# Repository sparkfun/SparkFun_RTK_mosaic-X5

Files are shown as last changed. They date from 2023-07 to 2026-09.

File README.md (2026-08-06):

SparkFun RTK mosaic-X5
========================================

SparkFun RTK mosaic-X5 (https://www.sparkpnt.com/products/sparkpnt-sxm-e-cors)

[*SparkFun RTK mosaic-X5 (SXM-E)*](https://www.sparkpnt.com/products/sparkpnt-sxm-e-cors)

Designed and manufactured in Boulder, Colorado, USA, the SparkFun RTK mosaic-X5 is the perfect solution for your high-precision positioning and navigation needs. Based around the multi-constellation, multi-frequency, L5-ready mosaic-X5 from Septentrio, this is our most advanced RTK product to date. It supports GNSS signals from GPS (USA), GLONASS (Russia), Beidou (China), Galileo (Europe), Navic (India) plus special additional satellites (e.g. SBAS and QZSS). The mosaic-X5 also has built-in on-module support for other L-band correction services.

The RTK mosaic-X5 can be configured as a Real Time Kinematic (RTK) Base, where it feeds corrections to other RTK Rovers, or as an RTK Rover where it can use corrections to achieve a horizontal positioning accuracy of 6 millimeters (0.6cm) (plus 0.5 PPM). For applications like robotics and autonomous systems, the mosaic-X5 can deliver position updates at 100Hz (100 times per second). The mosaic-X5 is a _very_ sophisticated chip running a full internal web page server; the position can be monitored and the module fully configured through that web page using a standard browser.

Under the hood, the RTK mosaic-X5 is based on the mosaic-X5 GNSS module from Septentrio, plus the Espressif ESP32-WROVER processor (16MB flash, 8MB PSRAM). The mosaic-X5 has USB-C connectivity (with Ethernet-over-USB), multiple UARTs and supports full Ethernet connectivity. The only interface it doesn't offer is WiFi and that's why we've included the ESP32 with its own Ethernet connection. You can connect the mosaic-X5 directly to your Ethernet network - our product supports Power-over-Ethernet too. Or you can link the mosaic-X5 Ethernet port to the ESP32 Ethernet port and have the ESP32 provide WiFi connectivity. In that mode, the ESP32 becomes an Ethernet to WiFi Bridge, seamlessly passing WiFi traffic to and from the mosaic-X5 via Ethernet.

Documentation
--------------

* **[Product Manual](http://docs.sparkfun.com/SparkFun_RTK_mosaic-X5/)** - Product manual for the RTK mosaic-X5 hosted by GitHub pages.<br>
   

*Need to download or print our hookup guide?*

* [Print *(Print to PDF)* from Single-Page View](http://docs.sparkfun.com/SparkFun_RTK_mosaic-X5/print_view)

Repository Contents
-------------------

* **[/docs](/docs/)** - Online documentation files
    * [assets](/docs/assets/) - Assets files
        * [board_files](/docs/assets/board_files/) - Files for the product design
            * [Schematic](/docs/assets/board_files/schematic.pdf) (.pdf)
            * [Dimensions](/docs/assets/board_files/dimensions.png) (.png)
            * [Eagle files](/docs/assets/board_files/eagle_files.zip) (.zip)
        * [img/hookup_guide/](/docs/assets/img/hookup_guide/) - Images for hookup guide documentation
* **[/Hardware](/Hardware/)** - Eagle design files (.brd, .sch)
* **[/Production](/Production/)** - PCB panel production files
* **[/Extruded_Case](/Extruded_Case/)** - Drawings and STEP file for the extruded case
* **[/Front_Panel](/Front_Panel/)** - Drawings and STEP file. Eagle design files (.brd, .sch) for the prototype (PCB) enclosure panel used to validate the dimensions
* **[/Rear_Panel](/Rear_Panel/)** - Drawings and STEP file. Eagle design files (.brd, .sch) for the prototype (PCB) enclosure panel used to validate the dimensions
* **[/Front_Sticker](/Front_Sticker/)** - DXF and PDF files for the front sticker
* **[/Rear_Sticker](/Rear_Sticker/)** - DXF and PDF files for the rear sticker
* **[/Firmware](/Firmware/)** - ESP IDF source code and binaries for the firmware which runs on the ESP32-WROVER
* **[/Test_Sketches](/Test_Sketches/)** - Additional code used to validate and test the RTK mosaic-X5
* **[/Documents](/Documents/)** - Component datasheets etc.

Product Variants
----------------

* [SXM-E](https://www.sparkpnt.com/products/sparkpnt-sxm-e-cors)- v1.0, Initial Release

Version History
---------------

* [v10](https://github.com/sparkfun/SparkFun_RTK_mosaic-X5/releases/tag/v10) - Initial Release

License Information
-------------------

This product is ***open source***!

Please review the [LICENSE.md](./LICENSE.md) file for license information.

If you have any questions or concerns about licensing, please contact technical support on our [SparkFun forums](https://community.sparkfun.com/).

Distributed as-is; no warranty is given.

- Your friends at SparkFun.

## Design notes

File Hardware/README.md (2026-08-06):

SparkFun RTK mosaic-X5 Design Files
=====================================

The .sch and .brd files here are Eagle CAD schematic and PCB design files from SparkFun Electronics.
A freeware version of Autodesk Eagle can be found [here](https://www.autodesk.com/products/eagle/free-download).

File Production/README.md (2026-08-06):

SparkFun RTK mosaic-X5 Production Files
=========================================

These are the production files SparkFun uses for printing PCBs.

License Information
-------------------
This product is open source!

The hardware is released under [Creative Commons ShareAlike 4.0 International](https://creativecommons.org/licenses/by-sa/4.0/).

Please use, reuse, and modify these files as you see fit. Please maintain attribution to SparkFun Electronics and release anything derivative under the same license.

Distributed as-is; no warranty is given.

- Your friends at SparkFun.

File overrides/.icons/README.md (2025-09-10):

.icons directory
====================
This folder should contain branding logos for the product documentation

## General Images
- `sfe.svg` - SparkFun flame logo
- `kicad-primary.svg` - Full KiCad logo

## Directory
- `logo` - Other available logos

## SVG Optimizer
- [Remove meta data from svg](https://jakearchibald.github.io/svgomg/)

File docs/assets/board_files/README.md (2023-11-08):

board_files directory
====================

1. A `dimensions.png` file containing the board's measurements.
2. A `schematic.pdf` file containing the board's schematics.

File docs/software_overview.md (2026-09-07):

---
icon: fontawesome/solid/computer
---

!!! code "ESP32 Firmware"
	We have intentionally kept the ESP32 firmware as simple as possible - supporting only two modes: Ethernet (mode **1**) and WiFi (mode **2**). The intention is that you can easily develop your own firmware for the RTK mosaic-X5 using the Espressif ESP IDF if the SparkFun firmware does not meet your needs.

	You can of course modify the hardware too, should you want to. The design is completely open-source.

	!!! warning "Limitations"
		The ESP32 firmware we provide is only compatible with basic `SSID` and `Password` WiFi authentication. The firmware is not compatible with networks that implement other provisioning methods such as a QR code or a [captive portal](https://en.wikipedia.org/wiki/Captive_portal).

!!! note
	The mosaic-X5 module has numerous capabilities and a multitude of ways to configure and interface with them. Without regurgitating all the information that is documented in Septentrio's user manuals and videos, we have tried to highlight a good majority of the module's aspects.

	With that said, please feel free to [file an issue](../github/file_issue/#discrepancies-in-the-documentation) if you feel we have missed something that may benefit other users. *(Don't forget to provide us with a link to the documentation and what section the information is located.)*

## :septentrio-logo:&nbsp;mosaic-X5

### RxTools Software Suite

!!! tip
	Even if you aren't necessarily interested in it, we highly recommend that users install the [RXTools software suite](https://www.septentrio.com/en/products/gps-gnss-receiver-software/rxtools) before plugging in their board. For Windows PCs, it also includes the USB driver for the module that enables the Ethernet-over-USB support and virtual `COM` ports.

Users should install the [RXTools software suite](https://www.septentrio.com/en/products/gps-gnss-receiver-software/rxtools) on their computer to interact with the mosaic-X5 module through the USB interface. The software package includes the USB-IP driver[^1] necessary to recognize the board as an ethernet device on Windows PCs (1).
{ .annotate }

1. On Linux, the standard Linux CDC-ACM driver is suitable.

[^1]: On Linux, the standard Linux CDC-ACM driver is suitable.

<article style="text-align: center;" markdown>
[:octicons-download-16:{ .heart } Download the RxTools Software from Septentrio](https://www.septentrio.com/en/products/gps-gnss-receiver-software/rxtools){ .md-button .md-button--primary target="blank" }
</article>

??? info "System Requirements[^2]"

	=== "Operating Systems"

		* Windows 7
		* Windows 8
		* Windows 10
		* Fedora 23 *(or later)* using Qt technology.
			* The standalone tools (except `bin2asc`) will run on older distributions.

	=== "Hardware Requirements"
		The minimal hardware requirements *(1Hz update[^3])*:

		* CPU: 1 GHz processor
		* RAM: 1 GB RAM
		* Screen Resolution: 1024×768 or higher resolution

	[^2]: The system requirements and installation instructions are from the RxTools *v22.1.0* user manual. This information may change in later iterations of the software suite. Please refer to the user manual *(of the version you are utilizing)* for the most accurate information.
	[^3]: Higher data rates will require higher CPU speed and more memory capacity.

??? info "Installation Instructions[^2]"

	=== "Windows"
		Users can install RxTools software suite by running the installation executable[^4](1), located in the `RxTools\windows` directory of the downloaded `*.zip` file[^5]. During the installation process, users will be notified if a previous version of RxTools is already installed then the previous version will be uninstalled. Next, users will need to provide an installation directory for the RxTools software suite. Users will then select which of the following applications[^6] are installed:
		{ .annotate }

		1. For RxTools v22.1.0, the installation filename is `RxTools_22_1_0_Installer.exe` for Windows PCs.

		<!-- Create Break from Annotation (list won't render without comment)-->

		<div class="grid" markdown>

		<div markdown>

		* RxControl
		* SBF Converter
		* SBF Analyzer
		* RxLogger

		</div>

		<div markdown>

		* RxUpgrade
		* RxDownload
		* RxPlanner

		</div>

		<div markdown>

		* Data Link
		* RxAssistant
		* RxLauncher

		</div>

		</div>

	=== "Linux[^1]"
		!!! warning
			It is recommended that users **<span style="color:red">NOT</span>** install RxControl as `root`, for security reasons and to avoid installation overwrites of other system settings. To make RxTools available to more than one user, provide a shared installation directory.

		Users can install RxTools software suite by running the installation binary[^4](1), located in the `RxTools/linux-i386/` directory of the downloaded `*.zip` file[^5]. During the installation, users will be prompted for an installation directory. If there are any previous installations of RxControl, please use a different directory to avoid conflicts.
		{ .annotate }

		1. For RxTools v22.1.0, the installation filename is `RxTools_22_1_0_Installer.bin` for Linux.

		??? info "Permission Settings"
			Once installed, users may need to reconfigure their permission settings:

			<div class="annotate" markdown>

			* RxTools will need rights to access the `/dev/ttyS*` serial ports.

				* To access the serial ports, users must be part of the `uucp` and `lock` groups (1). This can be configured by editing the `/etc/group`[^7] file and adding the username to the lines defining the `uucp` group and the `lock` group.

					For example, when adding the user `jsmith` to the `uucp` group, users would modify the `/etc/group` file as shown below:

					```bash
					{--uucp:x:14:uucp--} # (2)!
					{++uucp:x:14:uucp,jsmith++} # (3)!
					```

				* On Linux machine administered centrally on a local network, ask your system administrator to be included in the `uucp` and `lock` groups.
			* RxTools also needs read/write (`rw`) access(4) to the `/dev/ttyS*` serial ports.

				* Users can change the permissions with the `chmod`[^8] command:

					```bash
					chmod 660 /dev/ttyS<add port> # (5)!>
					```

			</div>

			1. On most Linux operating systems, the `/dev/ttyS*` devices are owned by `root` and belong to the `uucp` group with read/write (`rw`) access. Additionally, the devices are normally locked by writing a file in the `/var/lock/` directory, with the same permissions.
			2. Remove
			3. Replace with this line
			4. By default, users will normally have read/write (`rw`) access to the `/dev/ttyS*` serial ports.
			5. where users must specify the port number<br>*e.g. `/dev/ttyS0` might be port `COM1`*

			!!! note
				In order for these changes to take effect, users must update their environment by logging out and back in.

				Be aware that the X-session has to be restarted as well. On most systems, this can be done by pressing the key combination ++ctrl++ + ++alt++ + ++backspace++

		??? info "64-bit OS"
			In order to run the RxTools on a 64-bit Linux operating system, users might have to install the 32-bit version of the `C` standard library.

			* For Fedora installations, this is the `glibc.i686` package.
			* The equivalent for Debian(/Ubuntu) installations is the `ia32-libs` package.

	[^4]: Users will need administrative privileges to install the RxTools software.
	[^5]: Users may need to extract the RxTools installation files from the downloaded, compressed file.
	[^6]: Please see the release notes for the issues and limitations of the RxTools applications.
	[^7]: Requires c privileges.
	[^8]: Changing these permissions also requires `root` privileges.

### USB Driver
=== "Windows"
	If users haven't already installed the [RxTools software suite](https://www.septentrio.com/en/products/gps-gnss-receiver-software/rxtools) on their Windows PC, they will need to install the USB driver[^1] necessary to recognize and interact with the mosaic-X5 module through the USB interface.

	A Windows USB driver for the mosaic-X5 can be installed through two methods:

	<div class="annotate" markdown>

	* RxTools Software Suite (1)
	* mosaic-X5 GNSS Receiver Module (2)

	</div>

	1. The driver is installed during the installation process.
	2. The installation file for the Windows USB driver will be available from the mass-storage device when the board is initially connected to the computer.

	Once installed, the driver emulates two virtual serial ports, which can be accessed as standard `COM` ports to the receiver.

	??? tip "Terminal Emulators"
		Most [terminal emulation programs](https://learn.sparkfun.com/tutorials/112) will not make a distinction between virtual or native COM ports. However, for virtual serial ports, the port settings *(i.e. baud rate, etc.)* are not relevant and the default configuration is used in the terminal emulation program. However, the physical/native `COM` ports will have the following default setting:

		* Baudrate: 115200bps
		* Data Bits: 8
		* Parity: No
		* Stop Bits: 1
		* Flow Control: None

	??? tip "Having Trouble?"
		For users who are having trouble installing the USB driver, we have an archived version *(v3.0.2[^9])* of the installation file. Users can download [**version 3.0.2**](https://docs.sparkfun.com/SparkFun_GNSS_mosaic-X5/assets/component_documentation/driver/USB_driver_3_0_2_Installer.exe) of the driver, by clicking on the button below.

		[^9]:
			For the latest USB driver from Septentrio, please install their driver through the [RxTools software suite](../rxtools).<br>
			*This driver version was archived at the time that the [mosaic-X5 hookup guide](https://docs.sparkfun.com/SparkFun_GNSS_mosaic-X5/) was written. Please do not request for the file to be updated.*

		<article style="text-align: center;" markdown>
		[:octicons-download-16:{ .heart } Download USB Driver *(v3.0.2)*](https://docs.sparkfun.com/SparkFun_GNSS_mosaic-X5/assets/component_documentation/driver/USB_driver_3_0_2_Installer.exe){ .md-button .md-button--primary target="blank" }
		</article>

=== "Linux"
	On Linux, the standard Linux CDC-ACM driver is suitable for the mosaic-X5 module.

### Web Interface
With the USB driver installed, the mosaic-X5 module supports Ethernet-over-USB. The default IP address allocated for the Ethernet-over-USB interface is `192.168.3.1`. This IP can be entered in any browser to open a connection to the receiver's Web Interface as shown below.

<div class="grid" markdown>

<div markdown>

<figure markdown>
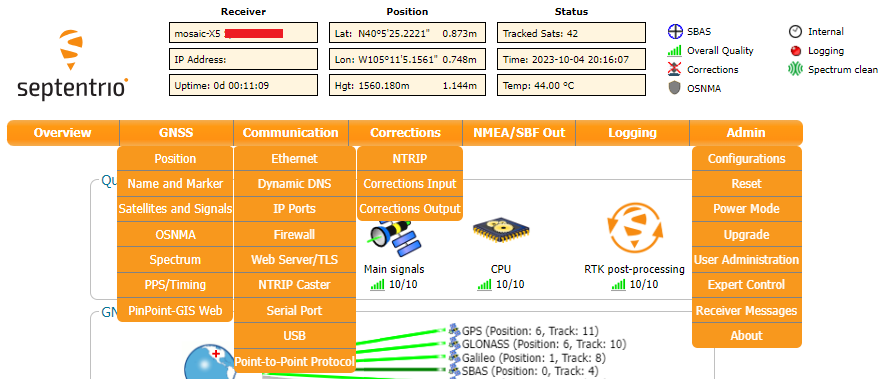
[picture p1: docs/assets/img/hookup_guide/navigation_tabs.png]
navigation tabs in the web interface

<figcaption markdown>All the drop-down navigation tabs in the web interface.</figcaption>
</figure>

</div>

<div markdown>

<article style="text-align: center;" markdown>
<article class="video-500px">
<iframe src="https://www.youtube.com/embed/hrL5J6Q5gX8" title="Septentrio: Getting started with the Septentrio mosaic receiver module" frameborder="0" allow="accelerometer; autoplay; clipboard-write; encrypted-media; gyroscope; picture-in-picture" allowfullscreen></iframe>
</article>
</article>

</div>

</div>

!!! info
	The default IP address cannot be changed; this feature is only to be used when a single receiver is connected to your computer.

??? failure "Invalid IP Address *(WiFi Only)*"
	[One of the documentation pages on Septentrio's website](https://customersupport.septentrio.com/s/article/What-is-the-default-IP-address-to-connect-via-WiFi), specifies a default IP address of `192.168.20.1` for the web interface. However, that address is for a WiFi enabled product and cannot be used with this product.

## :espressif-logo:&nbsp;ESP32

### USB Driver
Users will need to install a USB driver for the CH340 serial-to-USB chip, in order to communicate with the ESP32 module.	The latest USB drivers for the CH340 are available from the manufacturer, on the [WCH website](https://www.wch-ic.com/products/CH340.html?):

<article style="text-align: center;" markdown>
[:octicons-download-16:{ .heart } Download the latest CH340 USB driver from WCH](https://www.wch-ic.com/products/CH340.html?){ .md-button .md-button--primary target="blank" }
</article>

??? abstract "Need Directions?"
	For users having trouble installing the CH340 USB driver, check out our video and hookup guide:

	<div class="grid" markdown align="center">

	<div markdown>

	<div class="video-500px">
	<iframe src="https://www.youtube.com/embed/MM9Fj6bwHLk" title="Tutorial: Installing CH340 Drivers" frameborder="0" allow="accelerometer; autoplay; clipboard-write; encrypted-media; gyroscope; picture-in-picture" allowfullscreen></iframe>
	</div>

	</div>

	<div class="grid cards" markdown>

	-   <a href="https://learn.sparkfun.com/tutorials/908">
		<figure markdown>
		Tutorial Thumbnail
		</figure>

		---

		**How to Install CH340 Drivers**</a>

	</div>

	</div>

### Terminal Emulator
In order to configure the WiFi settings on the ESP32, users will need to install a [serial terminal emulator](https://learn.sparkfun.com/tutorials/terminal-basics) on their computer.

=== "Windows"
	For Windows computers, we highly recommend [TeraTerm](https://teratermproject.github.io/index-en.html).

=== "Linux"
	Some Linux operating systems will already have the `screen` terminal emulator preinstalled.

!!! abstract "Need Directions?"
	Check out our hookup guide to install your favorite terminal emulator:

	<div class="grid cards" markdown align="center">

	-   <a href="https://learn.sparkfun.com/tutorials/112">
		<figure markdown>
		Tutorial Thumbnail
		</figure>

		---

		**Serial Terminal Basics**</a>

	</div>

### WiFi Credentials for the Network Bridge
With the CH340 USB driver and a terminal emulator installed, users will now be able to configure the WiFi credentials on the ESP32. In order for the firmware to operate properly, users should have their RTK mosaic-X5 assembled with the network bridge in *WiFi Mode*.

--8<-- "./docs/quick_start.md:135:138"

`1` - **Open a Serial Terminal**
: Open the connection to the CH340 using a baud rate of **115200bps**

`2` - **Put the ESP32 firmware into WiFi mode**
--8<-- "./docs/quick_start.md:181:252"

Once the mosaic-X5 has acquired a satellite signal and is connected to the WiFi network, the OLED will display the antenna's position as Latitude (Lat), Longitude (Long) and Altitude (Alt); the WiFi IP (Internet Protocol) network address. The firmware mode, SSID and password are stored in flash (non-volatile) memory. After changing them, you can disconnect the computer and power the RTK mosaic-X5 using the supplied wall adapter.

--8<-- "./docs/quick_start.md:263:266"

!!! info
	When powering the RTK mosaic-X5 on for the first time, you may see the firmware restart (reboot) several times while it waits for the mosaic-X5 to initialize. This is not an error or anything to be concerned about.

With the RTK mosaic-X5 operating with the configured WiFi network bridge, users should be able to open a web browser on any connected device and navigate to the IP address shown on the OLED display. The browser should be able to access the mosaic-X5's internal web page, where users can configure the mosaic-X5.

### ESP32 Firmware - Update

The firmware running on the ESP32 is based heavily on the firmware for the [Septentrio mowi](https://github.com/septentrio-gnss/mowi). SparkFun added some bells and whistles, primarily to support the OLED display. The full firmware source code is available in the [GitHub repo](https://github.com/sparkfun/SparkFun_RTK_mosaic-X5/tree/main/Firmware/RTK_mosaic-X5_Firmware). It was developed and compiled with the Espressif ESP-IDF version 5.1.7.

The most recent version of the firmware is v1.0.6, released on September 7th 2026. If you purchased your RTK mosaic-X5 before this date, you may enjoy the improvements in v1.0.6. Please see the [change_log](./change_log.md) or [releases](https://github.com/sparkfun/SparkFun_RTK_mosaic-X5/releases) for more details.

To upgrade the ESP32 firmware, using a Windows PC:

* Download the complete RTK mosaic-X5 repo as a Zip file:
    * [https://github.com/sparkfun/SparkFun_RTK_mosaic-X5/archive/refs/heads/main.zip](https://github.com/sparkfun/SparkFun_RTK_mosaic-X5/archive/refs/heads/main.zip)
* Alternatively, download the latest or a previous release (*Source code zip*) from the [repo releases page](https://github.com/sparkfun/SparkFun_RTK_mosaic-X5/releases)
* Unzip the Zip file (Extract All)
* Open a *Command Prompt* and navigate into the *Firmware* sub-folder
* Connect the RTK mosaic-X5 “CONFIG ESP32” port to your PC using a USB-C cable
    * It should appear in Device Manager as a CH340 COM port
* Run *ESP32_FLASH_ERASE.bat* to completely clear the ESP32 memory
    * The .bat file should find the COM port number for you
	* If you see the error ```'wmic' is not recognized as an internal or external command, operable program or batch file```, you will need to [install WMIC](https://techcommunity.microsoft.com/blog/windows-itpro-blog/how-to-install-wmic-feature-on-demand-on-windows-11/4189530) or provide the COM port manually:

```
ESP32_FLASH_ERASE.bat COM1
```

* If you need to run `esptool` manually, use the following replacing COM1 with your COM port:

```
esptool.exe --chip esp32 -p COM1 -b 460800 erase_flash
```

* Then run *ESP32_FLASHER.bat* to upload the firmware
	* The .bat file should find the COM port number for you
	* If you see the error ```'wmic' is not recognized as an internal or external command, operable program or batch file```, you will need to [install WMIC](https://techcommunity.microsoft.com/blog/windows-itpro-blog/how-to-install-wmic-feature-on-demand-on-windows-11/4189530) or provide the COM port manually:

```
ESP32_FLASHER.bat COM1
```

* If you need to run `esptool` manually, use:

```
esptool.exe --chip esp32 -p COM1 -b 460800 --before=default_reset --after=hard_reset write_flash --flash_mode dio --flash_freq 40m --flash_size 4MB 0x1000 RTK_mosaic-X5_Firmware\build\bootloader\bootloader.bin 0x10000 RTK_mosaic-X5_Firmware\build\RTK_mosaic-X5_Firmware.bin 0x8000 RTK_mosaic-X5_Firmware\build\partition_table\partition-table.bin
```

On Linux / MacOS, you can `pip install esptool` and then run the above commnds, replacing `esptool.exe` with `esptool`

### ESP32 Firmware - Compiling from source

This is information about how to compile the RTK mosaic-X5 firmware from source. This is for advanced users who would like to modify the functionality of this RTK product.

* [How SparkFun does it](#how-sparkfun-does-it)
* [Using Docker](#using-docker)

### How SparkFun does it

At SparkFun, we use GitHub Actions and a Workflow to compile each release of the RTK mosaic-X5 firmware. We run the [build-for-release workflow](https://github.com/sparkfun/SparkFun_RTK_mosaic-X5/blob/main/.github/workflows/build-for-release.yml) directly on GitHub. A virtual ubuntu machine installs the Espressif IDF and generates the firmware binary for the ESP32. The updated firmware, bootloader and partition-table .bin files are pushed to the repo. We then create the new release manually.

You are welcome to clone or fork this repo and do the exact same thing yourself. But you may need a paid GitHub Pro account to run the GitHub Actions, especially if you keep your clone / fork private.

The [non-release-build workflow](https://github.com/sparkfun/SparkFun_RTK_mosaic-X5/blob/main/.github/workflows/non-release-build.yml) builds the firmware binaries and attaches them as an Artifact to the workflow run. Navigate to Actions \ Non-Release Build, select the latest run of Non-Release Build, the binary files are in the Artifact. This may be useful if you want to build the firmware on GitHub but don't want the changes pushed to your repo.

You can then use (e.g.) [ESP32_FLASHER.bat](https://github.com/sparkfun/SparkFun_RTK_mosaic-X5/blob/main/Firmware/ESP32_FLASHER.bat) to upload the binary onto the ESP32.

### Using Docker

Here is a step-by-step guide for how to install Docker and compile the firmware locally from scratch:

#### Clone, fork or download the RTK mosaic-X5 repo

To build the RTK mosaic-X5 firmware, you obviously need a copy of the source code.

If you are familiar with Git and GitHub Desktop, you can clone the RTK mosaic-X5 repo directly into GitHub Desktop:

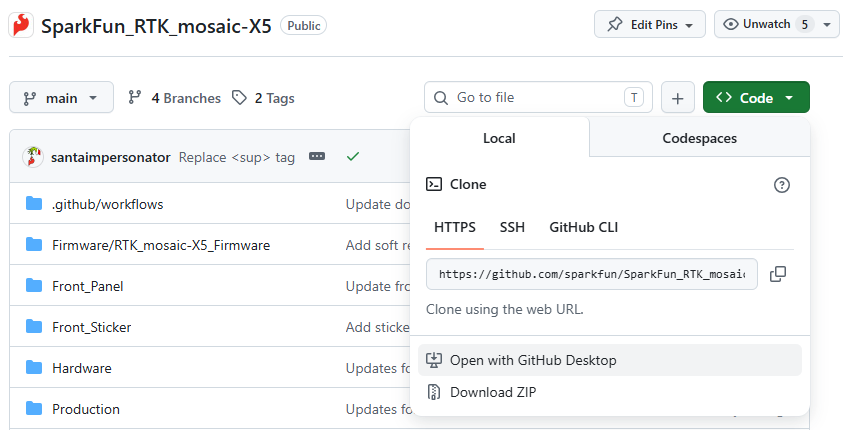
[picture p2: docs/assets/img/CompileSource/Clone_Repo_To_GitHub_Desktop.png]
Clone RTK mosaic-X5 with GitHub Desktop


If you want to _contribute_ to RTK Everywhere, and already have a GitHub account, you can Fork the repo:

Fork RTK Everywhere

Clone your fork to your local machine, make changes, and send us a Pull Request. This is exactly what the SparkFun Team do when developing the code. Please use the `release_candidate` branch for any such changes. We are very unlikely to merge anything directly into `main`, unless it is (e.g.) docs corrections or improvements.

If you don't want to do either of those, you can simply Download a Zip copy of the repo instead. You will receive a complete copy as a Zip file. You can do this from the green **Code** button, or click on the icon below to download a copy of the main (released) branch:

Download ZIP (https://github.com/sparkfun/SparkFun_RTK_mosaic-X5/archive/refs/heads/main.zip "Download ZIP (main branch)")

For the real Wild West experience, you can also download a copy of the `release_candidate` code branch. This is where the team is actively changing and testing the code, before it becomes a full release. The code there will _usually_ compile and will _usually_ work, but we don't guarantee it! We may be part way through implementing some breaking changes at the time of your download...

Download ZIP - release candidate (https://github.com/sparkfun/SparkFun_RTK_mosaic-X5/archive/refs/heads/release_candidate.zip "Download ZIP (release_candidate branch)")

#### Install Docker Desktop

* **(Optional)** Head to [Docker](https://www.docker.com/) and create an account. A free "Personal" account will cover occasional compilations of the firmware
* Download and install [Docker Desktop](https://docs.docker.com/get-started/get-docker/) - there are versions for Mac, Windows and Linux. You may need to restart to complete the installation.
* Run the Desktop
    * You don't _need_ to have an account and you don't _need_ to be signed in
    * You only need to be signed in if you want to store or share your Container on Docker Hub
    * If you don't sign in, Docker Desktop will run in Personal mode - which will cover local compilations of the firmware
* On Windows, you may see an error saying "**WSL needs updating** Your version of Windows Subsystem for Linux (WSL) is too old". If you do:
    * Open a command prompt
	* Type `wsl --update` to update WSL. At the time of writing, this installs Windows Subsystem for Linux 2.6.1
	* Restart the Docker Desktop
* If you are using Docker for the first time, the "What is a container?" and "How do I run a container?" demos are useful - _but not essential_
    * On Windows, you may want to give Docker Desktop permission to access to your Network, so it can access (e.g.) HTML ports
	* You can Stop the container and Delete it when you are done
* You may want to prevent Docker from running when your machine starts up
    * Uncheck "Start Docker Desktop when you sign in to your computer" in the Desktop settings

#### Using Docker to create the firmware binary

* **Make sure you have Docker Desktop running.** You don't need to be signed in, but it needs to be running.
* Open a Command Prompt and `cd` into the SparkFun_RTK_mosaic-X5 folder
* Check you are in the right place. Type `dir` and hit enter. You should see the following files and folders:

```
    .gitattributes
    .gitignore
    CONTRIBUTING.md
    ISSUE_TEMPLATE.md
    LICENSE.md
	mkdocs.yml
    README.md
```

* `cd Firmware` and then `dir` again. You should see:

```
    RTK_mosaic-X5_Firmware
	compile_run_terminal.bat
	compile_with_docker.bat
    Dockerfile
    ESP32_FLASH_ERASE.bat
    ESP32_FLASHER.bat
    esptool.exe
```

* The file that does most of the work is the `Dockerfile`

* Run `compile_with_docker.bat`. It does everything for you:

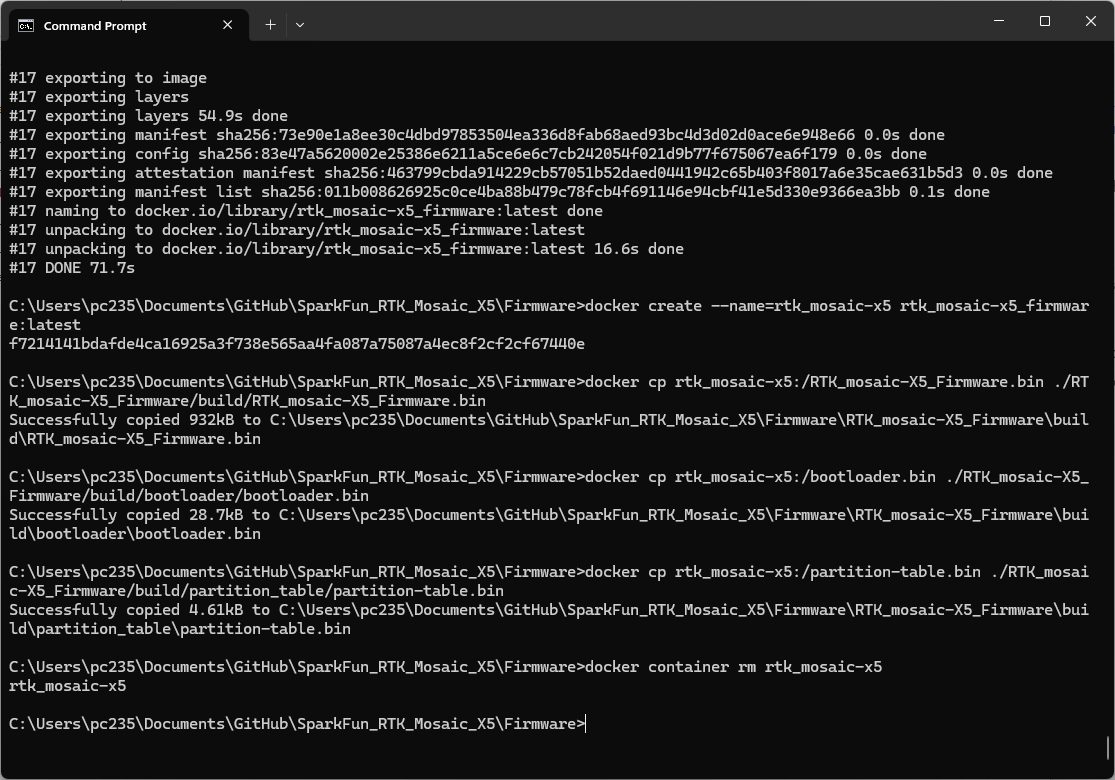
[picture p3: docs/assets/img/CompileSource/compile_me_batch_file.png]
Output of the compile batch file


* Hey presto! You have your newly compiled firmware binary!
* The three new files are:
	* **RTK_mosaic-X5_Firmware\build\RTK_mosaic-X5_Firmware.bin**
	* **RTK_mosaic-X5_Firmware\build\bootloader\bootloader.bin**
	* **RTK_mosaic-X5_Firmware\build\partition_table\partition-table.bin**

You can then use (e.g.) [ESP32_FLASHER.bat](https://github.com/sparkfun/SparkFun_RTK_mosaic-X5/blob/main/Firmware/ESP32_FLASHER.bat) to upload the binary onto the ESP32.

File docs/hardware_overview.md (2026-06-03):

---
icon: material/cog
---

!!! warning "Read Before Handling PCB!"
	!!! danger "ESD Sensitivity"
		The mosaic-X5 module is sensitive to [ESD](https://en.wikipedia.org/wiki/Electrostatic_discharge "Electrostatic Discharge"). Use a proper grounding system to make sure that the working surface and the components are at the same electric potential.

	??? info "ESD Precaution"
		As recommended by the manufacturer, we highly encourage users to take the necessary precautions to avoid damaging their module.

		- The RTK mosaic-X5 features ESD protection on the USB-C connectors and ethernet jacks.
		- The mosaic-X5 module features internal ESD protection to the `ANT_1` antenna input.

		<div class="grid cards" markdown>

		<div markdown>

		<article style="text-align: center;" markdown>
		<article class="video-500px">
		<iframe src="https://www.youtube.com/embed/hrL5J6Q5gX8?si=jOPBat8rzMnL7Uz4&amp;start=26;&amp;end=35;" title="Septentrio: Getting Started Video (playback starts at ESD warning)" frameborder="0" allow="accelerometer; autoplay; clipboard-write; encrypted-media; gyroscope; picture-in-picture" allowfullscreen></iframe>
		</article>
		</article>

		</div>

		-   <a href="https://www.sparkfun.com/ifixit-anti-static-wrist-strap.html">
			<figure markdown>
			Product Thumbnail
			</figure>		

			---

			**iFixit Anti-Static Wrist Strap**<br>
			TOL-25572</a>

		</div>

!!! code "ESP32 Firmware"
	We have intentionally kept the ESP32 firmware as simple as possible - supporting only two modes: Ethernet *(**Mode: `1`**)* and WiFi *(**Mode: `2`**)*. The intention is that you can easily develop your own firmware for the RTK mosaic-X5 using the Espressif ESP IDF if the SparkFun firmware does not meet your needs.

	You can of course modify the hardware too, should you want to. The design is completely open-source.

	!!! warning "Limitations"
		The ESP32 firmware we provide is only compatible with basic `SSID` and `Password` WiFi authentication. The firmware is not compatible with networks that implement other provisioning methods such as a [captive portal](https://en.wikipedia.org/wiki/Captive_portal), a QR code, or [Wi-Fi protected setup](https://en.wikipedia.org/wiki/Wi-Fi_Protected_Setup "WPS").

# Hardware Overview

In this section, we walk you through the hardware design, interfaces, I/O connections, power options and more.

!!! info
	The RTK mosaic-X5 is inspired by the [Septentrio mowi (mosaic wireless) open-source design](https://github.com/septentrio-gnss/mowi). The SparkFun design builds upon [mowi](https://github.com/septentrio-gnss/mowi "mosaic wireless"), adding: separate Ethernet ports with mag jacks and Power-over-Ethernet; robust I/O headers with screw cage connections and configurable I/O voltage (3.3V or 5V); &micro;SD data storage; and an OLED display.

## Schematic
Users can download the [full schematic for the RTK mosaic-X5](./assets/board_files/schematic.pdf) in `*.pdf` format.

## Dimensions

=== ":material-package-variant-closed: Metal Enclosure"
	Details about the aluminum enclosure can be found on the [Metal Enclosure - Custom Aluminum Extrusion (6in. x 4in. PCB)](https://www.sparkfun.com/metal-enclosure-custom-aluminum-extrusion-6in-x-4in-pcb.html) product page.

	<figure markdown>
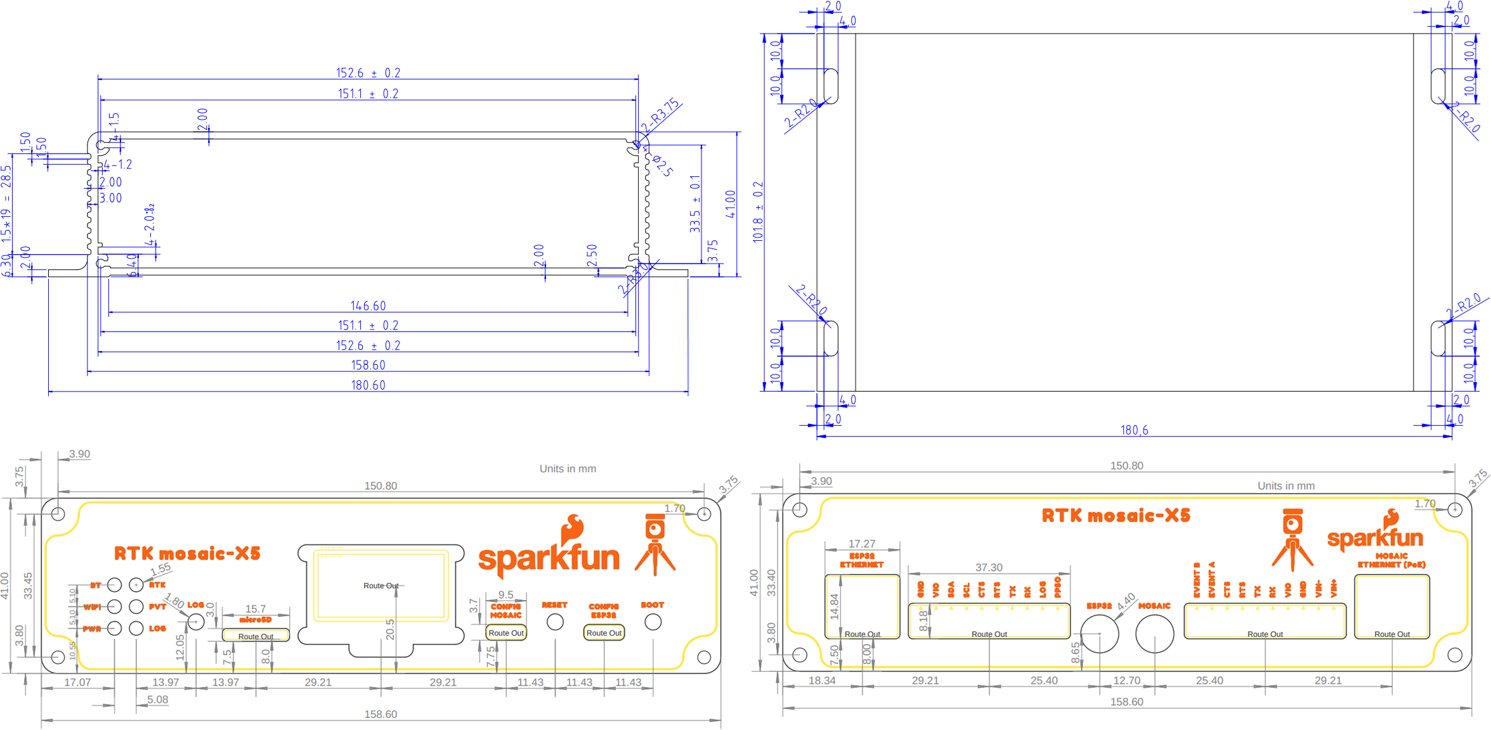
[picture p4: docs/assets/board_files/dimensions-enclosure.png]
Enclosure Dimensions
	
	<figcaption markdown>[Dimensions (PDF)](./assets/board_files/dimensions-enclosure.pdf) of the RTK mosaic-X5 aluminum enclosure and the front/rear panels, in millimeters.</figcaption>
	</figure>

=== ":fontawesome-solid-microchip: Printed Circuit Board"
	The circuit board dimensions are illustrated in the drawing below; the listed measurements are in inches.

	<figure markdown>
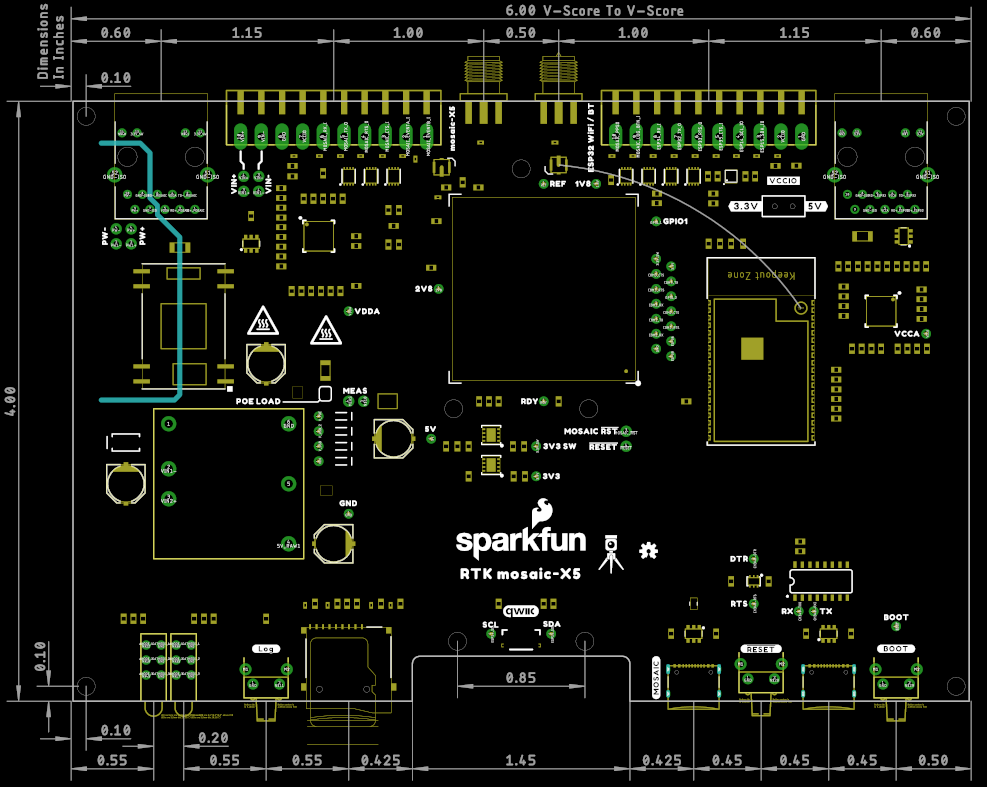
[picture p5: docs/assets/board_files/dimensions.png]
Board Dimensions
	
	<figcaption markdown>[Dimensions (PDF)](./assets/board_files/dimensions.pdf) of the RTK mosaic-X5 PCB, in inches.</figcaption>
	</figure>

	??? tip "Need more measurements?"
		For more information about the board's dimensions, users can download the [**Eagle files**](./assets/board_files/eagle_files.zip) for the board. These files can be opened in Eagle and additional measurements can be made with the dimensions tool.

		??? info ":octicons-download-16:{ .heart } Eagle - Free Download!"
			Eagle is a [CAD]("computer-aided design") program for electronics that is free to use for hobbyists and students. However, it does require an account registration to utilize the software.

			<article style="text-align: center;" markdown>
			[Download from<br>:autodesk-primary:{ .autodesk }](https://www.autodesk.com/products/eagle/free-download "Go to downloads page"){ .md-button .md-button--primary width="250px" }
			</article>

		??? info ":straight_ruler: Dimensions Tool"
			This video from Autodesk demonstrates how to utilize the dimensions tool in Eagle, to include additional measurements:

			<article style="text-align: center;" markdown>
			<div class="video-500px">
			<iframe src="https://www.youtube.com/embed/dZLNd1FtNB8" title="EAGLE Dimension Tool" frameborder="0" allow="accelerometer; autoplay; clipboard-write; encrypted-media; gyroscope; picture-in-picture" allowfullscreen></iframe>
			</article>

=== ":material-video-input-antenna: Antenna"
	The dimensions and technical specifications of the GNSS antenna can be found on the [GNSS Multi-Band L1/L2/L5 Surveying Antenna - TNC (SPK6618H)](https://www.sparkfun.com/gnss-multi-band-l1-l2-l5-surveying-antenna-tnc-spk6618h.html) product page.

	<figure markdown>
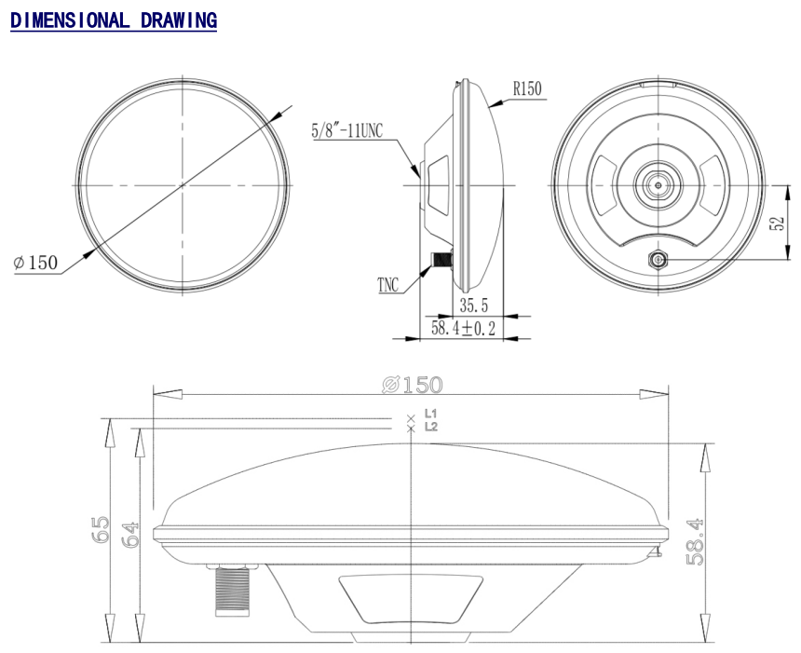
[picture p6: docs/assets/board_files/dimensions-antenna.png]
Antenna Dimensions
	
	<figcaption markdown>Dimensions of the included GNSS antenna, in mm.<br>
	Source: [SPK6618H Datasheet (PDF)](https://cdn.sparkfun.com/assets/f/f/5/1/7/SparkFun_SPK6618H_Datasheet.pdf)</figcaption>
	</figure>

## Power Options
The mosaic-X5 and the ESP32 both required 3.3V power. To simplify the power circuitry, the four power sources are combined into a common 5V rail which then feeds individual 3.3V 1A regulators for the mosaic-X5 and the ESP32.

<figure markdown>
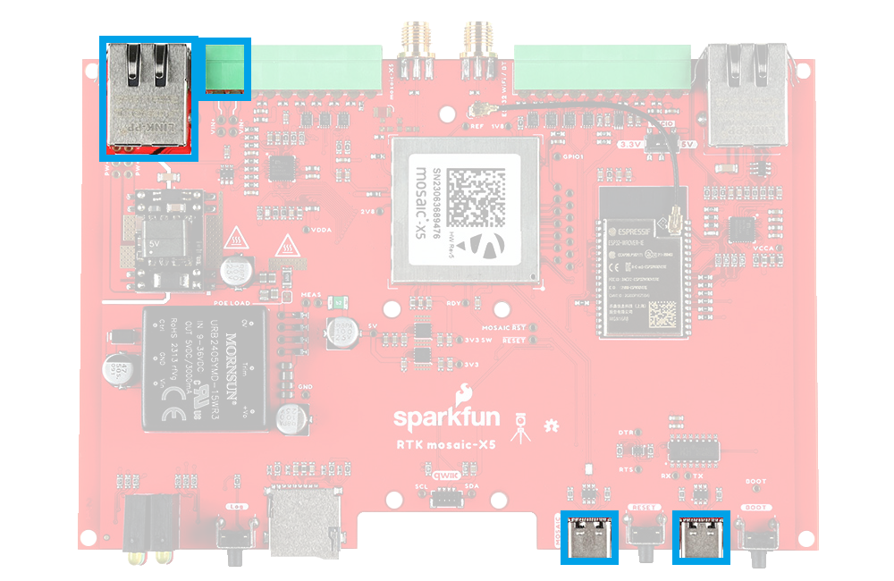
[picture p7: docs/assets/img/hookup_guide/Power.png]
Power connections

<figcaption markdown>Power connections on the RTK mosaic-X5 PCB.</figcaption>
</figure>

The RTK mosaic-X5 can be powered individually or in combination, with any of the following:

* **`USB Ports`** - **5V**; delivered via the `MOSAIC CONFIG` and/or `ESP32 CONFIG` USB-C connectors.
* **`Power-over-Ethernet`** - **Range: 36 to 57V**; delivered via the `MOSAIC ETHERNET` RJ45 MagJack connector.
* **`External DC Power`** - **Range: 9 to 36V**; delivered via the `VIN+` and `VIN-` screw cage terminals.

??? tip "Measure Current Draw"
	If you want to measure the board's current draw, you can open the `MEAS` jumper and measure the current via a pair of breakout pads *(see the **[Jumpers](#jumpers)** section)*.

??? info "Protection Components"
	Diodes are used to combine and protect the power sources from each other. Also, a 2A resettable fuse (green) provides additional protection.

!!! info
	For more details, users can reference the [schematic](./assets/board_files/schematic.pdf) and the datasheets of the individual components on the board.

=== ":material-usb-port: USB-C Connectors"
	The mosaic-X5 and ESP32 both have USB-C connections. These USB ports can be used to power the RTK mosaic-X5 during the initial configuration when the mosaic-X5 or ESP32 are connected to a computer.

	<div class="grid" markdown>

	<div markdown>

	<figure markdown>
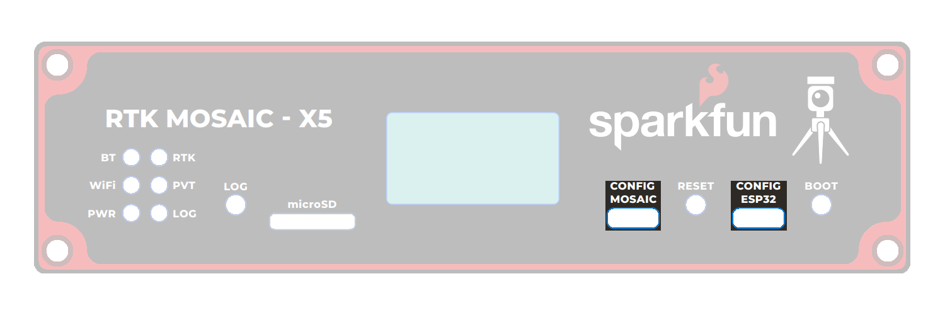
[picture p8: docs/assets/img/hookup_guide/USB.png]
USB-C Connectors
	
	<figcaption markdown>USB-C connectors on the RTK mosaic-X5.</figcaption>
	</figure>

	</div>

	<div markdown>

	<figure markdown>
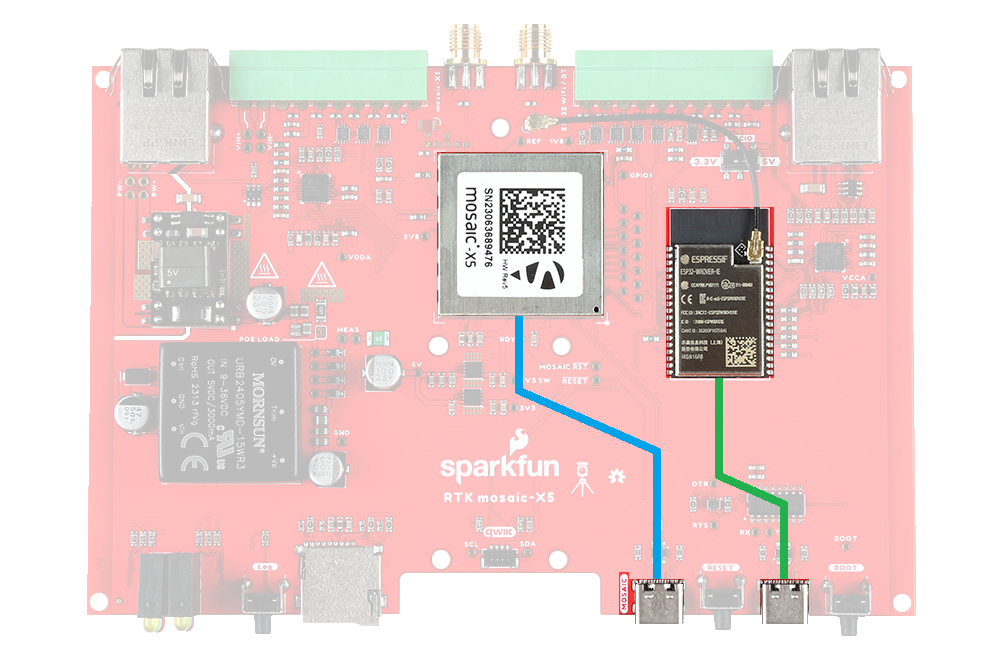
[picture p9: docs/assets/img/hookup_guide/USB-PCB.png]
USB-C Power Connections
	
	<figcaption markdown>The USB-C device connections on the RTK mosaic-X5 PCB.</figcaption>
	</figure>

	</div>

	</div>

	!!! info "CH340 Driver"
		The CH340 allows the ESP32-WROVER to communicate with a computer/host device through the USB-C connection. This allows the ESP32 to show up as a device on the serial (or COM) port of the computer. Users will need to install the latest drivers for the computer to recognize the CH340 *(see **[USB Driver](../software_overview/#espressif-logoesp32)** section)*.

=== ":material-ethernet: Power-over-Ethernet (PoE)"
	The mosaic-X5 Ethernet port supports Power-over-Ethernet ([PoE](https://en.wikipedia.org/wiki/Power_over_Ethernet "Power Over Ethernet")), allowing the RTK mosaic-X5 to be powered by the network. This is very useful when the RTK mosaic-X5 is mounted remotely - perhaps in a weatherproof box up on the roof. Data and power can be delivered through a single cable, avoiding the need for a separate power connection.

	<div class="grid" markdown>

	<div markdown>

	<figure markdown>
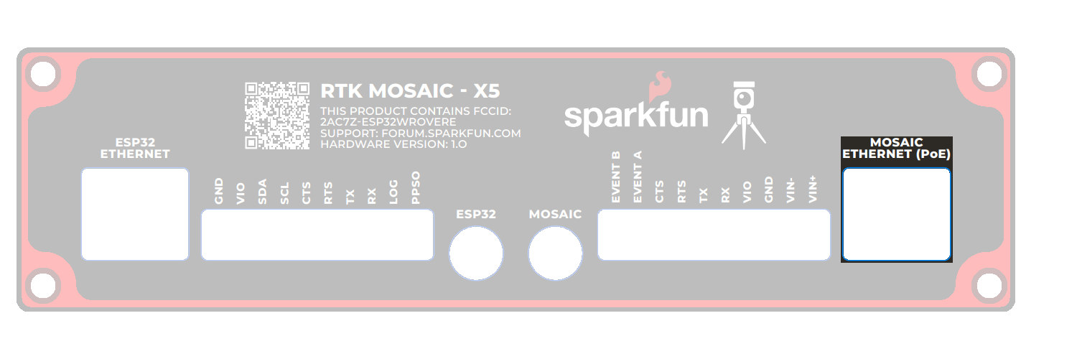
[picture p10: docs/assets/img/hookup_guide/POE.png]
Power over Ethernet Jack
	
	<figcaption markdown>The Power-over-Ethernet (PoE) jack on the RTK mosaic-X5.</figcaption>
	</figure>

	</div>

	<div markdown>

	<figure markdown>
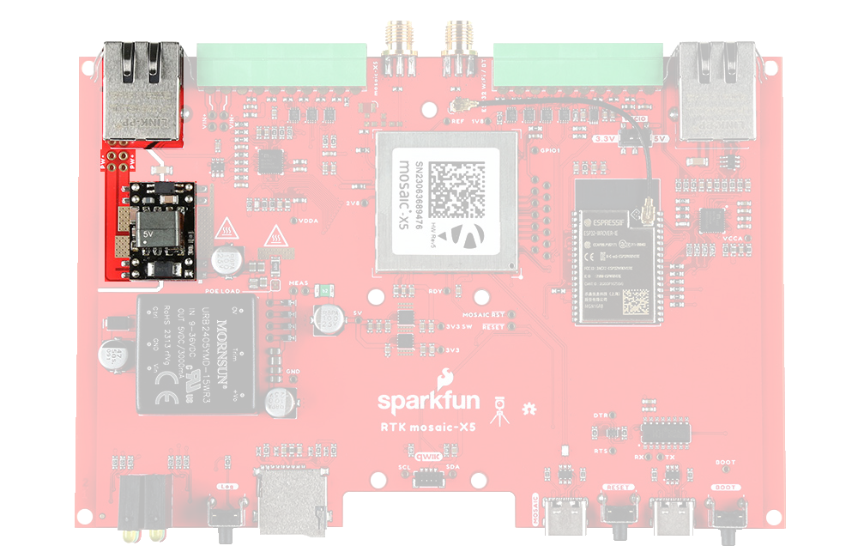
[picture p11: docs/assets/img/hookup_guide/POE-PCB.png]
Power over Ethernet Circuit
	
	<figcaption markdown>The PoE power input circuit on the RTK mosaic-X5 PCB.</figcaption>
	</figure>

	</div>

	</div>

=== ":material-car-battery: External DC Power (VIN)"
	The RTK mosaic-X5 includes a fully-isolated DC-DC converter, for applications where you may want to power the unit from a vehicle. The DC-DC converter accepts DC voltages between **9V and 36V**, regulating this down to 5V. The converter is fully isolated to 1.5kV and operates with ~90% efficiency.

	<div class="grid" markdown>

	<div markdown>

	<figure markdown>
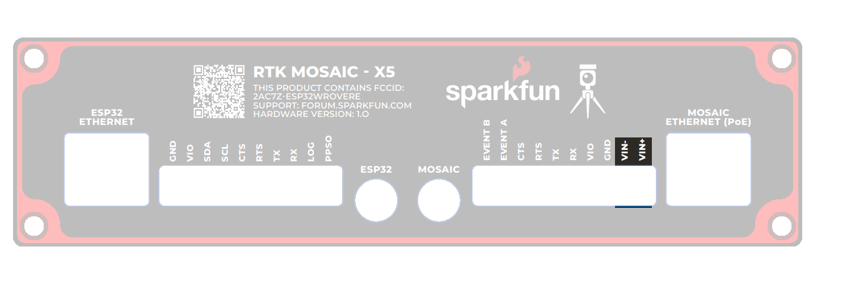
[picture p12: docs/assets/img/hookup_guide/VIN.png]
External Power Screw Terminal
	
	<figcaption markdown>The `VIN+` and `VIN-` screw terminal pins for the external DC power input.</figcaption>
	</figure>

	</div>

	<div markdown>

	<figure markdown>
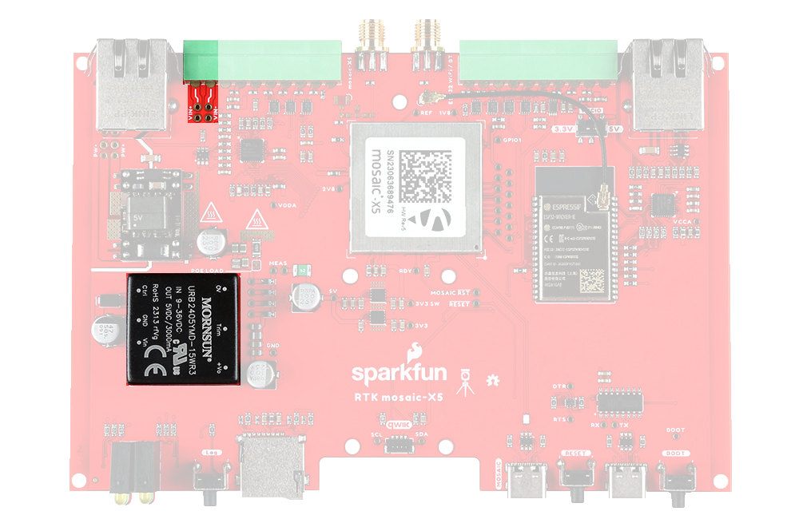
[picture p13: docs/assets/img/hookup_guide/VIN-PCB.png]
External DC Power Input
	
	<figcaption markdown>The DC-DC power converter and external power inputs on the RTK mosaic-X5 PCB.</figcaption>
	</figure>

	</div>

	</div>

	??? tip "Vehicle Power"
		For **12V** or **24V** vehicle power:

		* Connect 12V or 24V to the `VIN+` screw cage terminal
		* Connect 0V (chassis) to the `VIN-` screw cage terminal

		!!! warning "Power Source"
			Additionally, make sure that the power source from the vehicle is not directly tied to the vehicle's battery, `Always On`, or accessory circuits. Otherwise, users will risk killing the battery while the engine is off.

			We recommend locating the *ignition on* or *switched power* circuit, which is only powered when the key is in the `On` position *and the engine is running*.

			!!! note
				The `On` position, is where a key normally rests after the engine is started. However, users can still move the key from the `Off` position and into the `On` position without starting the engine. In this case, the alternator is not running and keeping the battery charged.

				Modern *eco-efficient* vehicles may automatically shut down the engine if the vehicle is idling too long. Therefore, cutting off the vehicle's alternator that keeps the battery charged. Luckily, most vehicles with this *automatic start/stop* technology will monitor the battery's voltage and restart the engine when required. With this in mind, users may want to initially monitor their battery voltage, in case their vehicle isn't *"so smart"* :sweat_smile:.

	??? warning "Ground Loop"
		If desired, users can link `VIN-` to the adjacent `GND` screw cage terminal. However, this will bypass the voltage isolation and could introduce an unwanted ground loop, particularly if the GNSS antenna ground (shield, 0V) is also connected to the chassis.

## :septentrio-logo:&nbsp;mosaic-X5
The heart of our product is of course the mosaic-X5 GNSS module from Septentrio. It is a _very_ sophisticated chip with multiple interfaces: UARTS, USB and Ethernet. The `COM2` and `COM3` UART pins, plus `GPIO1` and `GPIO2`, are available as 0.1" test points should you need access to them.

<figure markdown>
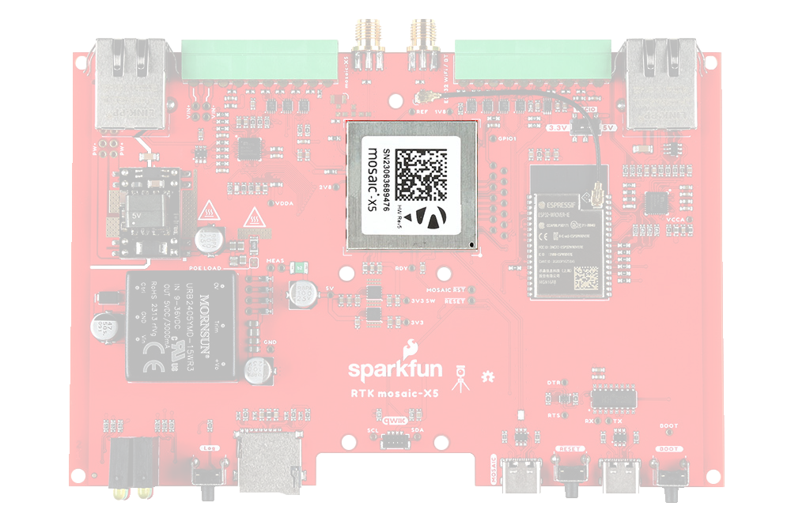
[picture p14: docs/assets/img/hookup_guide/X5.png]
mosaic X5

<figcaption markdown>The Septentrio mosaic-X5 GNSS module.</figcaption>
</figure>

## :espressif-logo:&nbsp;ESP32-WROVER
The only interface the mosaic-X5 doesn't offer is WiFi and that's why we've included an Espressif ESP32-WROVER processor (16MB flash, 8MB PSRAM) with its own Ethernet connection. You can connect the mosaic-X5 directly to your Ethernet network - our product supports Power-over-Ethernet too. Or you can link the mosaic-X5 Ethernet port to the ESP32 Ethernet port and have the ESP32 provide WiFi connectivity. In that mode, the ESP32 becomes an Ethernet to WiFi Bridge, seamlessly passing WiFi traffic to and from the mosaic-X5 via Ethernet.

<figure markdown>
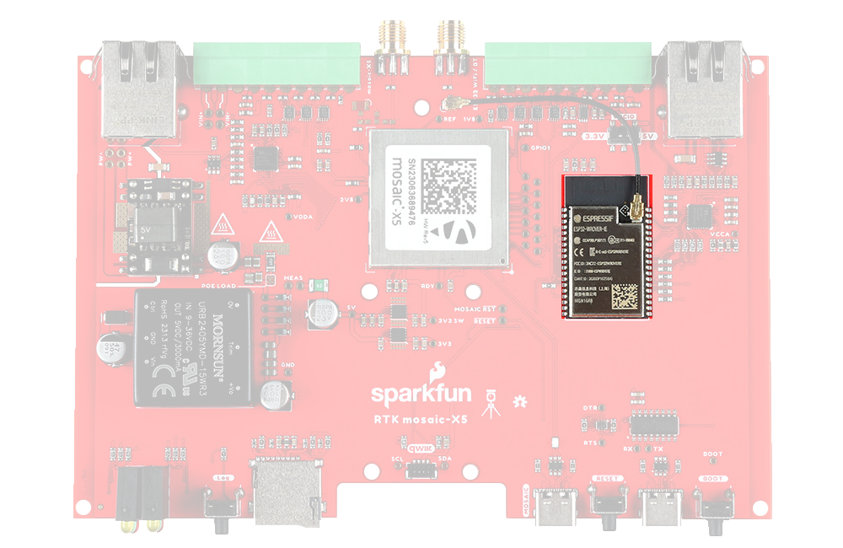
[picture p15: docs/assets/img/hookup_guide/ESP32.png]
Espressif ESP32

<figcaption markdown>The Espressif ESP32-WROVER processor.</figcaption>
</figure>

Think of the ESP32 as a co-processor, or riding shotgun... The mosaic-X5 `COM4` UART is linked to the ESP32, allowing the two to communicate directly without needing the Ethernet link. In our firmware, the ESP32 requests NMEA GGA data over this link and then displays it on the I^2^C OLED display.

!!! warning "WiFi Network Compatibility"
	The ESP32 is only compatible with 2.4GHz bands and cannot access the 5GHz band.

??? code "ESP32 Firmware"
	We have intentionally kept the ESP32 firmware as simple as possible - supporting only two modes: Ethernet *(**Mode: `1`**)* and WiFi *(**Mode: `2`**)*. The intention is that users can easily develop their, own firmware for the RTK mosaic-X5 using the Espressif ESP IDF if the SparkFun firmware does not meet their needs.

	!!! info "Provisioning Limitations"
		* The ESP32 firmware we provide is only compatible with basic `SSID` and `Password` WiFi authentication.
		* The firmware is not compatible with networks that implement other provisioning methods such as a [captive portal](https://en.wikipedia.org/wiki/Captive_portal), a QR code, or [Wi-Fi protected setup](https://en.wikipedia.org/wiki/Wi-Fi_Protected_Setup "WPS").

## Ethernet PHY Interfaces
The mosaic-X5 and ESP32 have identical KSZ8041NLI Ethernet PHY interfaces, both connected using Reduced Media-Independent Interfaces (RMII). These allow the mosaic-X5 and ESP32 to be linked directly to your Ethernet network or router, or to each other when the ESP32 is acting as an Ethernet-to-WiFi Bridge.

<div class="grid" markdown>

<div markdown>

<figure markdown>
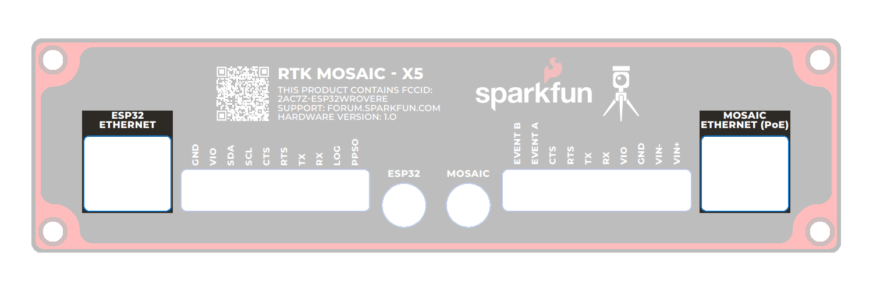
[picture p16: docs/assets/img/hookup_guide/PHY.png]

<figcaption markdown>Ethernet connections: ESP32 (left) and mosaic-X5 (right).</figcaption>
</figure>

</div>

<div markdown>

<figure markdown>
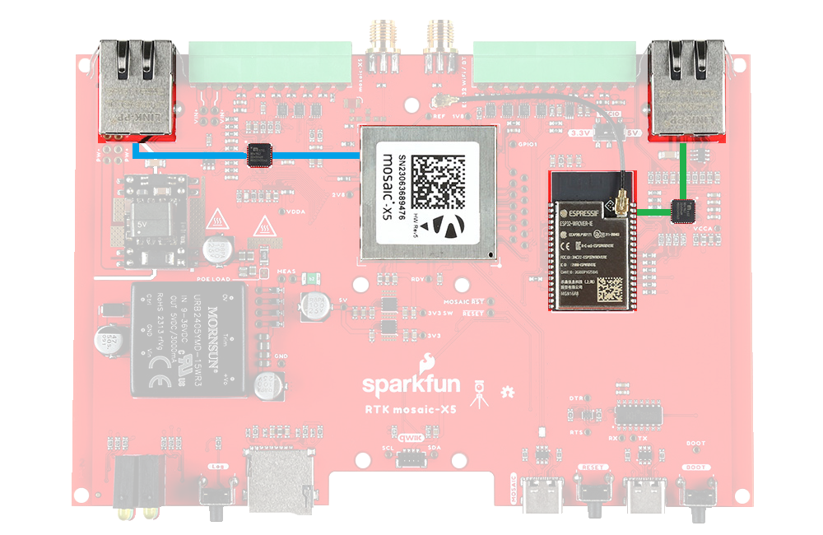
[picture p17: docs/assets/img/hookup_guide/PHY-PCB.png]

<figcaption markdown>The two Ethernet physical layer interfaces and connections.</figcaption>
</figure>

</div>

</div>

## USB-C Connectors
The mosaic-X5 and ESP32 both have USB-C connections. The MOSAIC USB port is high-speed and connected to the X5 through a balancing transformer. The ESP32 USB port is connected through a CH340 USB-UART IC.

<div class="grid" markdown>

<div markdown>

<figure markdown>
USB-C Connectors
<figcaption markdown>USB-C connections: mosaic-X5 (left) and ESP32 (right).</figcaption>
</figure>

</div>

<div markdown>

<figure markdown>
USB-C Power Connections
<figcaption markdown>The USB-C data connections on the RTK mosaic-X5 PCB.</figcaption>
</figure>

</div>

</div>

!!! info
	The RTK mosaic-X5 can draw power from either or both USB ports, in addition to Power-over-Ethernet and the DC-DC external input described above.

!!! info "CH340 Driver"
	The CH340 allows the ESP32-WROVER to communicate with a computer/host device through the USB-C connection. This allows the ESP32 to show up as a device on the serial (or COM) port of the computer. Users will need to install the latest drivers for the computer to recognize the CH340 *(see **[USB Driver](../software_overview/#espressif-logoesp32)** section)*.

## &micro;SD Socket
The &micro;SD socket is connected directly to the mosaic-X5 via a one-bit SDIO interface for fast data logging. The mosaic-X5 supports &micro;SD cards with a **FAT32** file system *(i.e. only cards **up to 32GB** in size)*.

<div class="grid" markdown>

<div markdown>
<figure markdown>
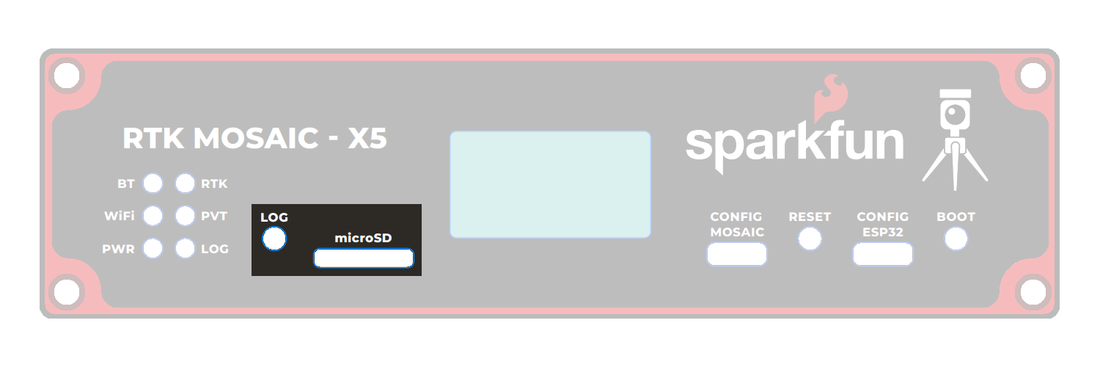
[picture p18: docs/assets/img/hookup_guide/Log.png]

<figcaption markdown>&micro;SD slot and ++"LOG"++ button.</figcaption>
</figure>
</div>

<div markdown>
<figure markdown>
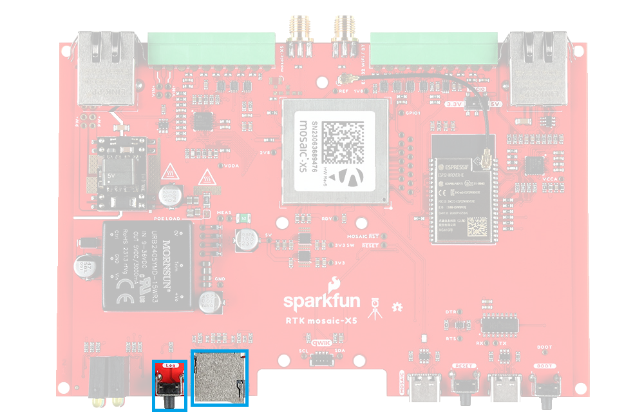
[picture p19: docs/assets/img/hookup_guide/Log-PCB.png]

<figcaption markdown>&micro;SD socket and ++"Log"++ button on the RTK mosaic-X5 PCB.</figcaption>
</figure>
</div>

</div>

??? info "Operation Instructions"

	!!! success "Initial Configuration"
		Before logging can take place, it is necessary to define a "logging stream" using the **Logging** page or **RxTools**. Streams can contain NMEA or SBF (Septentrio Binary Format) data; SBF can contain RTCM and/or RINEX.

		<figure markdown>
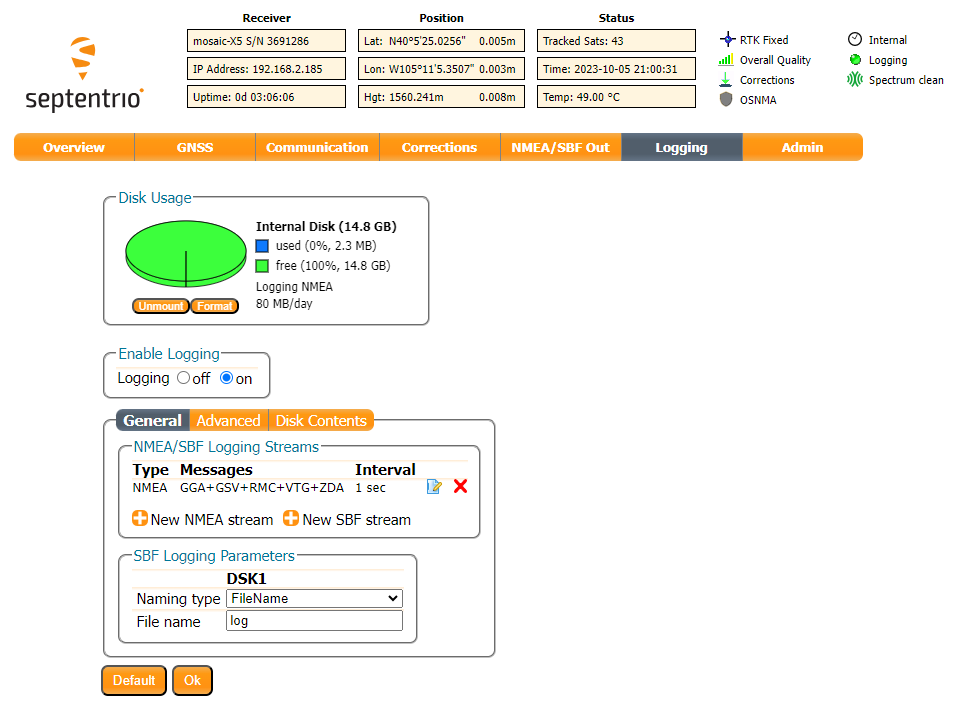
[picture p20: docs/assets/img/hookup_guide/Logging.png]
Logging stream configuration
		
		<figcaption markdown>&micro;SD logging stream configuration.</figcaption>
		</figure>
		
		!!! tip "Instructional Video"
			:material-youtube: [How to log data to the SD card of the Septentrio mosaic receiver module](https://youtu.be/Y9tvOebnoxk)

	Once the stream is defined, users can control the data logging operation through the ++"LOG"++ button.

	* A short press of the ++"LOG"++ button *(< 5s)* toggles data logging to the SD card on and off.
		* The red `LOG` LED will flash while logging is taking place.
	* A long press, holding the ++"LOG"++ button for more than 5 seconds *(> 5s)* and then releasing it, will force the board to:
		* Unmount the SD card if it was mounted
		* Mount the SD card if it was unmounted

## SMA Connectors
The RTK mosaic-X5 has robust SMA connectors for the mosaic-X5 GNSS antenna and the ESP32 WiFi / BT antenna.

<div class="grid" markdown>

<div markdown>
<figure markdown>
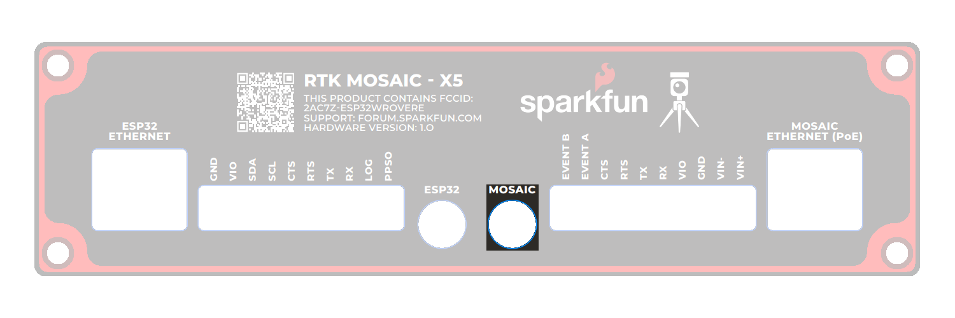
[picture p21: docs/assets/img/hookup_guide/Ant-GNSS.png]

<figcaption markdown>The SMA connector for the GNSS antenna.</figcaption>
</figure>

<figure markdown>
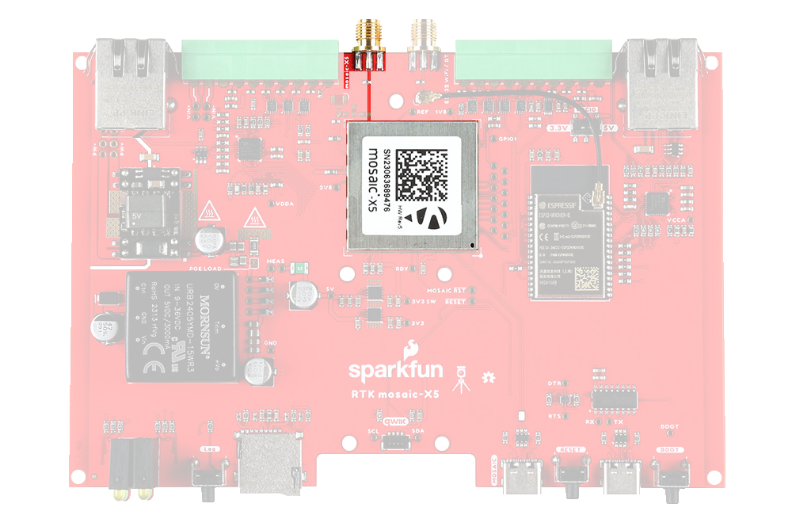
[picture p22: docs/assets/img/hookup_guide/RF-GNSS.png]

<figcaption markdown>The connection for the GNSS antenna to the mosaic-X5.</figcaption>
</figure>

The mosaic-X5 SMA connector is standard polarity and provides 5V power for an active antenna.
</div>

<div markdown>
<figure markdown>
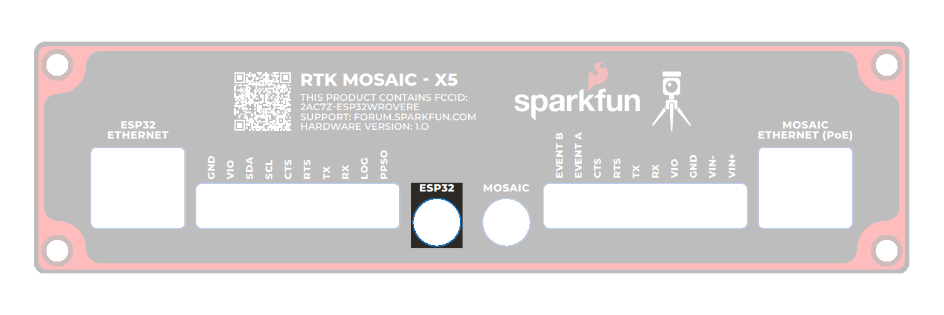
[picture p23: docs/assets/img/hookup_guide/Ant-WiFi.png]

<figcaption markdown>The RP-SMA connector for the WiFi/BLE antenna.</figcaption>
</figure>

<figure markdown>
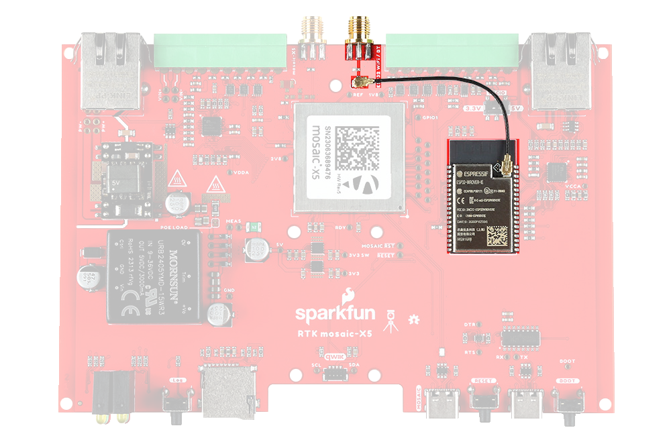
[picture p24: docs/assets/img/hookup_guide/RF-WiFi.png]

<figcaption markdown>The connection for the WiFi / BLE antenna to the ESP32.</figcaption>
</figure>

The ESP32 WiFi / BT SMA connector is reverse-polarity (RP). A short u.FL cable connects the SMA connector to the ESP32-WROVER itself.
</div>

</div>

!!! tip "Connector Polarity"
	When selecting antennas and/or cables for the RTK mosaic-X5, double-check the polarity for the connections.

## I/O Terminals
The RTK moasic-X5 is equipped with two [10-way 3.5mm screw cage terminal connectors](https://www.sparkfun.com/10-way-terminal-socket.html).

<div class="grid" markdown>

<div markdown>

<figure markdown>
IO Connections
<figcaption markdown>I/O Screw Terminal Connections.</figcaption>
</figure>

</div>

<div markdown>

<figure markdown>
IO Connections
<figcaption markdown>I/O Screw Terminal Connections on the RTK mosaic-X5 PCB.</figcaption>
</figure>

</div>

</div>

These terminals are described in the tabs below. For more information on the I/O terminals, you can refer to the [schematic](./assets/board_files/schematic.pdf).

=== "External Power"

	The `VIN+` and `VIN-` terminals allow the RTK mosaic-X5 to be powered by an external DC power source - typically a 12V / 24V vehicle battery.

	<article style="text-align: center;" markdown>

	| **Terminal** | **Function**                                |
	| :----------: | :------------------------------------------ |
	| **VIN+**     | External voltage: **Min: 9V**; **Max: 36V** |
	| **VIN-**     | Ground / Chassis / 0V                       |

	</article>

	!!! info
		The DC-DC converter in the RTK mosaic-X5 provides 1.5kV isolation between `VIN+`/`VIN-` and **5V**/**GND**. There is no direct electrical connection between `VIN-` and `GND`.

	!!! warning "Ground Loop"
		If desired, users can link `VIN-` to the adjacent `GND` screw cage terminal. However, this will bypass the voltage isolation and could introduce an unwanted ground loop, particularly if the GNSS antenna ground (shield, 0V) is also connected to the chassis.

=== "VIO & GND"
	The I/O terminal voltage can be set to 3.3V or 5V via the small internal slide switch highlighted below:

	<figure markdown>
	VIO selection switch
	<figcaption markdown>I/O voltage selection switch.</figcaption>
	</figure>

	The `VIO` terminals can be used as power outputs or logic-high references. Likewise, the `GND` terminals can be used for power return or as logic-low references.

	<article style="text-align: center;" markdown>

	| **Terminal** | **Function**                                    |
	| :----------: | :---------------------------------------------- |
	| **VIO**      | 3.3V or 5V power output or logic-high reference |
	| **GND**      | Ground / 0V or logic-low reference              |

	</article>

	!!! info
		The default position of the `VIO` switch is **3.3V**.

	!!! tip
		The `VIO` and `GND` pins could be used to power (e.g.) a LoRa module. We recommend limiting the current draw from `VIO` to **200mA** and never drawing more than 500mA peak. The upstream 3.3V regulator is rated at 1A but it also provides power for the ESP32 processor.

=== "mosaic-X5 `COM1`"
	The mosaic-X5 UART COM1 connections are adjacent to the **EVENTA** and **EVENTB** terminals and are connected as follows:

	<article style="text-align: center;" markdown>

	| **Terminal** | **Function**                           | **Notes**                                                     |
	| :----------: | :------------------------------------- | :------------------------------------------------------------ |
	| **RX**       | COM1 UART Receive - **Input**          |                                                               |
	| **TX**       | COM1 UART Transmit - **Output**        |                                                               |
	| **RTS**      | COM1 UART Request To Send - **Output** | The module drives this pin low when ready to receive data     |
	| **CTS**      | COM1 UART Clear To Send - **Input**    | Must be driven low when ready to receive data from the module |

	</article>

	!!! tip
		The COM1 I/O voltage is set by the I/O voltage selection switch.

	!!! tip
		The **CTS** input floats low. Pull CTS up to VIO to disable UART Transmit.

=== "EVENT A & B"
	The mosaic-X5 **EVENTA** and **EVENTB** inputs can be used to mark or timestamp external events:

	<article style="text-align: center;" markdown>

	| **Terminal** | **Function**    |
	| :----------: | :-------------: |
	| **EVENTA**   | Event A : Input |
	| **EVENTB**   | Event B : Input |

	</article>

	!!! tip
		The EVENT voltage level is set by the I/O voltage selection switch.

	!!! tip
		The EVENT inputs are pulled low internally. Pull up to VIO to trigger an event.

	!!! tip
		An easy way to observe the events is with **RxTools** \ **RxControl** \ **Expert Console** (under **Tools**) \ **ExEvent** tab:

		<figure markdown>
		External Events
		<figcaption markdown>Capturing external events from EVENTA and EVENTB.</figcaption>
		</figure>

=== "PPSO"
	The mosaic-X5 **PPSO** is a configurable Pulse-Per-Second output. By default, PPSO is high for 5ms at 1Hz. The polarity, frequency and pulse width can be adjusted with the **`setPPSParameters`** command.

	<article style="text-align: center;" markdown>

	| **Terminal** | **Function**              |
	| :----------: | :-----------------------: |
	| **PPSO**     | Pulse-Per-Second : Output |

	</article>

	!!! tip
		The PPSO voltage is set by the I/O voltage selection switch.

=== "LOG"
	The mosaic-X5 **LOG** input starts and stops &micro;SD logging. It is also used to mount and dismount the &micro;SD card.

	<article style="text-align: center;" markdown>

	| **Terminal** | **Function** |
	| :----------: | :----------: |
	| **LOG**      | Log : Input  |

	</article>

	!!! tip
		The LOG voltage level is set by the I/O voltage selection switch.

	!!! tip
		The LOG input is pulled up to VIO internally. Pull low to GND to start or stop logging.

	!!! tip
		Internal resistors allow the `LOG` I/O terminal and ++"Log"++ button to be used simultaneously. It is OK to press the ++"Log"++ button while the `LOG` terminal is being driven high (VIO).

=== "ESP32 `UART`"
	Four ESP32 GPIO pins are connected to I/O screw terminals as follows. These pins are not used by version 1.0.0 of the RTK mosaic-X5 ESP32 firmware. They are available for you to use if you are developing your own firmware.

	<article style="text-align: center;" markdown>

	| **Terminal** | **Suggested Function**                  | **Notes**                                                     |
	| :----------: | :-------------------------------------- | :------------------------------------------------------------ |
	| **RX**       | UART Receive                            | **Input** - connected to GPIO pin 34 through a level-shifter  |
	| **TX**       | UART Transmit                           | **Output** - connected to GPIO pin 32 through a level-shifter |
	| **RTS**      | UART Request To Send                    | **Output** - connected to GPIO pin 33 through a level-shifter |
	| **CTS**      | UART Clear To Send                      | **Input** - connected to GPIO pin 35 through a level-shifter  |

	</article>

	!!! tip
		The I/O voltage is set by the I/O voltage selection switch.

	!!! info
		These pins are not used by version 1.0.0 of the ESP32 firmware.

=== "SDA & SCL"
	The ESP32 I^2^C (`Wire`) bus **SDA** and **SCL** signals are available via the I/O terminals. Internally, the I^2^C bus is used to configure the Qwiic OLED display. If you connect a logic analyzer to the SDA and SCL I/O terminals, you will be able to see the OLED traffic (address 0x3D). We made the SDA and SCL signals accessible in case you are developing your own firmware for the RTK mosaic-X5. The I/O terminals are fully level-shifted. It is OK to have a 5V I^2^C peripheral connected while also using the internal 3.3V Qwiic bus for the OLED.

	<article style="text-align: center;" markdown>

	| **Terminal** | **Function**         |
	| :----------: | :------------------: |
	| **SDA**      | I^2^C Data  |
	| **SCL**      | I^2^C Clock |

	</article>

	!!! tip
		The I/O voltage is set by the I/O voltage selection switch.

	??? tip "What is Qwiic?"

		<!-- Qwiic Banner -->
		<article style="text-align: center;" markdown>
		Qwiic Logo - light theme (https://www.sparkfun.com/qwiic)
		Qwiic Logo - dark theme (https://www.sparkfun.com/qwiic)
		</article>

		---

		The [Qwiic connect system](https://www.sparkfun.com/qwiic) is a solderless, polarized connection system that allows users to seamlessly daisy chain I^2^C boards together. Play the video below to learn more about the Qwiic connect system or click on the banner above to learn more about [Qwiic products](https://www.sparkfun.com/qwiic).

		<article style="text-align: center;" markdown>
		<div class="video-500px">
		<iframe src="https://www.youtube.com/embed/x0RDEHqFIF8" title="SparkFun's Qwiic Connect System" frameborder="0" allow="accelerometer; encrypted-media; gyroscope; picture-in-picture" allowfullscreen></iframe>
		</div>
		</article>

		!!! info "Features of the Qwiic System"

			=== "No Soldering"

				no soldering - light theme
				no soldering - dark theme

				Qwiic cables (4-pin JST) plug easily from development boards to sensors, shields, accessory boards and more, making easy work of setting up a new prototype.

			=== "Polarized Connector"

				polarized connector - light theme
				polarized connector - dark theme

				There's no need to worry about accidentally swapping the SDA and SCL wires on your breadboard. The Qwiic connector is polarized so you know you’ll have it wired correctly every time, right from the start.

				The PCB connector is part number SM04B-SRSS ([Datasheet](https://cdn.sparkfun.com/assets/parts/1/2/2/8/9/Qwiic_Connector_Datasheet.pdf)) or equivalent. The mating connector used on cables is part number SHR04V-S-B or an equivalent *(1mm pitch, 4-pin JST connector)*.

			=== "Daisy Chain-able"

				daisy chainable - light theme
				daisy chainable - dark theme

				It’s time to leverage the power of the I^2^C bus! Most Qwiic boards will have two or more connectors on them, allowing multiple devices to be connected.

## Status LEDs
There are six status LEDs on the RTK mosaic-X5:

<div class="grid" markdown>

<div markdown>

* `PWR` - Power *(Red)*
	* Illuminates when power is applied
* `LOG` - &micro;SD Logging *(Red)*
	* Solid Red - &micro;SD card is mounted
	* Blinking Red - Data is being logged
	* Off - &micro;SD is dismounted or not present
* `WiFi` - WiFi *(Green)*
	* The ESP32 firmware is using WiFi
	* Connected to ESP32 GPIO pin 12
* `PVT` - Position Velocity Time *(Green)*
	* Solid Green - The mosaic-X5 has valid Position, Velocity and Time
	* Off - Satellite signal not present or acquired
* `BT` - Bluetooth *(Yellow)*
	* The ESP32 firmware is using BT
	* Connected to ESP32 GPIO pin 13
	* *Not used by firmware v1.0.0*
* `RTK` - Real-Time Kinematic *(Yellow)*
	* Solid Yellow - The mosaic-X5 has an RTK Fixed solution
	* Blinking Yellow - The mosaic-X5 has an RTK Float solution
	* Off - No RTK solution

</div>

<div markdown>

<figure markdown>
LEDs
<figcaption markdown>The status indicator LEDs on the RTK mosaic-X5.</figcaption>
</figure>

<figure markdown>
LEDs
<figcaption markdown>The status indicator LEDs on the RTK mosaic-X5 PCB.</figcaption>
</figure>

</div>

</div>

## OLED Display
The RTK mosaic-X5 has a 128x64 pixel OLED display, controlled by the ESP32 via I^2^C. After some initial diagnostic messages, the display will show position, time and other data from the mosaic-X5 NMEA **GGA** message, plus the Ethernet / WiFi IP address.

<figure markdown>
LEDs
<figcaption markdown>The OLED display on the RTK mosaic-X5.</figcaption>
</figure>

* **Time:** - Universal Time Coordinate (UTC) in `HHMMSS.SS` format
	* Note: the display is updated approximately every 2 seconds. The time shown may not be precise.
* **Lat:** - Latitude in `DDMM.MMMMMMM` `N`/`S` format (this is the format used by the GGA message)
* **Long:** - Longitude in `DDDMM.MMMMMMM` `E`/`W` format (this is the format used by the GGA message)
* **Fix:** - the GNSS fix type
* **Sat:** - the number of satellites used in the navigation solution
	* Note: this is not the same as "Satellites In View"
* **HDOP:** - Horizontal Dilution Of Precision
	* Note: this is a dimensionless number indicating the horizontal position accuracy
* **Alt:** - the Altitude in meters
	* Note: this is the altitude above Mean Sea Level, not Geoid
* **IP:** - the mosaic-X5 IP address, obtained via Ethernet or WiFi
	* The X5's internal configuration page can be viewed at this address

??? example "Example Data"
	Below, is an example data set recorded on the RTK mosaic-X5 at SparkFun HQ; where the antenna was located on the roof of the building. The antenna was above the loading dock, just about where it is displayed on the map. The table, below, is an example of how to convert the information on the display into the time and coordinate values.

	<div class="grid">

	<div markdown>

	<figure markdown>
	LEDs
	<figcaption markdown>Example information on the OLED display of the RTK mosaic-X5.</figcaption>
	</figure>

	</div>

	<div markdown>

	<article style="text-align: center;" markdown>

	|    | Data | Format | Value |
	| :- | :--- | :----- | :---- |
	| Time | `191525.90` | `HHMMSS.SS` | 7:15:25.90 PM (UTC)<br>12:15:25.90 PM (MST) |
	| Latitude | `4005.4192485 N` | `DDMM.MMMMMMM` `N`/`S` | 40&deg; 5.4162485' N<br>40&deg; 5' 24.97491" N<br>40.090270808&deg; N |
	| Longitude | `10511.0873663 W` | `DDDMM.MMMMMMM` `E`/`W` | 105&deg; 11.0873663' W<br>105&deg; 11' 5.241978" W<br>105.184789438&deg; W |

	</article>

	</div>

	</div>

	<figure markdown>
	<iframe src="https://www.google.com/maps/embed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" width="800" height="400" style="border:0;" allowfullscreen="" loading="lazy" referrerpolicy="no-referrer-when-downgrade"></iframe>
	<figcaption markdown>The location of the antenna on Google Maps, as determined from the coordinates on the OLED display. Source: [Google Maps](https://www.google.com/maps/@40.0838666,-105.18528,15z?entry=ttu)</figcaption>
	</figure>

## Buttons
There are three buttons on the RTK mosaic-X5: ++"RESET"++, ++"BOOT"++, and ++"LOG"++.

<div class="grid" markdown>

<div markdown>

<figure markdown>
Buttons
<figcaption markdown>Buttons on the RTK mosaic-X5.</figcaption>
</figure>

</div>

<div markdown>

<figure markdown>
Buttons
<figcaption markdown>Buttons on the RTK mosaic-X5 PCB.</figcaption>
</figure>

</div>

</div>

=== ":septentrio-logo:&nbsp;mosaic-X5: Data Logging"
	Once a [logging stream](#sd-socket) is defined, users can control the data logging operation through the ++"LOG"++ button.

	* A short press of the ++"LOG"++ button *(< 5s)* toggles data logging to the SD card on and off.
		* The red `LOG` LED will flash while logging is taking place.
	* Holding the ++"LOG"++ button for more than 5 seconds *(> 5s)* and then releasing it, will force the board to:
		* Unmount the SD card if it was mounted
		* Mount the SD card if it was unmounted

	!!! tip "Instructional Video"
		:material-youtube: [How to log data to the SD card of the Septentrio mosaic receiver module](https://youtu.be/Y9tvOebnoxk)

=== ":espressif-logo:&nbsp;ESP32: Reset"
	The ++"RESET"++ button allows users to reset the firmware running on the ESP32-WROVER module without disconnecting the power.

=== ":espressif-logo:&nbsp;ESP32: Boot Control"
	The ++"BOOT"++ button can be used to force the ESP32 into the serial bootloader. Holding down the ++"BOOT"++ button, while connecting the RTK mosaic-X5 to a computer through its USB-C connector or resetting the board will cause it to enter the <a href="https://docs.espressif.com/projects/esptool/en/latest/esp32/advanced-topics/boot-mode-selection.html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">Firmware Download mode</a>. The ESP32 will remain in this mode until it power cycles (happens automatically after uploading new firmware) or the ++"RESET"++ button is pressed.

	1. Hold the ++"BOOT"++ button down.
	2. Reset the MCU.
		* While unpowered, connect the board to a computer through the USB-C connection.
		* While powered, press the ++"RESET"++ button.
	3. Release the ++"BOOT"++ button.
	4. After programming is completed, reboot the MCU.
		* Press the ++"RESET"++ button.
		* Power cycle the board.

	!!! info "BOOT and GPIO0"
		The ESP32 GPIO pin 0 is connected to the BOOT button. But is also used by the firmware to generate the 50MHz clock for the RMII Ethernet PHY interface.

		Pressing the BOOT button while the firmware is running in mode 2 (WiFi) will interrupt the clock and cause Ethernet communication with the mosaic-X5 to fail.

## Jumpers

??? note "Never modified a jumper before?"
	Check out our <a href="https://learn.sparkfun.com/tutorials/664">Jumper Pads and PCB Traces tutorial</a> for a quick introduction!

	<div class="grid cards col-4" markdown align="center">

	-   <a href="https://learn.sparkfun.com/tutorials/664">
		<figure markdown>
		Tutorial thumbnail
		</figure>

		---

		**How to Work with Jumper Pads and PCB Traces**</a>

	</div>

There are several jumpers on the RTK moasic-X5 PCB which can be used to (e.g.) disable the LEDs or allow measurement of the board's current draw.

<div class="grid" markdown>

<div markdown>

<figure markdown>
Jumpers
<figcaption markdown>The jumpers on the top of the RTK mosaic-X5 PCB.</figcaption>
</figure>

</div>

<div markdown>

<figure markdown>
Jumpers
<figcaption markdown>The jumpers on the bottom of the RTK mosaic-X5 PCB.</figcaption>
</figure>

</div>

</div>

=== "Top"
	* **POE LOAD** - This jumper can be used to disconnect the Power-over-Ethernet (PoE) module 50&ohm; load.
		* The PoE module has a minimum load of 100mA. We included the 50&ohm; load to ensure this is met. If you can ensure this by other means, open this jumper to disconnect the load.

=== "Bottom"
	* LED Jumpers
		* **LINK** (x2) - open these jumpers to disable the Ethernet Link LEDs.
		* **SPEED** (x2) - open these jumpers to disable the Ethernet Speed LEDs.
		* **RTK** - open this jumper to disable the mosaic-X5 Real-Time Kinetic LED.
		* **PVT** - open this jumper to disable the mosaic-X5 Position Velocity Time LED.
		* **LOG** - open this jumper to disable the mosaic-X5 Log LED.
		* **BT** - open this jumper to disable the ESP32 BT LED.
		* **WiFi** - open this jumper to disable the ESP32 WiFi LED.
		* **PWR** - open this jumper to disable the Power LED.
	* Button Jumpers
		* **BOOT** - open this jumper to disconnect the ESP32 BOOT pushbutton.
		* **RESET** - open this jumper to disconnect the ESP32 RESET pushbutton.
	* **SHLD** (x2) - open these jumpers to isolate the USB-C connector shield from GND.
	* **I^2^C** - open this dual jumper to disconnect the pull-ups for the SDA and SCL I/O terminals.
		* Note: the internal 3.3V Qwiic bus has its own pull-ups which are disconnected by default. These can be enabled by closing the dual jumper under the OLED Qwiic connector. We suggest you only do this if you are disconnecting the OLED.
	* **VIN+** and **VIN-**
		* Open these jumpers if you wish to isolate (disconnect) the external DC power terminals. The breakout pads can then be used to feed in power from an alternate source.
	* **PW+** and **PW-**
		* Open these jumpers if you wish to isolate (disconnect) the Power-over-Ethernet pins on the MOSAIC Ethernet magjack. The breakout pads can then be used to feed in power from an alternate source.
	* **MEAS**
		* Open the **MEAS** jumper if you wish to measure the total current drawn by the RTK mosaic-X5, or (e.g.) wish to add an ON/OFF switch. The breakout pads can then be used to attach a multimeter or a mechanical power switch.
		* **MEAS** is _upstream_ of the two 3.3V regulators and _downstream_ of the four power source combination and protection diodes.

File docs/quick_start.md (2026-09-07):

---
icon: material/run-fast
hide: toc
---

!!! failure "Deprecated Documentation"
	As of Sept 1, 2026 this guide has been retired. Users can find our latest documentation at: [https://docs.sparkpnt.com/SXM-E](https://docs.sparkpnt.com/SXM-E)

!!! abstract "Directions"

	This *quick start* guide is intended to help users get started with their RTK mosaic-X5, without having to review the technical details of the product. It includes the minimum instructions to initially set up the RTK mosaic-X5, depending on the primary interface that users would like to utilize:

	<div class="grid" markdown>

	<div markdown>

	**Ethernet**

	: Instructions to connect the RTK mosaic-X5 to a network with an ethernet cable. This will provide the mosaic-X5 with network connectivity for its web server. Users can then pull up the configuration web page from any computer connected to that network.

	**WiFi**

	: Instructions for remote/exterior installations, where a WiFi connection is preferred. This will provide WiFi connectivity to mosaic-X5's web server; where users can then access the configuration web page from any device on the WiFi network.

	**USB-C**

	: For users that just want to interface and set up the RTK mosaic-X5, directly through their computer.

	</div>

	<div markdown>

	<figure markdown>
	Clicking on tabs Gif
	<figcaption markdown>Click on the tab of your preferred interface (below), to get started with the RTK mosaic-X5.</figcaption>
	</figure>

	</div>

	</div>

	??? info ":material-printer: Quick Start Pamphlet"
		For users who have lost the pamphlet in their kit, please check out the links below to download the `*.pdf` file:

		<figure markdown>
		Scan QR Code to Download PDF File
		<figcaption markdown>[:octicons-download-16:{ .heart } Download the Quick Start Guide :fontawesome-solid-file-pdf:](./assets/quick_start_guide-v10.pdf "Click to Download"){ .md-button .md-button--primary }</figcaption>
		</figure>
		<article style="text-align: center;" markdown>
		*Click on the button (above) or scan the QR code with a mobile device, to download the `*.pdf` file of the quick start pamphlet.*
		</article>

=== "<H2>:material-ethernet:&nbsp;Ethernet</H2>"

	The simplest way to get your RTK mosaic-X5 up and running is to connect it to your Ethernet network or an Ethernet port on your broadband router:

	<figure markdown>
	Ethernet Connections
	<figcaption markdown>[Ethernet Connections (PNG)](./assets/img/hookup_guide/Ethernet_Connections.png) for the RTK mosaic-X5.</figcaption>
	</figure>

	**`1`** - **Connect the GNSS antenna**
	: * Inside your RTK mosaic-X5 kit, you will find the L1/L2/L5 GNSS "UFO" antenna. It has a TNC connection. Use the supplied TNC-SMA cable to connect the antenna to the mosaic-X5 **MOSAIC** SMA connection.
		* The antenna needs a clear view of the sky. If you are working indoors, put the antenna outside and pass the cable through a window. (Insulating double-glazed windows have a coating which can block the GNSS signal. For best results, put the antenna outside.)
		* If you are going to use your RTK mosaic-X5 as an RTK Base, the antenna needs to be securely mounted to a structure so that it cannot be moved and has a clear view of the sky. Any movement in the antenna will cause inaccurate readings by RTK rovers. Please see the [Required Materials](./introduction.md#required-materials) for links to our [GNSS Antenna Mounting Hardware Kit](https://www.sparkfun.com/gnss-antenna-mounting-hardware-kit.html) and [GNSS Magnetic Antenna Mount - 5/8" 11-TPI](https://www.sparkfun.com/gnss-magnetic-antenna-mount-5-8-11-tpi.html)
	**`2`** - **Connect the RTK mosaic-X5 to your Ethernet network or router**
	: * Use the supplied CAT-6 Ethernet cable to connect the **MOSAIC ETHERNET (PoE)** port to your network or an Ethernet port on your router.
		* If your router provides Power-over-Ethernet (PoE), you're all set! You should see the red power (PWR) LED light up and text start to scroll up the OLED display.
		* If your router does not provide PoE, move on to step 3.
	**`3`** - **Provide power**
	: * You can power the RTK mosaic-X5 using the supplied USB power supply (5V 1A wall adapter).
		* Plug the power supply into the wall.
		* Use the supplied USB-C cable to connect the power supply to either the **CONFIG MOSAIC** or the **CONFIG ESP32** USB-C port. It does not matter which.
		* You should see the red power (PWR) LED light up and text start to scroll up the OLED display.

	Once the mosaic-X5 has acquired a satellite signal and is connected to the Ethernet network, the OLED will display: the antenna's position as Latitude (Lat), Longitude (Long) and Altitude (Alt); the Ethernet IP (Internet Protocol) network address.

	Connect your computer, tablet or phone to the same network, open a web browser and navigate to the IP address shown on the OLED display. You should see the mosaic-X5's internal web page. The web page displays a lot of helpful information and can also be used to fully configure the mosaic-X5.

	<figure markdown>
	mosaic X5 web page
	<figcaption markdown>[mosaic X5 web page (GIF)](./assets/img/hookup_guide/x5_web_page.gif) for the RTK mosaic-X5.</figcaption>
	</figure>

	!!! tip "Not working?"
		The following sections will help if your RTK mosaic-X5 is not working as expected:

		??? info "Using mosaic-X5 firmware >= 4.15.0?"
			With mosaic-X5 firmware 4.15.0, a user-defined username and password are mandatory on all IP interfaces. These must be entered as described in the [Log-in procedure](https://customersupport.septentrio.com/s/article/Cybersecurity-guidelines-Log-in-procedure) on all IP interfaces individually and separately. The ESP32 is connected via COM. It does not need to know the username and password unless you also change default access level for the COM ports. If you do, you need to ensure the RTK mosaic-X5 ESP32 firmware has been [upgraded to version >= 1.0.5](./software_overview.md#esp32-firmware-update) and that the username and password have been set using *set -u* and *set -x*

		??? info "No power?"
			The red power (PWR) LED will light up when the RTK mosaic-X5 has power. If the PWR LED is off, make sure the wall adapter has power and the USB cable is connected.

			If you use your own Ethernet cable for Power-over-Ethernet, check it has all eight pins connected. Some cables only have four pins connected and do not support Power-over-Ethernet.

		??? info "No position information?"
			The OLED display will only show position information (Lat, Long, Alt etc.) once a satellite signal has been acquired. If you see only the IP address on the display, check the SMA to TNC cable is connected correctly and that the antenna is outside with a clear view of the sky. Use a [male-female SMA extension cable](https://www.sparkfun.com/interface-cable-sma-female-to-sma-male-10m-rg58.html) if needed to increase the cable length.

		??? info "No IP address?"
			By default, the mosaic-X5 Ethernet port is configured for Dynamic Host Configuration Protocol (DHCP). It expects the router / Ethernet switch to provide it with an IP address. If the IP address is all zeros (0.0.0.0), check that your router has DHCP enabled. Most do.

			If you need a static IP address, you can configure this through the mosaic-X5's **Communication \ Ethernet** sub-page.

			Subnet 3 is reserved for the mosaic-X5's USB-C connection (Ethernet-over-USB). If your router / switch is allocating addresses using subnet 3 (192.168.3.***), please change its settings so it uses a different subnet.

		??? info "No web page?"
			If you can not see the mosaic-X5's internal web page, please check that your computer / tablet / phone is connected to the same network. Most broadband routers support both Ethernet and WiFi simultaneously using the same subnet. If you are using a phone, check it is connected to the router WiFi - and not using its mobile data connection.

			Subnet 3 is reserved for the mosaic-X5's USB-C connection (Ethernet-over-USB). If your router / switch is allocating addresses using subnet 3 (192.168.3.***), please change its settings so it uses a different subnet. If it is using subnet 3, both the mosaic-X5 and your device will appear to have valid IP addresses but will not be able to communicate.

		??? info "Wrong mode?"
			If you still can not see the mosaic-X5's internal web page, please check that the ESP32 firmware is in the correct mode. Press the **RESET** button to restart the ESP32 and watch the text, which scrolls up the OLED display. You should see **Mode 1: Ethernet** displayed briefly. If you see **Mode 2: WiFi**, the firmware is in the wrong mode. Follow the instructions in the next section to change the mode back to **1** (Ethernet).

=== "<H2>:material-wifi:&nbsp;WiFi</H2>"

	The mosaic-X5 GNSS module supports multiple communication interfaces: multiple UARTs; Ethernet; and USB-C (with Ethernet-over-USB). But it does not support WiFi directly. The RTK mosaic-X5 contains an ESP32-WROVER processor which can act as an Ethernet to WiFi bridge. By linking the **MOSAIC ETHERNET (PoE)** port to the **ESP32 ETHERNET** port and putting the ESP32 firmware into WiFi mode, the mosaic-X5 can join your WiFi network.

	To connect your RTK mosaic-X5 to WiFi, you need to do a little more work including changing the mode of the firmware running on the ESP32 processor.

	`1` - **Connect the GNSS antenna**
	:	* Inside your RTK mosaic-X5 kit, you will find the L1/L2/L5 GNSS "UFO" antenna. It has a TNC connection. Use the supplied TNC-SMA cable to connect the antenna to the mosaic-X5 **MOSAIC** SMA connection.
		* The antenna needs a clear view of the sky. If you are working indoors, put the antenna outside and pass the cable through a window. (Insulating double-glazed windows have a coating, which can block the GNSS signal. For best results, put the antenna outside.)
		* If you are going to use your RTK mosaic-X5 as an RTK Base, the antenna needs to be securely mounted to a structure so that it cannot be moved and has a clear view of the sky. Any movement in the antenna will cause inaccurate readings by RTK rovers. Please see the [Required Materials](./introduction.md#required-materials) for links to our [GNSS Antenna Mounting Hardware Kit](https://www.sparkfun.com/gnss-antenna-mounting-hardware-kit.html) and [GNSS Magnetic Antenna Mount - 5/8" 11-TPI](https://www.sparkfun.com/gnss-magnetic-antenna-mount-5-8-11-tpi.html)
	`2` - **Attach the WiFi antenna**
	: * Screw the supplied WiFi/BT antenna onto the **ESP32** SMA connection.
		* To minimize wear of the SMA connector, we recommend: holding the antenna body with one hand - to prevent it from rotating - while screwing the SMA connector into place with your other hand.
		* Fold the antenna up if needed, so the antenna body is vertical.
	`3` - **Link the Ethernet ports**
	: * Link the **MOSAIC ETHERNET (PoE)** and **ESP32 ETHERNET** ports using the supplied cable.
		* The Ethernet ports support Auto-MDIX. You can use a standard Ethernet patch cable to link the ports. You do not need a crossover cable.
	`4` - **Connect to the CONFIG ESP32 USB port**
	: * To change the ESP32 firmware mode, you need to connect a computer to the **CONFIG ESP32** USB-C port and use a Serial Terminal to change the mode.
		* You may need to install a driver, first, so that the CH340 serial interface chip is recognized. Please click the bar below for more details.

		<figure markdown>
		WiFi Mode
		<figcaption markdown>[WiFi Mode (PNG)](./assets/img/hookup_guide/WiFi_Mode.png) for the RTK mosaic-X5.</figcaption>
		</figure>

		??? tip "Install CH340 Driver"
			Users may need to install the appropriate USB driver for their computer to recognize the serial-to-UART chip on their board/adapter. Most of the latest operating systems will recognize the CH340C chip on the board and automatically install the required driver. *To manually install the CH340 driver on their computer, users can download it from the [WCH website](http://www.wch-ic.com/products/CH340.html?).*

			<article style="text-align: center;" markdown>
			[:octicons-download-16:{ .heart } Download the latest CH340 USB driver from WCH](https://www.wch-ic.com/downloads/CH341SER_ZIP.html){ .md-button .md-button--primary target="blank" }
			</article>

			??? abstract "Need Directions?"
				For more information, check out our video and hookup guide:

				<div class="grid" markdown align="center">

				<div markdown>

				<div class="video-500px">
				<iframe src="https://www.youtube.com/embed/MM9Fj6bwHLk" title="Tutorial: Installing CH340 Drivers" frameborder="0" allow="accelerometer; autoplay; clipboard-write; encrypted-media; gyroscope; picture-in-picture" allowfullscreen></iframe>
				</div>

				</div>

				<div class="grid cards" markdown>

				-   <a href="https://learn.sparkfun.com/tutorials/908">
					<figure markdown>
					Tutorial Thumbnail
					</figure>

					---

					**How to Install CH340 Drivers**</a>

				</div>

				</div>

	`5` - **Open a Serial Terminal**
	: * If you are using Windows, we still recommend the [Tera Term](https://learn.sparkfun.com/tutorials/terminal-basics/tera-term-windows) serial terminal but there are plenty of alternatives. Please see our [Serial Terminal Basics tutorial](https://learn.sparkfun.com/tutorials/terminal-basics) for more details.
		* Open the connection to the CH340 using **115200 baud**
	`6` - **Put the ESP32 firmware into WiFi mode**
	: * When you have the Serial Terminal open, you should see the **`RTK_X5>`** console prompt. If you do not, hit Enter on your keyboard. If needed, click the ++"RESET"++ button on the front of the RTK mosaic-X5 to restart the ESP32 firmware.

		<figure markdown>
		Console Prompt
		<figcaption markdown>[Console Prompt (PNG)](./assets/img/hookup_guide/Console_Prompt.png) for changing the RTK mosaic-X5 firmware mode.</figcaption>
		</figure>

		* Type **`help`** and hit enter to see the help.

			<figure markdown>
			Console Help
			<figcaption markdown>[Console Help (PNG)](./assets/img/hookup_guide/Console_Help.png) for changing the RTK mosaic-X5 firmware mode.</figcaption>
			</figure>

		* Type **`show`** to see the current configuration.

			<figure markdown>
			Console Show
			<figcaption markdown>[Console Show (PNG)](./assets/img/hookup_guide/Console_Show.png) for changing the RTK mosaic-X5 firmware mode.</figcaption>
			</figure>

		* By default the firmware will be in **Mode: `1`** (Ethernet). To change the mode to **Mode: `2`** (WiFi), we type:

			!!! terminal
				``` bash
				set -m 2
				```

				!!! tip "Long Arguments"
					The console supports both short and long args, so we could type:

					``` bash
					set --mode=2
					```

		* To set the WiFi SSID, type one of:

			!!! terminal
				``` bash
				set -s YOUR_SSID
				set --ssid=YOUR_SSID
				```

			* Likewise, to set the WiFi password, type one of:

				!!! terminal
					``` bash
					set -p YOUR_PASSWORD
					set --password=YOUR_PASSWORD
					```

			* To save time, you can set all three together with one of:

				!!! terminal
					``` bash
					set -m 2 -s YOUR_SSID -p YOUR_PASSWORD
					set --mode=2 --ssid=YOUR_SSID --password=YOUR_PASSWORD
					```

		* Finally, type **`restart`** to restart the firmware with the new settings:

			!!! terminal
				``` bash
				restart
				```

			??? tip "NULL (empty) password"
				To clear the password - making it NULL / empty - type one of:

				!!! terminal
					``` bash
					set -p %00
					set --password=%00
					```

	Once the mosaic-X5 has acquired a satellite signal and is connected to the WiFi network, the OLED will display: the antenna's position as Latitude (Lat), Longitude (Long) and Altitude (Alt); the WiFi IP (Internet Protocol) network address.

	When powering the RTK mosaic-X5 on for the first time, you may see the firmware restart (reboot) several times while it waits for the mosaic-X5 to initialize. This is not an error or anything to be concerned about.

	Connect your computer, tablet or phone to the same network, open a web browser and navigate to the IP address shown on the OLED display. You should see the mosaic-X5's internal web page. The web page displays a lot of helpful information and can also be used to fully configure the mosaic-X5.

	The firmware mode, SSID and password are stored in flash (non-volatile) memory. After changing them, you can disconnect the computer and power the RTK mosaic-X5 using the supplied wall adapter.

	<figure markdown>
	WiFi Connections
	<figcaption markdown>[WiFi Connections (PNG)](./assets/img/hookup_guide/WiFi_Connections.png) for the RTK mosaic-X5.</figcaption>
	</figure>

	!!! tip "Not working?"
		The following sections will help if your RTK mosaic-X5 is not working as expected:

		??? info "Using mosaic-X5 firmware >= 4.15.0?"
			With mosaic-X5 firmware 4.15.0, a user-defined username and password are mandatory on all IP interfaces. These must be entered as described in the [Log-in procedure](https://customersupport.septentrio.com/s/article/Cybersecurity-guidelines-Log-in-procedure) on all IP interfaces individually and separately. The ESP32 is connected via COM. It does not need to know the username and password unless you also change default access level for the COM ports. If you do, you need to ensure the RTK mosaic-X5 ESP32 firmware has been [upgraded to version >= 1.0.5](./software_overview.md#esp32-firmware-update) and that the username and password have been set using *set -u* and *set -x*

		??? info "No power?"
			The red power (PWR) LED will light up when the RTK mosaic-X5 has power. If the PWR LED is off, make sure the wall adapter has power and the USB cable is connected.

		??? info "No position information?"
			The OLED display will only show position information (Lat, Long, Alt etc.) once a satellite signal has been acquired. If you see only the IP address on the display, check the SMA to TNC cable is connected correctly and that the antenna is outside with a clear view of the sky. Use a [male-female SMA extension cable](https://www.sparkfun.com/interface-cable-sma-female-to-sma-male-10m-rg58.html) if needed to increase the cable length.

		??? info "No IP address?"
			The mosaic-X5 Ethernet port is configured for Dynamic Host Configuration Protocol (DHCP). It expects the WiFi network to provide it with an IP address. If the IP address is all zeros (0.0.0.0), check that your router has DHCP enabled. Most do.

			Subnet 3 is reserved for the mosaic-X5's USB-C connection (Ethernet-over-USB). If your router / switch is allocating addresses using subnet 3 (192.168.3.***), please change its settings so it uses a different subnet.

		??? info "No web page?"
			If you can not see the mosaic-X5's internal web page, please check that your computer / tablet / phone is connected to the same network. If you are using a phone, check it is connected to the router WiFi - and not using its mobile data connection.

			Subnet 3 is reserved for the mosaic-X5's USB-C connection (Ethernet-over-USB). If your router / switch is allocating addresses using subnet 3 (192.168.3.***), please change its settings so it uses a different subnet. If it is using subnet 3, both the mosaic-X5 and your device will appear to have valid IP addresses but will not be able to communicate.

		??? info "Wrong mode?"
			If you still can not see the mosaic-X5's internal web page, please check that the ESP32 firmware is in the correct mode. Press the **RESET** button to restart the ESP32 and watch the text, which scrolls up the OLED display. You should see **Mode 2: WiFi** displayed briefly. If you see **Mode 1: Ethernet**, the firmware is in the wrong mode. Follow the instructions above to change the mode to **2** (WiFi).

=== "<H2>:material-usb-port:&nbsp;USB-C</H2>"

	The mosaic-X5 has a built-in high-speed USB port which supports Ethernet-over-USB. To take advantage of this interface, you first need to install the Septentrio drivers.

	<figure markdown>
	USB Connections
	<figcaption markdown>[USB Connections (PNG)](./assets/img/hookup_guide/USB_Connections.png) for the RTK mosaic-X5.</figcaption>
	</figure>

	`1` - **Connect the GNSS antenna**
	: * Inside your RTK mosaic-X5 kit, you will find the L1/L2/L5 GNSS "UFO" antenna. It has a TNC connection. Use the supplied TNC-SMA cable to connect the antenna to the mosaic-X5 **MOSAIC** SMA connection.
		* The antenna needs a clear view of the sky. If you are working indoors, put the antenna outside and pass the cable through a window. (Insulating double-glazed windows have a coating which can block the GNSS signal. For best results, put the antenna outside.)
		* If you are going to use your RTK mosaic-X5 as an RTK Base, the antenna needs to be securely mounted to a structure so that it cannot be moved and has a clear view of the sky. Any movement in the antenna will cause inaccurate readings by RTK rovers. Please see the [Required Materials](./introduction.md#required-materials) for links to our [GNSS Antenna Mounting Hardware Kit](https://www.sparkfun.com/gnss-antenna-mounting-hardware-kit.html) and [GNSS Magnetic Antenna Mount - 5/8" 11-TPI](https://www.sparkfun.com/gnss-magnetic-antenna-mount-5-8-11-tpi.html)
	`2` - **Download and install Septentrio RxTools**
	: * The [Septentrio mosaic-X5 Resources page](https://www.septentrio.com/en/products/gps/gnss-receiver-modules/mosaic-x5#resources) has download links for the mosaic-X5 datasheet, firmware, firmware guide, hardware manual, how-to videos and the **RxTools** support tool suite.
		* **RxTools** includes the driver for the USB-C port plus several tools, which you can use to control and configure the mosaic-X5, forward data, log data, analyze the log files, convert the log files to other formats, and configure the module for use with other GIS software.
		* Download and install **RxTools**.
	`3` - **Connect the RTK mosaic-X5 to your computer**
	: * Use the supplied USB-C cable to connect the **CONFIG MOSAIC** port to your computer.

	<!-- Needed to break from list -->
	`4` - **Open the X5 web page**
	: * Open a web browser on your computer and navigate to **192.168.3.1** to view the mosaic-X5's internal web page.

	You can now use the RxTools suite to take full advantage of the sophisticated mosaic-X5.

	!!! tip "Not working?"
		The following sections will help if your RTK mosaic-X5 is not working as expected:

		??? info "Using mosaic-X5 firmware >= 4.15.0?"
			With mosaic-X5 firmware 4.15.0, a user-defined username and password are mandatory on all IP interfaces. These must be entered as described in the [Log-in procedure](https://customersupport.septentrio.com/s/article/Cybersecurity-guidelines-Log-in-procedure) on all IP interfaces individually and separately. The ESP32 is connected via COM. It does not need to know the username and password unless you also change default access level for the COM ports. If you do, you need to ensure the RTK mosaic-X5 ESP32 firmware has been [upgraded to version >= 1.0.5](./software_overview.md#esp32-firmware-update) and that the username and password have been set using *set -u* and *set -x*

		??? info "No power?"
			The red power (PWR) LED will light up when the RTK mosaic-X5 has power. If the PWR LED is off, make sure the USB cable is connected.

		??? info "No position information?"
			The OLED display will only show position information (Lat, Long, Alt etc.) once a satellite signal has been acquired. If you see only an IP address on the display, check the SMA to TNC cable is connected correctly and that the antenna is outside with a clear view of the sky. Use a [male-female SMA extension cable](https://www.sparkfun.com/interface-cable-sma-female-to-sma-male-10m-rg58.html) if needed to increase the cable length.

		??? info "No web page?"
			If you can not see the mosaic-X5's internal web page at **192.168.3.1**, please check that your computer / tablet / phone is connected correctly to the USB-C port.

			Subnet 3 is reserved for the mosaic-X5's USB-C connection (Ethernet-over-USB). If your computer is simultaneously connected to an Ethernet or WiFi network that also uses subnet 3 (192.168.3.***), please change the network settings so it uses a different subnet.

		??? info "Firmware mode"
			You can have the mosaic-X5 connected to your computer via USB-C, while it is also simultaneously connected via Ethernet (firmware mode **1**) or WiFi (firmware mode **2**). If you connect the mosaic-X5 Ethernet port directly to your network or router, ensure the firmware is in mode **1**. If you have the mosaic and ESP32 Ethernet ports linked for WiFi mode, ensure the firmware is in mode **2**.

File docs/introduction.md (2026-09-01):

---
icon: material/book-open-page-variant
---

!!! failure "Deprecated Documentation"
	As of Sept 1, 2026 this guide has been retired. Users can find our latest documentation at: [https://docs.sparkpnt.com/SXM-E](https://docs.sparkpnt.com/SXM-E)

# Introduction
<div class="grid cards desc" markdown>

-   <a href="https://www.sparkpnt.com/products/sparkpnt-sxm-e-cors">
	**RTK mosaic-X5**<br>
	**SKU:** SXM-E

	---

	<figure markdown>
	Product Thumbnail
	</figure></a>

	<article style="text-align: center;" markdown>
	<article class="video-500px">
	<iframe src="https://www.youtube.com/embed/HwKxq9ChazQ" title="Product Showcase Video" frameborder="0" allow="accelerometer; autoplay; clipboard-write; encrypted-media; gyroscope; picture-in-picture" allowfullscreen></iframe>
	</article>
	</article>

	<article style="text-align: center;" markdown>
	[&nbsp;QR code to product page&nbsp;&nbsp;Purchase from SparkPNT :fontawesome-solid-cart-plus:{ .heart }&nbsp;&nbsp;&nbsp;](https://www.sparkpnt.com/products/sparkpnt-sxm-e-cors){ .md-button .md-button--primary }
	</article>

-	Designed and manufactured in Boulder, Colorado, USA, the SparkFun RTK mosaic-X5 is the perfect solution for your high-precision positioning and navigation needs. Based around the multi-constellation, multi-frequency, L5-ready mosaic-X5 from Septentrio, this is our most advanced RTK product to date. It supports GNSS signals from GPS (USA), GLONASS (Russia), Beidou (China), Galileo (Europe), Navic (India) plus special additional satellites (e.g. SBAS and QZSS). The mosaic-X5 also has built-in on-module support for other L-band correction services.

	The RTK mosaic-X5 can be configured as a Real-Time Kinematic (RTK) Base, where it feeds corrections to other RTK Rovers, or as an RTK Rover where it can use corrections to achieve a horizontal positioning accuracy of 6 millimeters (0.6cm) (plus 0.5 PPM). For applications like robotics and autonomous systems, the mosaic-X5 can deliver position updates at 100Hz (100 times per second). The mosaic-X5 is a _very_ sophisticated chip running a full internal web page server; the position can be monitored and the module is fully configured through that web page using a standard browser.

	Under the hood, the RTK mosaic-X5 is powered by the mosaic-X5 GNSS module from Septentrio; and the Espressif ESP32-WROVER processor (16MB flash, 8MB PSRAM). The mosaic-X5 has USB-C connectivity (with Ethernet-over-USB), multiple UARTs and supports full Ethernet connectivity. The only interface it doesn't offer is WiFi and that's why we've included the ESP32 with its own Ethernet connection. You can connect the mosaic-X5 directly to your Ethernet network - our product supports Power-over-Ethernet too. Or you can link the mosaic-X5 Ethernet port to the ESP32 Ethernet port and have the ESP32 provide WiFi connectivity. In that mode, the ESP32 becomes an Ethernet to WiFi Bridge, seamlessly passing WiFi traffic to and from the mosaic-X5 via Ethernet.

</div>

??? question "Product Comparison"
	Below is a simple comparison table between our mosaic-X5 products and Septentrio's development and evaluation kits:

	<div class="annotate" markdown align="center">
	<table markdown>
	<tr markdown>
	<td></td>
	<th markdown style="text-align:center">
		mosaic-X5 Development Kit<br>
		<hr>
		<figure markdown>
		Product Thumbnail
		</figure>
	</th>
	<th markdown style="text-align:center">
		mosaic-go Evaluation Kit<br>
		<hr>
		<figure markdown>
		Product Thumbnail
		</figure>
	</th>
	<th markdown style="text-align:center">
		mosaic-X5 GNSS Breakout<br>
		<hr>
		<figure markdown>
		Product Thumbnail
		</figure>
	</th>
	<th markdown style="text-align:center">
		RTK mosaic-X5<br>
		<hr>
		<figure markdown>
		Product Thumbnail
		</figure>
	</th>
	<th markdown style="text-align:center">
		mosaic-X5 Flex Module<br>
		<hr>
		<figure markdown>
		Product Thumbnail
		</figure>
	</th>
	<th markdown style="text-align:center">
		SparkPNT RTK Facet mosaic<br>
		<hr>
		<figure markdown>
		Product Thumbnail
		</figure>
	</th>
	</tr>
	<tr>
		<td style="vertical-align:middle;">GNSS Antenna</td>
		<td style="text-align:center; vertical-align:middle;">Dual</td>
		<td style="text-align:center">
			Single (mosaic-X5)<br>
			Dual (mosaic-H)
		</td>
		<td style="text-align:center; vertical-align:middle;">Single</td>
		<td style="text-align:center; vertical-align:middle;">Single</td>
		<td style="text-align:center; vertical-align:middle;">Single</td>
		<td style="text-align:center; vertical-align:middle;">Integrated</td>
	</tr>
	<tr>
		<td>USB Connector</td>
		<td style="text-align:center">micro-B</td>
		<td style="text-align:center">micro-B</td>
		<td style="text-align:center">Type-C</td>
		<td style="text-align:center">Type-C</td>
		<td style="text-align:center">N/A*</td>
		<td style="text-align:center">Type-C</td>
	</tr>
	<tr>
		<td style="vertical-align:middle;">Ethernet</td>
		<td style="text-align:center; vertical-align:middle;">
			Yes<br>
			<i>10/100 Base-T</i>
		</td>
		<td style="text-align:center; vertical-align:middle;">No</td>
		<td style="text-align:center; vertical-align:middle;">No</td>
		<td style="text-align:center">
			Yes<br>
			<i>10/100 Base-T</i>
		</td>
		<td style="text-align:center; vertical-align:middle;">2x10 Header*</td>
		<td style="text-align:center; vertical-align:middle;">No</td>
	</tr>
	<tr>
		<td style="vertical-align:middle;">WiFi</td>
		<td style="text-align:center; vertical-align:middle;">No</td>
		<td style="text-align:center; vertical-align:middle;">No</td>
		<td style="text-align:center; vertical-align:middle;">No</td>
		<td style="text-align:center">
			Yes - Network Bridge<br>
			<i>10 Base-T</i>
		</td>
		<td style="text-align:center; vertical-align:middle;">No</td>
		<td style="text-align:center">
			Yes - Network Bridge<br>
			<i>10 Base-T</i>
		</td>
	</tr>
	<tr>
		<td style="vertical-align:middle;">COM Ports</td>
		<td style="text-align:center">4</td>
		<td style="text-align:center">2</td>
		<td style="text-align:center">4</td>
		<td style="text-align:center">
			1 - mosaic-X5<br>
			1 - ESP32
		</td>
		<td style="text-align:center">4</td>
		<td style="text-align:center">
			1 - mosaic-X5<br>
			1 - ESP32
		</td>
	</tr>
	<tr>
		<td>&micro;SD Card Slot</td>
		<td style="text-align:center">Yes</td>
		<td style="text-align:center">Yes</td>
		<td style="text-align:center">Yes</td>
		<td style="text-align:center">Yes</td>
		<td style="text-align:center">2x10 Header*</td>
		<td style="text-align:center">Yes</td>
	</tr>
	<tr>
		<td style="vertical-align:middle;">Reset/Log Buttons</td>
		<td style="text-align:center; vertical-align:middle;">Yes</td>
		<td style="text-align:center; vertical-align:middle;">No*</td>
		<td style="text-align:center; vertical-align:middle;">Yes</td>
		<td style="text-align:center; vertical-align:middle;">Yes</td>
		<td style="text-align:center; vertical-align:middle;">No</td>
		<td style="text-align:center; vertical-align:middle;">Yes</td>
	</tr>
	<tr>
		<td style="vertical-align:middle;">Logic-Level</td>
		<td style="text-align:center">
			1.8V<br>
			3.3V
		</td>
		<td style="text-align:center; vertical-align:middle;">3.3V</td>
		<td style="text-align:center; vertical-align:middle;">3.3V</td>
		<td style="text-align:center">
			3.3V<br>
			5V
		</td>
		<td style="text-align:center; vertical-align:middle;">3.3V</td>
		<td style="text-align:center; vertical-align:middle;">3.3V</td>
	</tr>
	<tr>
		<td>PPS Signal</td>
		<td style="text-align:center">Header Pin</td>
		<td style="text-align:center">6-Pin JST Connector</td>
		<td style="text-align:center">SMA Connector</td>
		<td style="text-align:center">Screw Terminal</td>
		<td style="text-align:center">2x10 Header*</td>
		<td style="text-align:center">No</td>
	</tr>
	<tr>
		<td>Enclosure Material</td>
		<td style="text-align:center; vertical-align:middle;">N/A</td>
		<td style="text-align:center; vertical-align:middle;">Metal</td>
		<td style="text-align:center; vertical-align:middle;">N/A</td>
		<td style="text-align:center; vertical-align:middle;">Aluminum</td>
		<td style="text-align:center; vertical-align:middle;">N/A</td>
		<td style="text-align:center; vertical-align:middle;">Plastic</td>
	</tr>
	<tr>
		<td style="vertical-align:middle;">Dimensions</td>
		<td style="text-align:center; vertical-align:middle;">N/A</td>
		<td style="text-align:center; vertical-align:middle;">71 x 59 x 12mm ± 1mm</td>
		<td style="text-align:center; vertical-align:middle;">70.9 x 50.8 x 8mm</td>
		<td style="text-align:center">
			180.6 x 101.8 x 41mm<br>
			<i>Enclosure Only</i>
		</td>
		<td style="text-align:center; vertical-align:middle;"></td>
		<td style="text-align:center; vertical-align:middle;"></td>
	</tr>
	<tr>
		<td style="vertical-align:middle;">Weight</td>
		<td style="text-align:center; vertical-align:middle;">N/A</td>
		<td style="text-align:center; vertical-align:middle;">58g  ± 1g</td>
		<td style="text-align:center; vertical-align:middle;">22.6g</td>
		<td style="text-align:center">
			415.15g<br>
			<i>Enclosure Only</i>
		</td>
		<td style="text-align:center; vertical-align:middle;"></td>
		<td style="text-align:center; vertical-align:middle;"></td>
	</tr>
	
	</table>
	
	</div>

	!!! note "mosaic-go Evaluation Kit"
		The reset pin is exposed on 4-pin JST connector and the log pin is connected to the latch pin of the SD card slot.

	!!! note "mosaic-5 Flex Module"
		SparkPNT GNSS Flex modules are modular, *plug-in* boards that utilize a *carrier* board to access the pins of the GNSS Flex headers.

## :fontawesome-solid-list-check:&nbsp;Required Materials
The RTK mosaic-X5 comes with everything you need to get up and running.

**Kit Contents**

---

<div class="grid" markdown>

<div markdown>

<figure markdown>

Kit contents (https://cdn.sparkfun.com/assets/parts/2/4/0/7/2/23748-RTK-Mosaic-X5-Kit-All.jpg "Click to enlarge")
<figcaption markdown>Everything that is included in the RTK mosaic-X5 kit.</figcaption>
</figure>

</div>

<div markdown>

<div class="annotate" markdown>

* [Quick Start Guide](./assets/quick_start_guide-v10.pdf)
* Cased GNSS Receiver
	* [Aluminum Enclosure](https://www.sparkfun.com/metal-enclosure-custom-aluminum-extrusion-6in-x-4in-pcb.html) (1)
	* [10-Way Terminal Blocks](https://www.sparkfun.com/10-way-terminal-socket.html)
	* [Qwiic 1.3" OLED Display](https://www.sparkfun.com/sparkfun-qwiic-oled-1-3in-128x64.html)
* [L1/L2/L5 GNSS Surveying Antenna](https://www.sparkfun.com/gnss-multi-band-l1-l2-l5-surveying-antenna-tnc-spk6618h.html)
* [Reinforced RG58 TNC-SMA Cable (10m)](https://www.sparkfun.com/reinforced-interface-cable-sma-male-to-tnc-male-10m.html)
* [SMA WiFi / Bluetooth Antenna](https://www.sparkfun.com/2-4ghz-duck-antenna-rp-sma.html)
* [32GB microSD Card (Class 10)](https://www.sparkfun.com/microsd-card-32gb-class-10.html)
* [USB-C Power Supply (5V 1A wall adapter)](https://www.sparkfun.com/usb-wall-charger-5v-1a-black.html)
* [USB-C Cable (A to C, 2m)](https://www.sparkfun.com/reversible-usb-a-to-c-cable-2m.html)
* [Ethernet Cable (CAT-6, 1m)](https://www.sparkfun.com/cat-6-cable-3ft.html)

</div>
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

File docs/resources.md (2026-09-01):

---
icon: material/book-open-page-variant
---

!!! failure "Deprecated Documentation"
	As of Sept 1, 2026 this guide has been retired. Users can find our latest documentation at: [https://docs.sparkpnt.com/SXM-E](https://docs.sparkpnt.com/SXM-E)

## Product Resources

* :sfe: [Product Page](https://www.sparkpnt.com/products/sparkpnt-sxm-e-cors)
* [Quick Start Guide](./assets/quick_start_guide-v10.pdf)
* :material-folder-cog: Design Files:
	* :fontawesome-solid-file-pdf: [Schematic](./assets/board_files/schematic.pdf)
	* :fontawesome-solid-file-pdf: [Board Dimensions](./assets/board_files/dimensions.pdf)
	* :fontawesome-solid-file-pdf: [Enclosure Dimensions](./assets/board_files/dimensions-enclosure.pdf)
	* :fontawesome-solid-file-code: [ESP32 Firmware](https://github.com/sparkfun/SparkFun_RTK_mosaic-X5/tree/main/Firmware/RTK_mosaic-X5_Firmware)
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

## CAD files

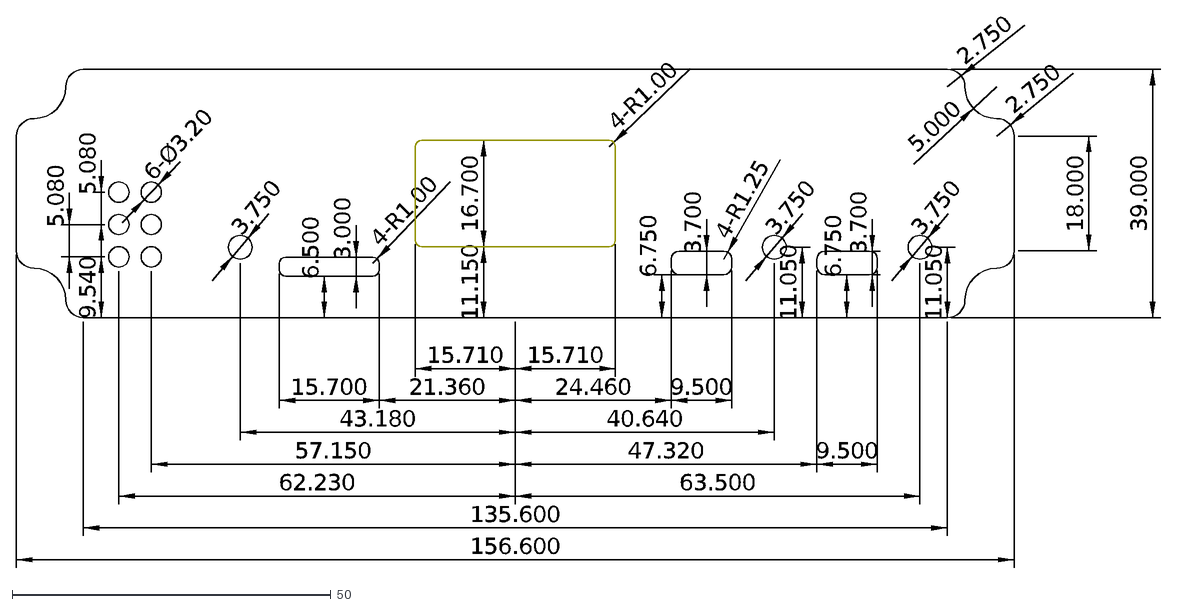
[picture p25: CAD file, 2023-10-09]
Front_Sticker/RTK_mosaic-X5_Front_Sticker.dxf
18.000
39.000
2.750
5.000
3.750
24.460
9.500
40.640
47.320
63.500
15.710
21.360
15.700
43.180
57.150
62.230
6-Ø3.20
135.600
156.600
11.150
16.700
4-R1.00
9.540
5.080
6.500
3.000
6.750
3.700
11.050
4-R1.25

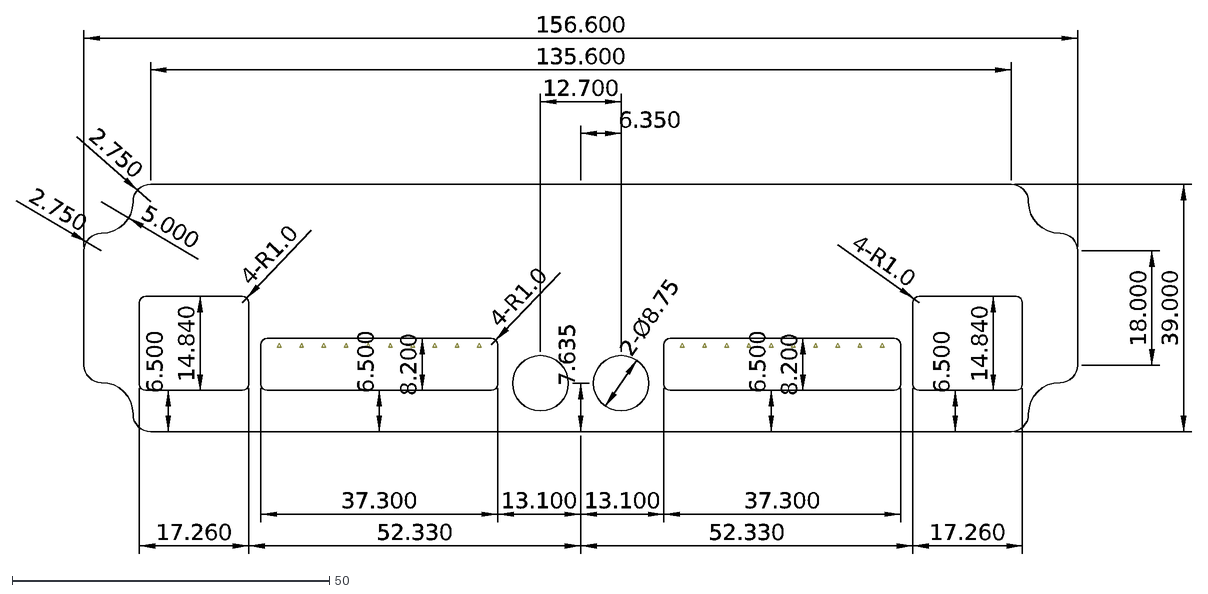
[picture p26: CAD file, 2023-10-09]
Rear_Sticker/RTK_mosaic-X5_Rear_Sticker.dxf
6.350
12.700
13.100
37.300
52.330
17.260
135.600
156.600
18.000
39.000
2.750
5.000
2-Ø8.75
4-R1.0
6.500
8.200
14.840
7.635

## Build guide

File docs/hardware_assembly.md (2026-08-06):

---
icon: material/tools
---

!!! warning
	When assembling the RTK mosaic-X5, users should attach any power connections last. While there shouldn't be any issues with hot-swapping peripherals, it is common practice to power electronics as the last step of the assembly process *(and the power should be disconnected before removing components)*.

??? info "What is in the Box?"
	The RTK mosaic-X5 comes packaged as a complete kit, with all the accessories you'd need to set up an RTK base station.

	<figure markdown>
	Kit contents (https://cdn.sparkfun.com/assets/parts/2/4/0/7/2/23748-RTK-Mosaic-X5-Kit-All.jpg "Click to enlarge")
	<figcaption markdown>Everything that is included in the RTK mosaic-X5 kit.</figcaption>
	</figure>

	Inside the box, users will find the [GNSS antenna](https://www.sparkfun.com/gnss-multi-band-l1-l2-l5-surveying-antenna-tnc-spk6618h.html), RTK mosaic-X5 in its aluminum enclosure, and another box containing additional accessories. Inside, the accessory box, users will find the [CAT-6 Ethernet cable](https://www.sparkfun.com/cat-6-cable-3ft.html), [USB cable](https://www.sparkfun.com/reversible-usb-a-to-c-cable-2m.html), [SMA to TNC cable](https://www.sparkfun.com/reinforced-interface-cable-sma-male-to-tnc-male-10m.html), [USB power supply](https://www.sparkfun.com/usb-wall-charger-5v-1a-black.html), [WiFi antenna](https://www.sparkfun.com/2-4ghz-duck-antenna-rp-sma.html), and [32GB SD card](https://www.sparkfun.com/microsd-card-32gb-class-10.html).

	<div class="grid" markdown>

	<div markdown>

	<figure markdown>
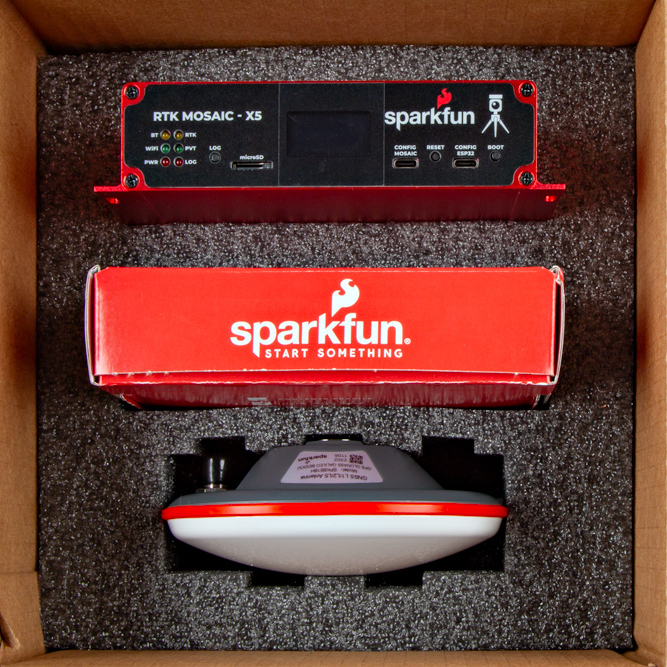
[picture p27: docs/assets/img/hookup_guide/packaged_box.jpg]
Kit contents
	
	<figcaption markdown>The contents of the RTK mosaic-X5 package.</figcaption>
	</figure>

	</div>

	<div markdown>

	<figure markdown>
	Kit contents (https://cdn.sparkfun.com/assets/parts/2/4/0/7/2/23748-RTK-Mosaic-X5-Kit-Accessories.jpg "Click to enlarge")
	<figcaption markdown>Products in the accessories box.</figcaption>
	</figure>

	</div>

	</div>

## USB-C Ports
The USB ports are utilized to configure the mosaic-X5 module and ESP32 WiFi settings. Additionally, the USB ports can also be used as a power source for the RTK mosaic-X5.

<!-- Reworded
The USB port for the mosaic-X5 is used for serial communication to stream the GNSS data and to access the SD card as a mass storage device. With the default firmware, the USB port for the ESP32 is used for serial communication to configure the network settings of the Ethernet-to-WiFi bridge.
-->

<div class="grid" markdown>

<div markdown>

The USB port to the mosaic-X5 can be used to configure the module through an IP port, for serial communication to stream the GNSS data, and access the SD card as a mass storage device. To connect to the mosaic-X5, users only need to plug a USB-C cable into the `CONFIG MOSAIC` USB port and their computer.

<figure markdown>
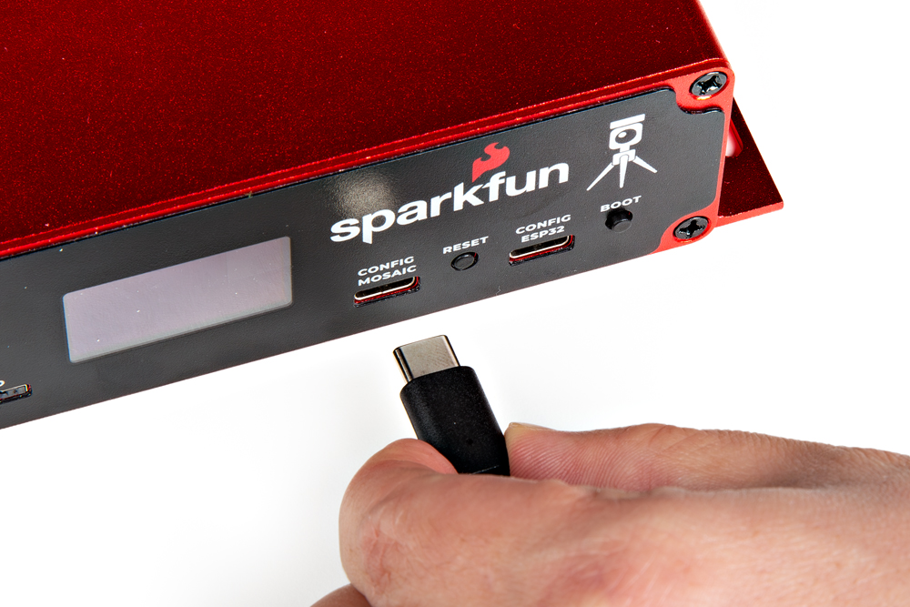
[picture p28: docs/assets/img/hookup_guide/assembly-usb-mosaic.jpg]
mosaic-X5 USB connection

<figcaption markdown>The RTK mosaic-X5 with USB-C cable being attached.</figcaption>
</figure>

</div>

<div markdown>

With the default firmware, the USB port for the ESP32 is used for serial communication to configure the network settings of the Ethernet-to-WiFi bridge. To configure the network settings for the ESP32, users only need to plug a USB-C cable into the `CONFIG ESP32` USB port and their computer.

<figure markdown>
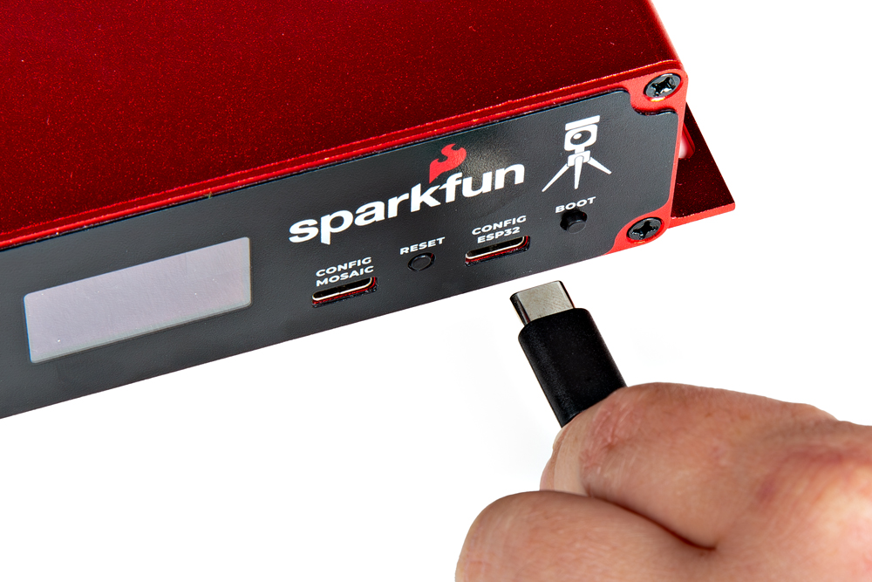
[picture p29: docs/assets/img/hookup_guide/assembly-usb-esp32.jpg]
ESP32 USB connection

<figcaption markdown>The RTK mosaic-X5 with USB-C cable being attached.</figcaption>
</figure>

</div>

</div>

!!! tip "Software Requirements"
	Depending on their computer's operating system, users may need to install USB drivers to interface with the mosaic-X5 and/or the ESP32. Users may also need to install a terminal emulator for serial communication with the mosaic-X5 and the ESP32.

## Antennas

<div class="grid" markdown>

<div markdown>

In order to receive [GNSS](https://en.wikipedia.org/wiki/Satellite_navigation "Global Navigation Satellite System") signals, users will need a compatible antenna. With the parts included in this kit, connect the L1/L2/L5 (tri-band) GNSS antenna to the RTK mosaic-X5 using the TNC-to-SMA cable.

<figure markdown>
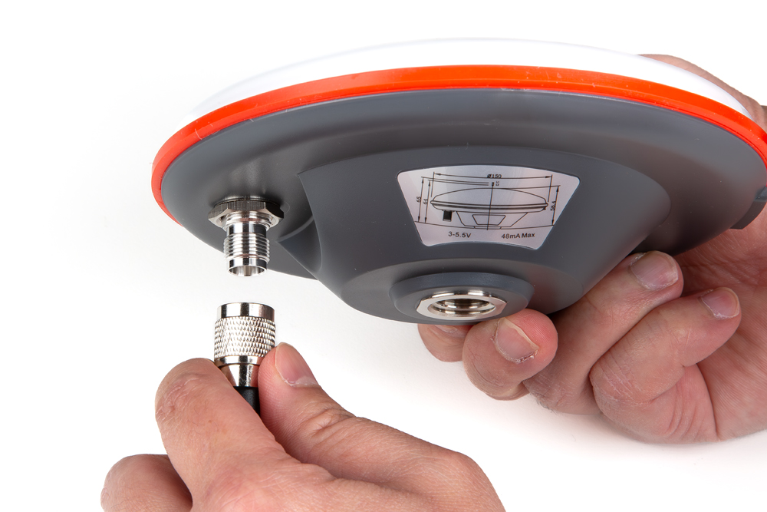
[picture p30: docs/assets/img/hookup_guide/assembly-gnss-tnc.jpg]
GNSS antenna connected to the cable

<figcaption markdown>Attaching a tri-band GPS antenna to the TNC-SMA cable.</figcaption>
</figure>

<figure markdown>
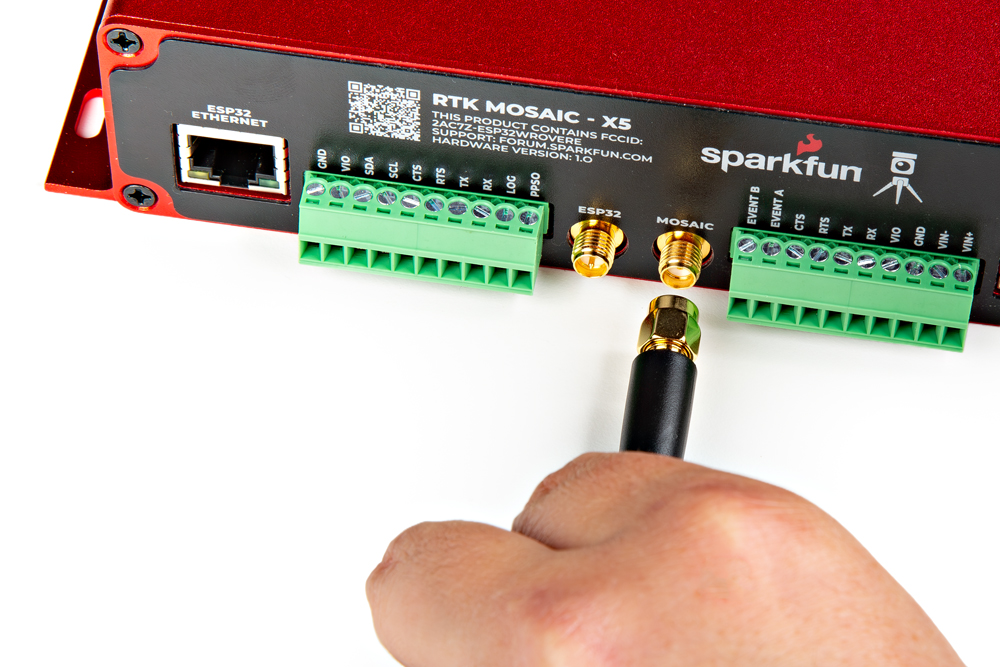
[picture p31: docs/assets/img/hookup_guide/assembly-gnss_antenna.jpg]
GNSS antenna connected to the RTK mosaic-X5

<figcaption markdown>Attaching a TNC-SMA cable to the SMA connector on the RTK mosaic-X5.</figcaption>
</figure>

</div>

<div markdown>

For the WiFi connection, users will need a compatible antenna. Connect the WiFi antenna, included in this kit, to the RTK mosaic-X5.

<figure markdown>
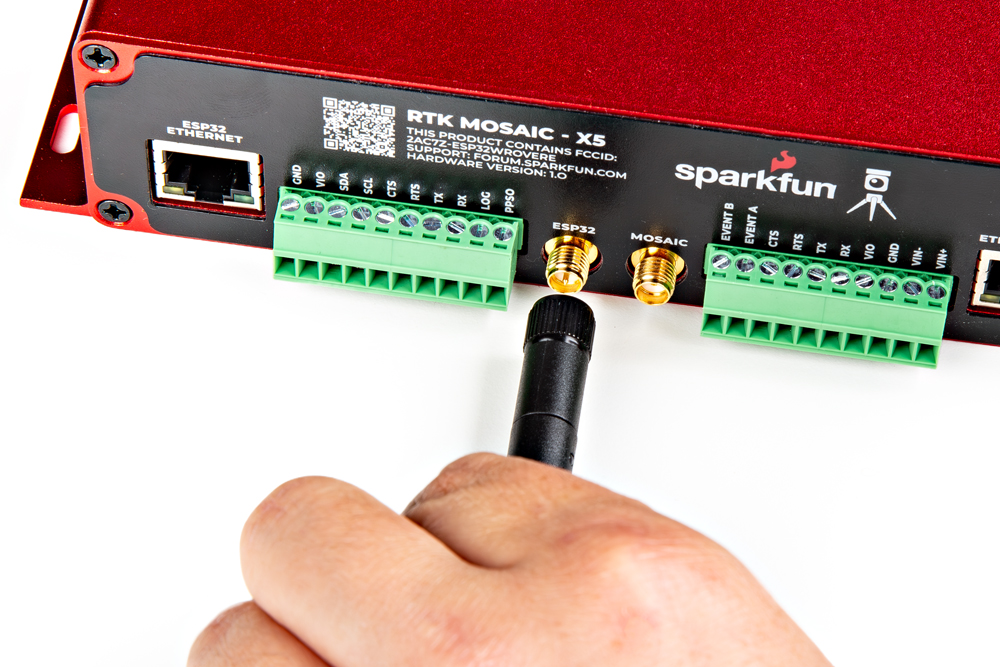
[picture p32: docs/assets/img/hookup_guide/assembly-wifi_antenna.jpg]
WiFi antenna connected to the RTK mosaic-X5

<figcaption markdown>Attaching a 2.4GHz WiFi antenna to the RP-SMA connector on the RTK mosaic-X5.</figcaption>
</figure>

!!! warning "WiFi Network Compatibility"
	The ESP32 is only compatible with 2.4GHz bands and cannot access the 5GHz band.
	The ESP32 firmware we provide is only compatible with basic `SSID` and `Password` WiFi authentication.

	* The firmware is not compatible with networks that implement other provisioning methods such as a [captive portal](https://en.wikipedia.org/wiki/Captive_portal), a QR code, or [Wi-Fi protected setup](https://en.wikipedia.org/wiki/Wi-Fi_Protected_Setup "WPS").

</div>

</div>

??? tip "Mounting Location"
	Users should mount their GNSS antenna outside, where it will have a clear, unobstructed view of the sky. Avoid areas with nearby buildings, EMF structures (i.e. radio towers or power lines), and vegetation (i.e. trees). These objects can increase errors due to signal muti-path, interference, and elevated noise plane.

	<figure markdown>
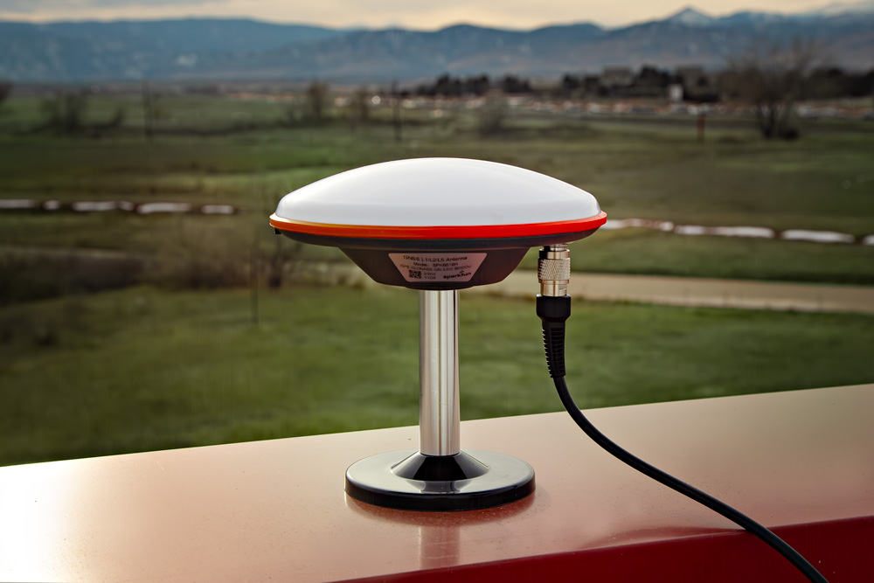
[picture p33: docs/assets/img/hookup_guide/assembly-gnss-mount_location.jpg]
GNSS antenna connected to the RTK mosaic-X5
	
	<figcaption markdown>The tri-band GPS antenna, mounted outside with an unobstructed view of the sky.</figcaption>
	</figure>

??? tip "Connector Polarity"
	When selecting antennas and/or cables for the RTK mosaic-X5, double-check the polarity of the connection.

## Ethernet Jacks
There are two ethernet jacks on the RTK mosaic-X5, which can be used to provide network access to the mosaic-X5 module. In addition, one of the ethernet jacks supports [power over ethernet (PoE)](https://en.wikipedia.org/wiki/Power_over_Ethernet "PoE") to power the device.

=== "Basic Network"
	The jack to the mosaic-X5 allows users to provide internet access and power; it supports [PoE](https://en.wikipedia.org/wiki/Power_over_Ethernet "Power over Ethernet"). To provide network access, users should connect the RTK mosaic-X5 from the `MOSAIC ETHERNET (PoE)` jack to their local network with the (CAT-6) ethernet cable provided in the kit.

	* To power the device, a PoE network switch or PoE injector should be installed in between the network connection to the RTK mosaic-X5.
	<!-- * For a WiFi connection, connect the provided (CAT-6) ethernet cable between the `MOSAIC ETHERNET (PoE)` and `ESP32 ETHERNET` jacks on the RTK mosaic-X5. -->

	<figure markdown>
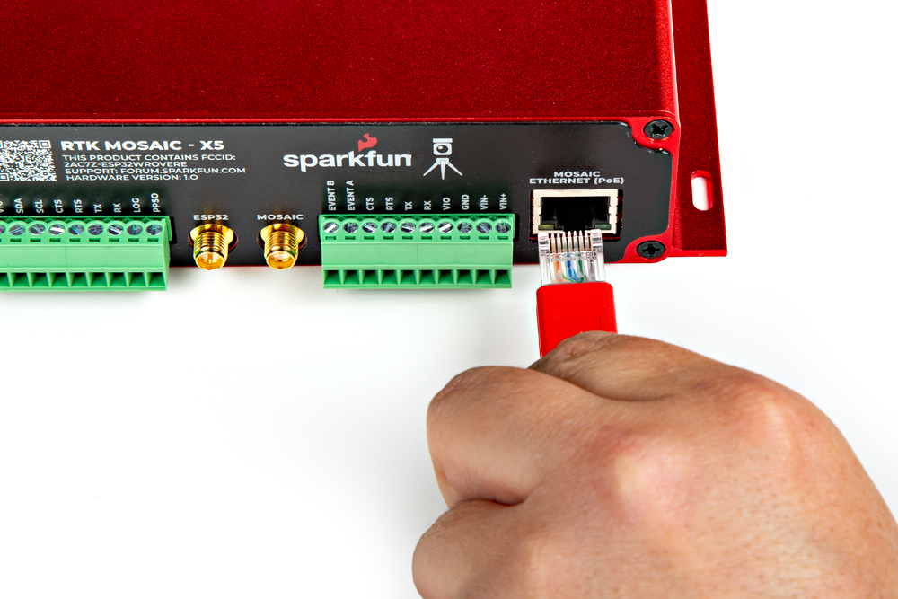
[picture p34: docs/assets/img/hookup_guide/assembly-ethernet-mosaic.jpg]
mosaic-X5 PoE connection
	
	<figcaption markdown>The RTK mosaic-X5 with ethernet cable being attached to the `MOSAIC ETHERNET (PoE)` jack.</figcaption>
	</figure>

=== "WiFi Bridge"
	The jack to the ESP32 allows users to provide WiFi access to the mosaic-X5, by utilizing the ESP32 as a WiFi network bridge.

	<figure markdown>
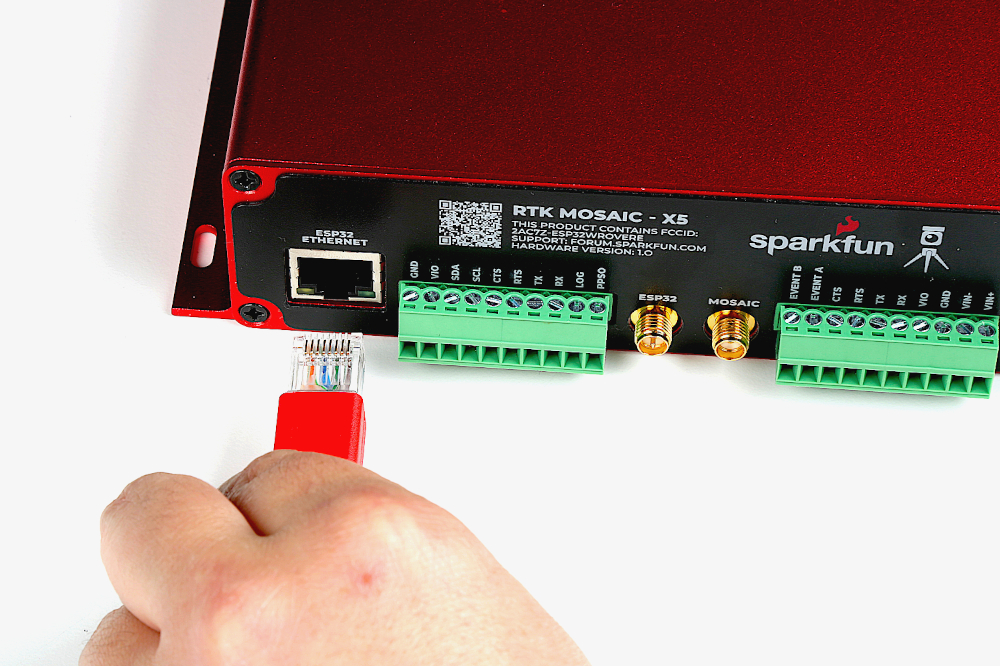
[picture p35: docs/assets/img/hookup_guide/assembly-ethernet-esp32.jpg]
ESP32 ethernet connection
	
	<figcaption markdown>The RTK mosaic-X5 with an ethernet cable being attached to the `ESP32 ETHERNET` jack.</figcaption>
	</figure>

	To set up the WiFi bridge, connect the provided (CAT-6) ethernet cable between the `MOSAIC ETHERNET (PoE)` and `ESP32 ETHERNET` jacks on the RTK mosaic-X5.

	<figure markdown>
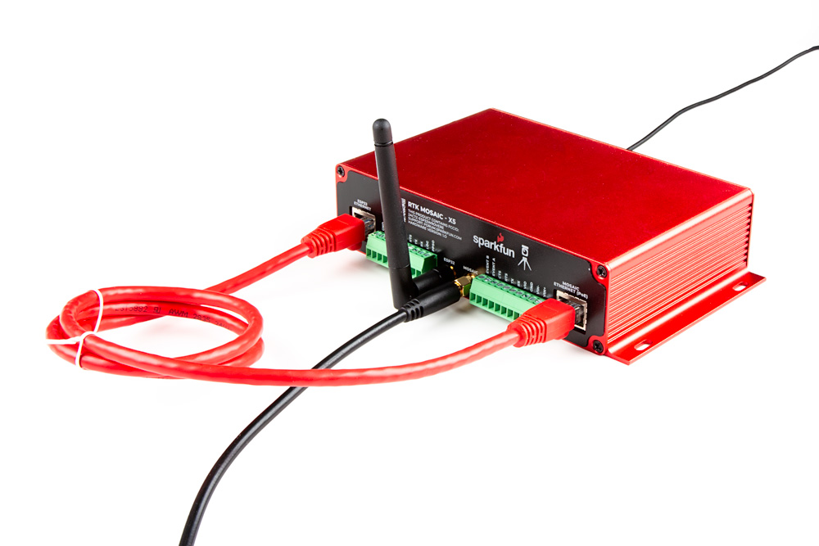
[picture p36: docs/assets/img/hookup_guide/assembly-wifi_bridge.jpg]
	
	<figcaption markdown>The RTK mosaic-X5 with an ethernet cable connected between the `MOSAIC ETHERNET (PoE)` and `ESP32 ETHERNET` jacks.</figcaption>
	</figure>

	??? tip "Configure WiFi Connection"
		Users will need to configure the WiFi connection for the ESP32, through the `CONFIG ESP32` USB-C port.

	??? warning "Cable Management"
		Users should avoid wrapping the ethernet cable around the WiFi antenna; doing so will result in the loss of data packets and cause the web page to freeze. If users must coil the wiring, we recommend that the coil be placed at least 2-3" away from the WiFi antenna.

		<figure markdown>
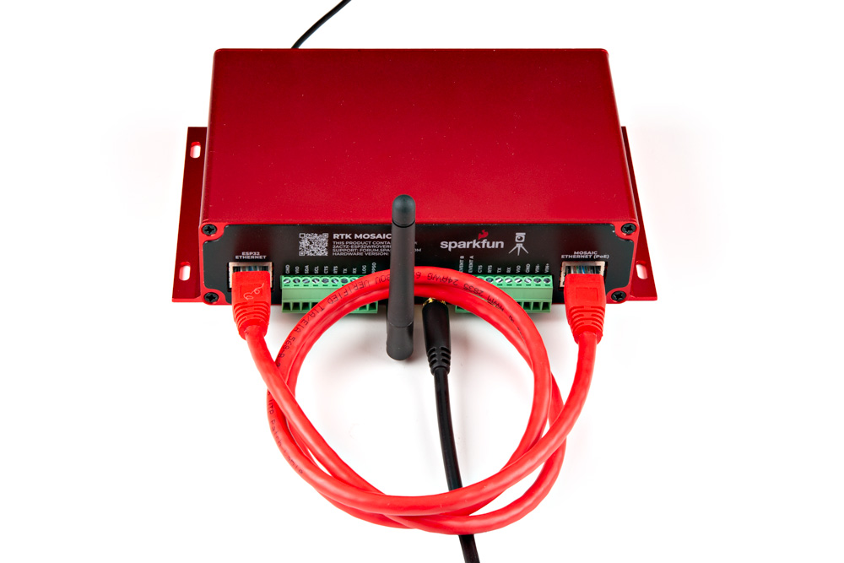
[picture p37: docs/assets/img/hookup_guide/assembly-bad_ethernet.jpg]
Bad ESP32 ethernet connection
		
		<figcaption markdown>Do not wrap/coil the ethernet cable around the WiFi antenna.</figcaption>
		</figure>

??? tip "Configuration: mosaic-X5 Settings"
	Users can configure the mosaic-X5 module through the network connection (i.e. ethernet or WiFi).

## SD Card Slot
An &micro;SD card slot is available for users to log and store data, locally on the board. Users will need to insert a compatible SD card and configure the mosaic-X5 module for data logging.

<figure markdown>
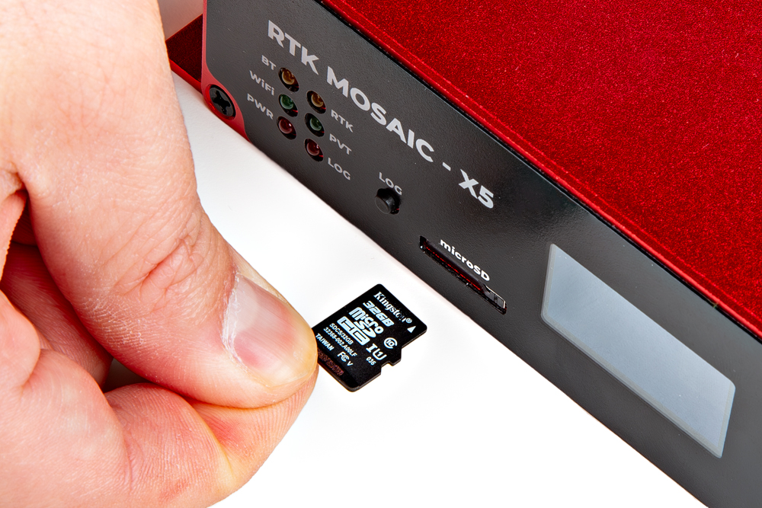
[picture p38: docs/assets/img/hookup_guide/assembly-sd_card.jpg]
RTK mosaic-X5 SD card slot

<figcaption markdown>Inserting an SD card into the RTK mosaic-X5.</figcaption>
</figure>

!!! info "SD Card Compatibility"
	The mosaic-X5 supports &micro;SD cards with a **FAT32** file system *(i.e. only cards **up to 32GB** in size)*.

??? warning "Initial Configuration"
	Before logging can take place, it is necessary to define a "logging stream" using the **Logging** page or **RxTools**. Streams can contain NMEA or SBF (Septentrio Binary Format) data; SBF can contain RTCM and/or RINEX.

	<figure markdown>
	Logging stream configuration
	<figcaption markdown>microSD logging stream configuration.</figcaption>
	</figure>

	!!! tip "Instructional Video"
		:material-youtube: [How to log data to the SD card of the Septentrio mosaic receiver module](https://youtu.be/Y9tvOebnoxk)

??? tip "Button Operation"
	There are multiple ways to configure and enable data logging to an SD card. However, the simplest method is with the ++"LOG"++ button. Once the stream is defined,

	* Pressing the ++"LOG"++ button *(< 5s)* toggles data logging to the SD card on and off.
	* Holding the ++"LOG"++ button for more than 5 seconds *(> 5s)* and then releasing it, will force the board to:
		* Unmount the SD card if it was mounted
		* Mount the SD card if it was unmounted

	For more information, please reference the [SD Card Slot](../hardware_overview/#sd-card-slot) section.

## IO Terminals
Users can easily attach accessories to the RTK mosaic-X5 by wiring them into the terminal blocks on the back of the enclosure.

<figure markdown>
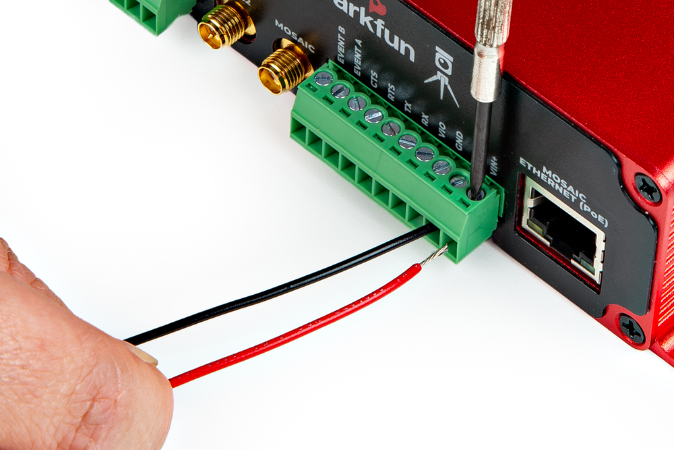
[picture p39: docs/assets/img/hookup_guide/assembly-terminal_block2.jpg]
Terminal Block

<figcaption markdown>Connecting a wire to the terminal block.</figcaption>
</figure>

??? tip "Multiple Connections"
	For multiple connections or wiring harnesses, users can disconnect the terminal blocks from their sockets on the RTK mosaic-X5.

	<figure markdown>
	Disassembled Terminal Block (https://cdn.sparkfun.com/assets/parts/2/2/5/2/5/22461-_PRT_10-Way_Terminal___Socket-_01.jpg "Click to enlarge")
	<figcaption markdown>Components of the terminal block.</figcaption>
	</figure>

	Users can wiggle or use a soft/rigid object to carefully pry the terminal block off from its connector. In the picture below, a plastic name tag (~1.5mm thick) is used to carefully pry the terminal block up. We have also found the edge of a [PCB ruler](https://www.sparkfun.com/sparkfun-pcb-ruler-12-inch.html) works great too.

	<figure markdown>
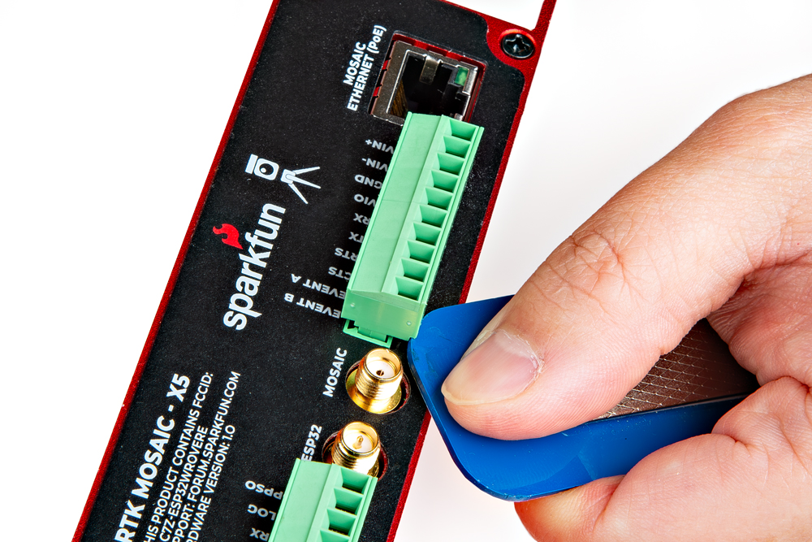
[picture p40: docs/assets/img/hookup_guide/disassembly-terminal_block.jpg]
Prying the Terminal Block
	
	<figcaption markdown>Using a soft/rigid object to carefully pry the terminal block free from its socket.</figcaption>
	</figure>

	Once wired up, users can simply push the terminal block back into its socket.

	<div class="grid" markdown>

	<div markdown>

	<figure markdown>
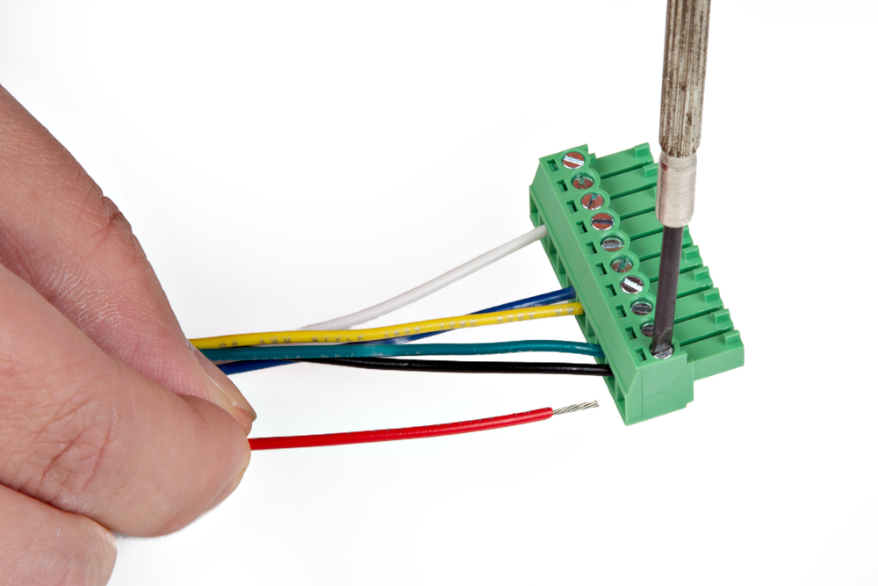
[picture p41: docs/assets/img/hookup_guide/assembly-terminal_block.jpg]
Terminal Block
	
	<figcaption markdown>Connecting a wire to the terminal block.</figcaption>
	</figure>

	</div>

	<div markdown>

	<figure markdown>
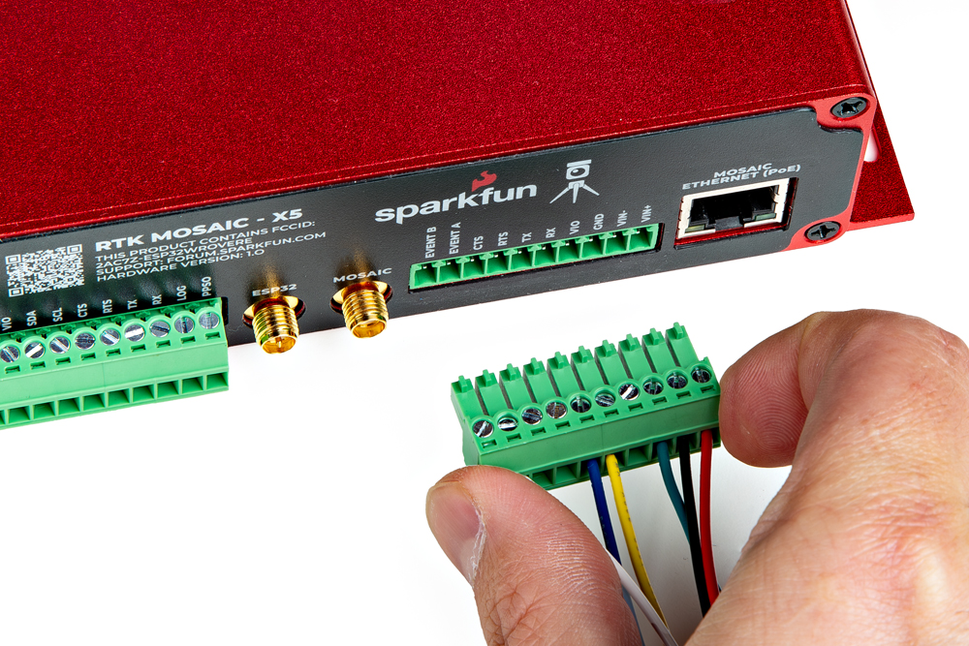
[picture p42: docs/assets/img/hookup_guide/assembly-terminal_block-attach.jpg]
Terminal Block
	
	<figcaption markdown>Attaching the terminal block to its socket on the RTK mosaic-X5.</figcaption>
	</figure>

	</div>

	</div>

	!!! warning
		To avoid shorts or damaging the RTK mosaic-X5, verify the wiring with the labels on the back of the enclosure.

??? tip "Connecting a Radio"
	### Radio Transceivers
	Users can also utilize the terminal blocks to interface with one of our radio transceivers for RTK correction data. We recommend utilizing our [breadboard cable](https://www.sparkfun.com/breadboard-to-jst-ghr-06v-cable-6-pin-x-1-25mm-pitch-for-loraserial.html) to connect those radios to the RTK mosaic-X5.

	<div class="grid cards col-2" markdown>

	-   <a href="https://www.sparkfun.com/sik-telemetry-radio-v3-915mhz-100mw.html">
		<figure markdown>
		Product Thumbnail
		</figure>

		---

		**SiK Telemetry Radio V3 - 915MHz, 100mW**<br>
		WRL-19032</a>

	-   <a href="https://www.sparkfun.com/sparkfun-loraserial-kit-915mhz-enclosed.html">
		<figure markdown>
		Product Thumbnail
		</figure>

		---

		**SparkFun LoRaSerial Kit - 915MHz (Enclosed)**<br>
		WRL-20029</a>
	
	-   <a href="https://www.sparkfun.com/breadboard-to-jst-ghr-06v-cable-6-pin-x-1-25mm-pitch-for-loraserial.html">
		<figure markdown>
		Product Thumbnail
		</figure>

		---

		**Breadboard to JST-GHR-06V Cable - 6-Pin x 1.25mm Pitch (For LoRaSerial)**<br>
		CAB-23353</a>

	</div>

	!!! info "Wiring the Connections"
		When connecting the RTK mosaic-X5 to one of our radio transceivers, users need to be aware of the pin connections between the products. Although the labels on each device may vary, their pins will function the same *(except for the power input/output pins)*.

		!!! warning
			Please remember that the power output (`VIO`) is preset to **3.3V** by default. When utilizing the SiK telemetry radios, users will need to open the enclosure and move the [`VIO` switch](../hardware_overview/#vio--gnd).

		=== "Radios"
			Below is a diagram of the pin connections for the 6-pin JST GH connector on the radios, which should be also labeled on their enclosure.

			<figure markdown>
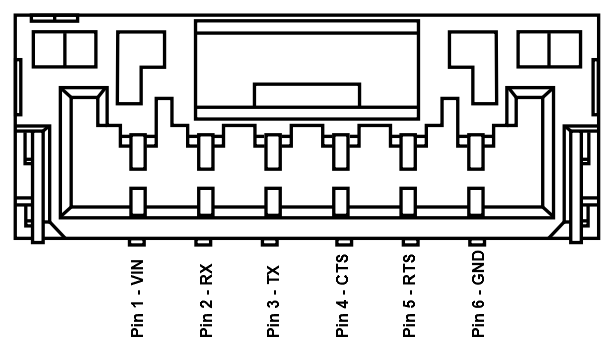
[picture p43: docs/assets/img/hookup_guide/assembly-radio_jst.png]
JST pins
			
			<figcaption markdown>The pin connections for the JST connector on the radios.</figcaption>
			</figure>

			<article style="text-align: center;" markdown>

			<table border="1" markdown>
			<tr>
			<th style="vertical-align:middle;">Label</th>
			<td align="center">`5V`</td>
			<td align="center">`RX/RXI`</td>
			<td align="center">`TX/TXO`</td>
			<td align="center">`CTS`</td>
			<td align="center">`RTS`</td>
			<td align="center">`GND`</td>
			</tr>
			<tr>
			<th style="vertical-align:middle;">Function</th>
			<td>**Voltage Input**<br>
				- SiK: 5V<br>
				- LoRaSerial: 3.3 to 5V</td>
			<td align="center" style="vertical-align:middle;">UART - Receive</td>
			<td align="center" style="vertical-align:middle;">UART - Transmit</td>
			<td align="center" style="vertical-align:middle;">Flow Control<br>
				*Clear-to-Send*</td>
			<td align="center" style="vertical-align:middle;">Flow Control<br>
				*Ready-to-Send*</td>
			<td align="center" style="vertical-align:middle;">Ground</td>
			</tr>
			</table>

			</article>

		=== "RTK mosaic-X5"
			Below are the UART pin connections to the mosaic-X5 GNSS receiver, which are labeled for the terminal blocks on the RTK mosaic-X5 enclosure.

			<figure markdown>
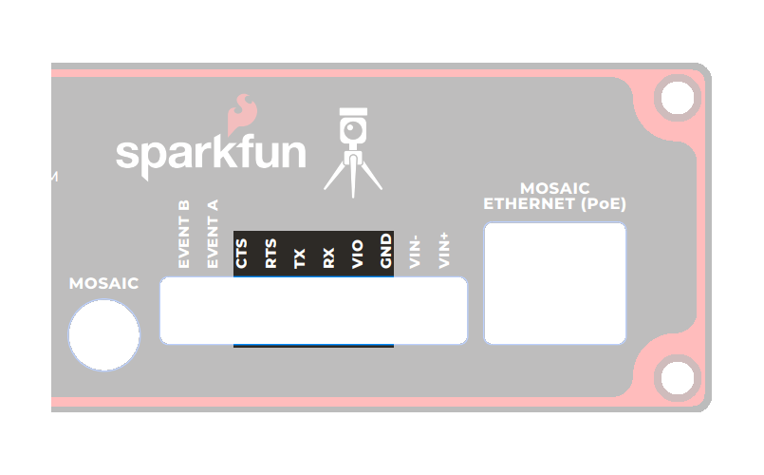
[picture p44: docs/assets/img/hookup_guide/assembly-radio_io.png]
Radio pins to the mosaic-X5
			
			<figcaption markdown>The pin connections for the radio on the RTK mosaic-X5.</figcaption>
			</figure>

			<article style="text-align: center;" markdown>

			<table border="1" markdown>
			<tr>
			<th style="vertical-align:middle;">Label</th>
			<td align="center">`VIO`</td>
			<td align="center">`RX`</td>
			<td align="center">`TX`</td>
			<td align="center">`CTS`</td>
			<td align="center">`RTS`</td>
			<td align="center">`GND`</td>
			</tr>
			<tr>
			<th style="vertical-align:middle;">Function</th>
			<td>**Voltage Output**<br>
				- 5V or 3.3V *(see [switch](../hardware_overview/#vio--gnd))*</td>
			<td align="center" style="vertical-align:middle;">UART - Receive</td>
			<td align="center" style="vertical-align:middle;">UART - Transmit</td>
			<td align="center" style="vertical-align:middle;">Flow Control<br>
				*Clear-to-Send*</td>
			<td align="center" style="vertical-align:middle;">Flow Control<br>
				*Ready-to-Send*</td>
			<td align="center" style="vertical-align:middle;">Ground</td>
			</tr>
			</table>

			</article>

		When connecting the RTK mosaic-X5 to either of the radios, the wiring connections should follow the table below. If the flow control is not enabled, then only the `RX`, `TX`, and `GND` pins are utilized. As an example, the wiring between a host system *(i.e. RTK mosaic-X5)* and the LoRaSerial Kit radio is shown in the image below; as documented in the [LoRaSerial product manual](https://docs.sparkfun.com/SparkFun_LoRaSerial).

		<div class="grid" markdown>

		<div markdown>

		<article style="text-align: center;" markdown>

		<table markdown>
		<tr>
		<th>RTK mosaic-X5</th>
		<td align="center">RX</td>
		<td align="center">TX</td>
		<td align="center">RTS</td>
		<td align="center">CTS</td>
		<td align="center">GND</td>
		</tr>
		<tr>
		<th>Radio</th>
		<td align="center">TX</td>
		<td align="center">RX</td>
		<td align="center">CTS</td>
		<td align="center">RTS</td>
		<td align="center">GND</td>
		</tr>
		</table>

		</article>

		</div>
		
		<div markdown>

		<figure markdown>
		Flow Control (https://docs.sparkfun.com/SparkFun_LoRaSerial/img/SAMD21%20Flow%20control.png "Click to enlarge")
		<figcaption markdown>Wiring instructions for the LoRaSerial radio.<br>Source: [LoRaSerial product manual](https://docs.sparkfun.com/SparkFun_LoRaSerial)</figcaption>
		</figure>

		</div>

		</div>

		??? tip "Pairing Radios"
			By default, the radios in the LoRaSerial Kit - 915MHz are pre-configured for [point-to-point](https://docs.sparkfun.com/SparkFun_LoRaSerial/operating_modes/#point-to-point) communication and a paired with each other. *For instructions on other configurations, please reference the [product manual](https://docs.sparkfun.com/SparkFun_LoRaSerial/) for the LoRaSerial Kit.*

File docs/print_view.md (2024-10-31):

---
hide:
  - navigation
  - toc
icon: material/printer
---

--8<-- "./docs/introduction.md:5"

# Quick Start Guide
--8<-- "./docs/quick_start.md:6"

# Hardware Overview
--8<-- "./docs/hardware_overview.md:5"

# Hardware Assembly
--8<-- "./docs/hardware_assembly.md:5"

# Software Overview
--8<-- "./docs/software_overview.md:5"

# RTK Configurations - Base Station
--8<-- "./docs/base.md:5"

# RTK Configurations - NTRIP Server
--8<-- "./docs/ntrip_server.md:5"

# RTK Configurations - NTRIP Client
--8<-- "./docs/ntrip_client.md:5"

# RTK Correction Service
--8<-- "./docs/correction_service.md:5"

# Enable the L5 Band
--8<-- "./docs/L5.md:5"

# Mining with Onocoy
--8<-- "./docs/mining-onocoy.md:5"

# Resources
--8<-- "./docs/resources.md:5"

# Troubleshooting Tips
--8<-- "./docs/troubleshooting_tips.md:5"

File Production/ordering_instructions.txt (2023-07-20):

panel size, 166x126mm
PCB thickness, 1.6mm
number of layers, 4
controlled impedance, JLC7628
material, TG155
soldermask color, Red
silkscreen color, White
oz copper, 1oz
finish, ENIG
stencils, top
pcs per panel, 1
min trace width, 0.1524mm / 0.0060in
min drill size, 0.3000mm / 0.0118in
filename to layer stackup 1/2/3/4: GTL, GL2, GL3, GBL

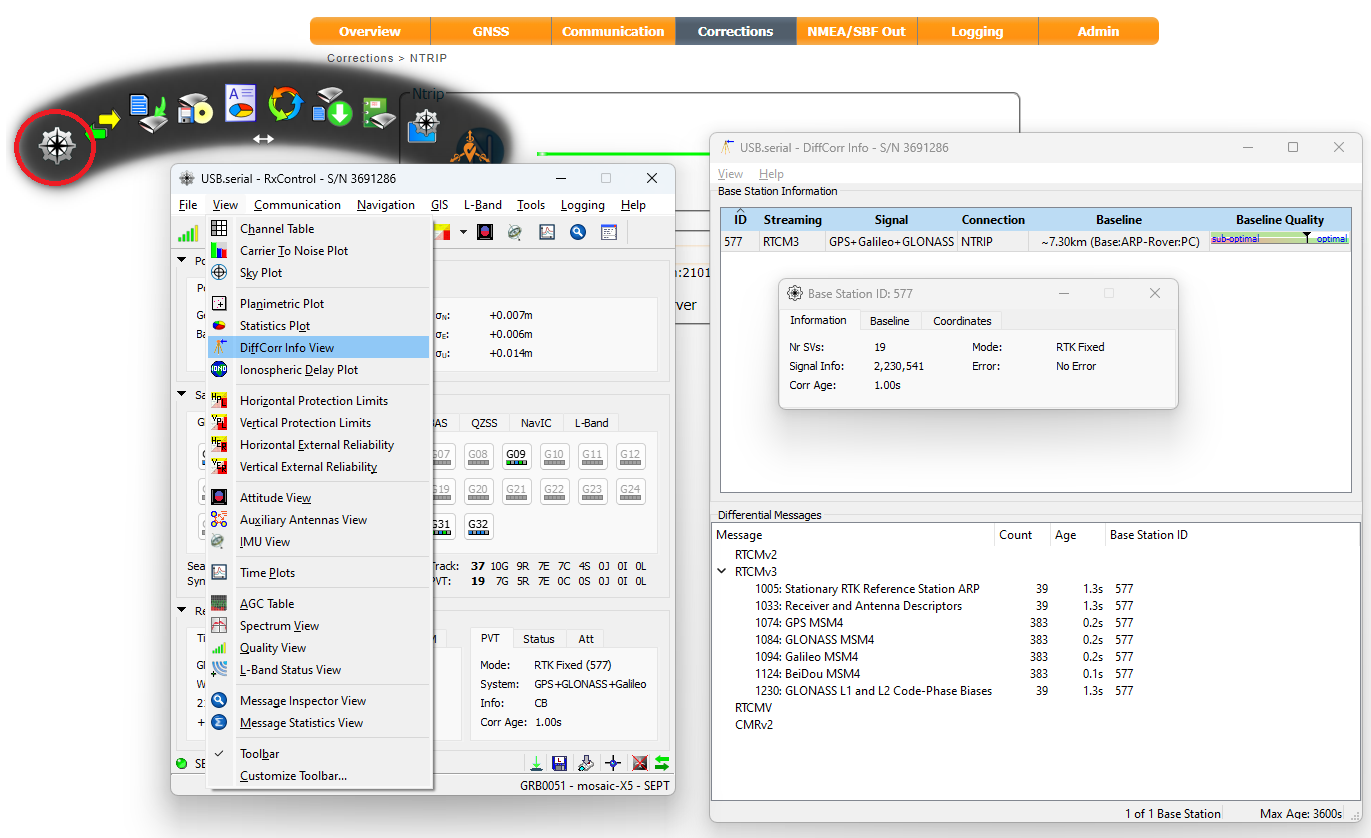
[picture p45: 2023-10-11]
docs/assets/img/hookup_guide/NTRIP_client_5.png

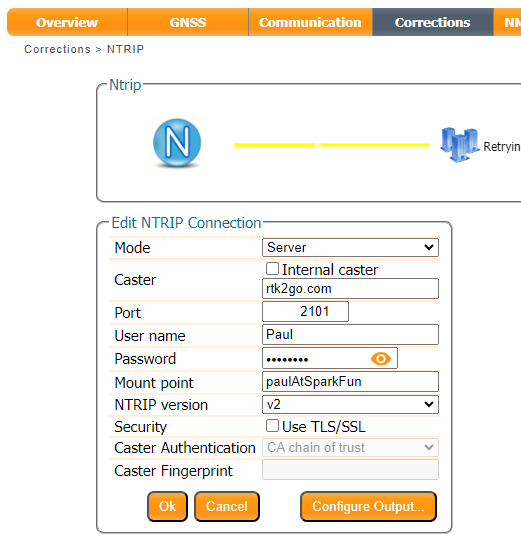
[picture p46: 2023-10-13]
docs/assets/img/hookup_guide/NTRIP_server_3.png

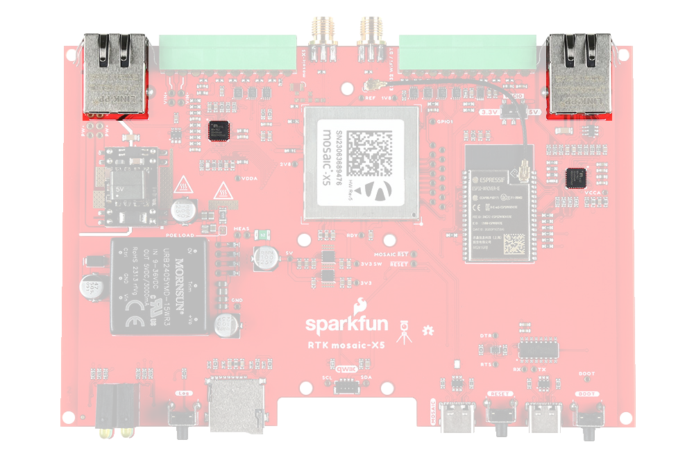
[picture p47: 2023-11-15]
docs/assets/img/hookup_guide/PHY2.png

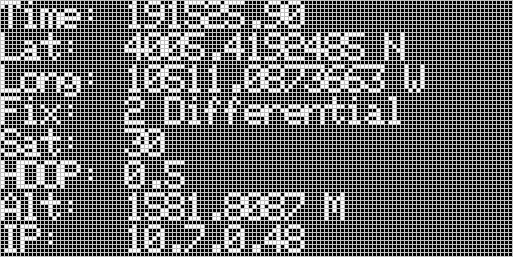
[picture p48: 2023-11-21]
docs/assets/img/hookup_guide/template_OLED-sparkfun.png

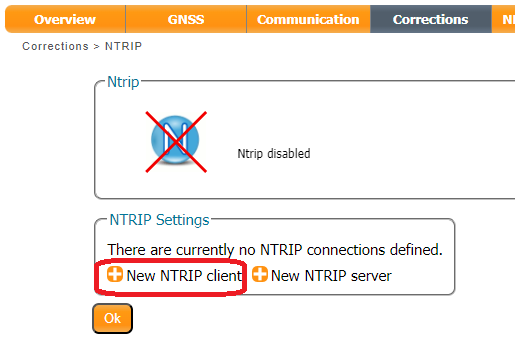
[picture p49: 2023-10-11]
docs/assets/img/hookup_guide/NTRIP_client_1.png

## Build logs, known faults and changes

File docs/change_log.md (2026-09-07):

Changes added at v1.0.6:

* ESP-IDF:
	* Bump to ESP-IDF v5.1.7
	* Add ```CONFIG_ETH_TRANSMIT_MUTEX=y```
* WiFi mode improvements:
	* Fixed an error where it was possible for the original ESP32 Ethernet MAC address to replace the desired spoofed mosaic-X5 MAC address
	* The firmware ignores the initial all-zeros MAC Address in IPStatus (or an Ethernet packet)
		* This was causing problems when starting in WiFi mode
	* The IP_EVENT_STA_GOT_IP event IP address is copied to the OLED display
		* This is received before the IPStatus update
		* This ensures the IP address is displayed even if the IPStatus is missed
	* The firmware no longer sends "seth,off" to turn Ethernet off before configuring DHCP
		* It looks like this caused more problems than it solved
	* Reduced the wait-for-IPStatus timeout from 5s to 3s
		* It is received quicker than that
* General improvements:
	* The minimal vTaskDelay has been increased from ```vTaskDelay(0)``` to ```vTaskDelay(1)```
		* This prevents unwanted Watchdog resets during wait-for-command-response

Changes added at v1.0.5:

* The firmware now supports a username and password for the X5 itself
	* This is to support mosaic-X5 firmware versions >= 4.15.1 where a username and password are mandatory *on IP interfaces* (webUI, Ethernet-over-USB, CLI over TCP/IP)
	* The username and password are *not* mandatory on COM and USB (virtual COM) ports, *unless* you set the `Default Access Level Per Interface` (`setDefaultAccessLevel` / `sdal`) to *none* for COM and/or USB ports
	* The ESP32 firmware only needs to know the username and password if the default access levels have been changed
	* For more information about the X5 Log-in procedure, please read [this Septentrio documentation](https://customersupport.septentrio.com/s/article/Cybersecurity-guidelines-Log-in-procedure)
	* If you upgrade the X5 firmware to 4.15.1:
		* Enter your user-defined username and password, using the Factory credentials *RxAdmin* and *S3pt3ntr10*, as described in the [Log-in procedure](https://customersupport.septentrio.com/s/article/Cybersecurity-guidelines-Log-in-procedure)
		* You will need to enter the user-defined username and password whenever you connect over an IP interface
		* Logging in via the ESP32 on a COM port does not remove the need to log in on IP interfaces. You still need to log in on each IP interface individually and separately
		* Upgrade the ESP32 Firmware to v1.0.5, following the procedure described below
		* If the ESP32 needs to know the username and password: in the ESP32 Serial Terminal / console, use option *set -u* to set the X5 username and option *set -x* to set the X5 password
		* Turn the RTK mosaic-X5 off and back on again

Changes added at v1.0.4:

* The firmware now includes an efficient SBF and NMEA parser
    * Previously the NMEA GPGGA and SBF IPStatus messages were polled, this resulted in the OLED being updated once every ~2 seconds
	* In v1.0.4: NMEA Stream10 carries the GPGGA message at 1Hz; SBF Stream10 carries the IPStatus message OnChange
	* The OLED is now updated on the arrival of the GPGGA message, at exactly 1Hz
* The firmware now ensures that the SBF and NMEA protocols are enabled for output on X5 COM4
    * Previously, the firmware would stall if either SBF or NMEA were disabled
* The firmware now supports the NMEA *GN* Talker ID, in addition to *GP*
    * Previously setting the Talker ID to *GN* would cause the firmware to stall
* The OLED now displays the Latitude and Longitude in *DD MM SS.SSSS* format, to match the format of the X5's internal web page
    * Previously the format was *DDMM.MMMMMM*, copied directly from the GPGGA message
* The firmware will perform a soft reset of the GNSS during startup - if needed
    * The X5 can go into a [Ready for SUF download](https://customersupport.septentrio.com/s/article/How-to-troubleshoot-receiver-reporting-Ready-for-SUF-download) state if it is reset four times with no antenna connected
	* This can be cleared with a soft reset

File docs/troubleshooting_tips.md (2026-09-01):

---
icon: sfe
---

!!! failure "Deprecated Documentation"
	As of Sept 1, 2026 this guide has been retired. Users can find our latest documentation at: [https://docs.sparkpnt.com/SXM-E](https://docs.sparkpnt.com/SXM-E)

!!! warning "Need Help?"
	If you need technical assistance or more information on a product that is not working as you expected, we recommend heading on over to the [SparkPNT Forums](https://community.sparkpnt.com).

	!!! info "Account Registration Required"
		If this is your first visit to our forum, you'll need to create a [Forum Account](https://community.sparkpnt.com/signup) to post questions.

## What is in the Box?
The RTK mosaic-X5 comes packaged as a complete kit, with all the accessories you'd need to set up an RTK base station. Inside the box, users will find the [GNSS antenna](https://www.sparkfun.com/gnss-multi-band-l1-l2-l5-surveying-antenna-tnc-spk6618h.html), RTK mosaic-X5 in its aluminum enclosure, and another box containing additional accessories. Inside, the accessory box, users will find the [CAT-6 Ethernet cable](https://www.sparkfun.com/cat-6-cable-3ft.html), [USB cable](https://www.sparkfun.com/reversible-usb-a-to-c-cable-2m.html), [SMA to TNC cable](https://www.sparkfun.com/reinforced-interface-cable-sma-male-to-tnc-male-10m.html), [USB power supply](https://www.sparkfun.com/usb-wall-charger-5v-1a-black.html), [WiFi antenna](https://www.sparkfun.com/2-4ghz-duck-antenna-rp-sma.html), and [32GB SD card](https://www.sparkfun.com/microsd-card-32gb-class-10.html).

<div class="grid" markdown>

<div markdown>

<figure markdown>
Kit contents (https://cdn.sparkfun.com/assets/parts/2/4/0/7/2/23748-RTK-Mosaic-X5-Kit-All.jpg "Click to enlarge")
<figcaption markdown>Everything that is included in the RTK mosaic-X5 kit.</figcaption>
</figure>

</div>

<div markdown>

<figure markdown>
Kit contents
<figcaption markdown>The contents of the RTK mosaic-X5 package.</figcaption>
</figure>

</div>

<div markdown>

<figure markdown>
Kit contents (https://cdn.sparkfun.com/assets/parts/2/4/0/7/2/23748-RTK-Mosaic-X5-Kit-Accessories.jpg "Click to enlarge")
<figcaption markdown>Products in the accessories box.</figcaption>
</figure>

</div>

</div>

If you are missing any of these items, please reach out to us in our forum.

<article style="text-align: center;" markdown>
[SparkPNT Forum](https://community.sparkpnt.com/){ .md-button .md-button--primary }
</article>

## WiFi Connectivity
For WiFi connectivity issues, here are some simple troubleshooting tips:

* Verify that the RTK mosaic-X5 is operating in **Mode: `2`** for WiFi functionality.
* Double-check the WiFi credentials used in the ESP32 configuration.
* Make sure that the configured WiFi network is broadcasting on a 2.4GHz band. The ESP32 cannot access the 5GHz band.
* Make sure that the Ethernet cable is not coiled around/near the WiFi antenna. This will cause data packets to be lost and the mosaic-X5 web page to hang/freeze.

## WiFi Provisioning
The ESP32 firmware we provide is only compatible with basic `SSID` and `Password` WiFi authentication. The firmware is not compatible with networks that implement other provisioning methods such as a [captive portal](https://en.wikipedia.org/wiki/Captive_portal), a QR code, or [Wi-Fi protected setup](https://en.wikipedia.org/wiki/Wi-Fi_Protected_Setup "WPS"). Our intention was that users could easily develop their, own firmware to suit their needs.

!!! tip
	Here are some resources that might be useful for getting started with other provisioning methods:

	<div class="grid" markdown>

	<div markdown>

	* [ESP-IDF: Wi-Fi Provisioning](https://docs.espressif.com/projects/esp-idf/en/latest/esp32/api-reference/provisioning/wifi_provisioning.html)
	* [ESP-IDF: Example - Wi-Fi Provisioning Manager](https://github.com/espressif/esp-idf/blob/master/examples/provisioning/wifi_prov_mgr/README.md)
	* [AutoConnect: Captive Portal](https://hieromon.github.io/AutoConnect/adcpcontrol.html)

	</div>

	<div markdown>

	:material-youtube: Video Tutorials:

	* [QR Code](https://www.youtube.com/watch?v=JYtDibqJMs0)
	* [Access Point/Web Server](https://www.youtube.com/watch?v=VnfX9YJbaU8) and [Guide](https://dronebotworkshop.com/wifimanager/)

	</div>

	</div>

## Data Logging
For data logging issues, here are some simple troubleshooting tips:

* Make sure that your SD card is formatted to a `FAT32` file system.
	* The `FAT32` file system also limits the maximum capacity of the card to less than **32GB** *(i.e. a 256GB SD card will not work)*.
* Make sure that the mosaic-X5 module has a configured data stream output.
* Use the mosaic-X5 web page to verify that the SD card is mounted as a storage drive.

## OLED Dead Pixels
Got a few dead pixels on your OLED display? Please reach out to us in our forum.

<article style="text-align: center;" markdown>
[SparkPNT Forum](https://community.sparkpnt.com/){ .md-button .md-button--primary }
</article>

## Vehicle Power - Dead Battery
Is the RTK mosaic-X5 killing your vehicle's battery?

Make sure that the external power source for the RTK mosaic-X5 is not directly tied to the vehicle's battery, `Always On`, or accessory circuits. Otherwise, users will risk killing the battery while the engine is off. We recommend locating the *ignition on* or *switched power* circuit, which is only powered when the key is in the `On` position *and the engine is running*.

!!! note
	The `On` position, is where a key normally rests after the engine is started. However, users can still move the key from the `Off` position and into the `On` position without starting the engine. In this case, the alternator is not running and keeping the battery charged.

	Modern *eco-efficient* vehicles may automatically shut down the engine if the vehicle is idling too long. Therefore, cutting off the vehicle's alternator that keeps the battery charged. Luckily, most vehicles with this *automatic start/stop* technology will monitor the battery's voltage and restart the engine when required. With this in mind, users may want to initially monitor their battery voltage, in case their vehicle isn't *"so smart"* :sweat_smile:.

## L5 Band
By default, the L5 band is disabled on the mosaic-X5. To enable reception of the L5 band on the mosaic-X5, we have provided instructions on the [Enable the L5 Band](../L5) page.

## Expected Accuracy
Here is a reference of the accuracy that can be expected from the RTK mosaic-X5 at a stationary position in `Rover` mode.

=== "Factory Settings"
	With the factory settings for the mosaic-X5, our location had a standard deviation of &sigma;~x~ = 0.499m and &sigma;~y~ = 0.595m

	<div class="grid" markdown>

	<div markdown>

	<figure markdown>
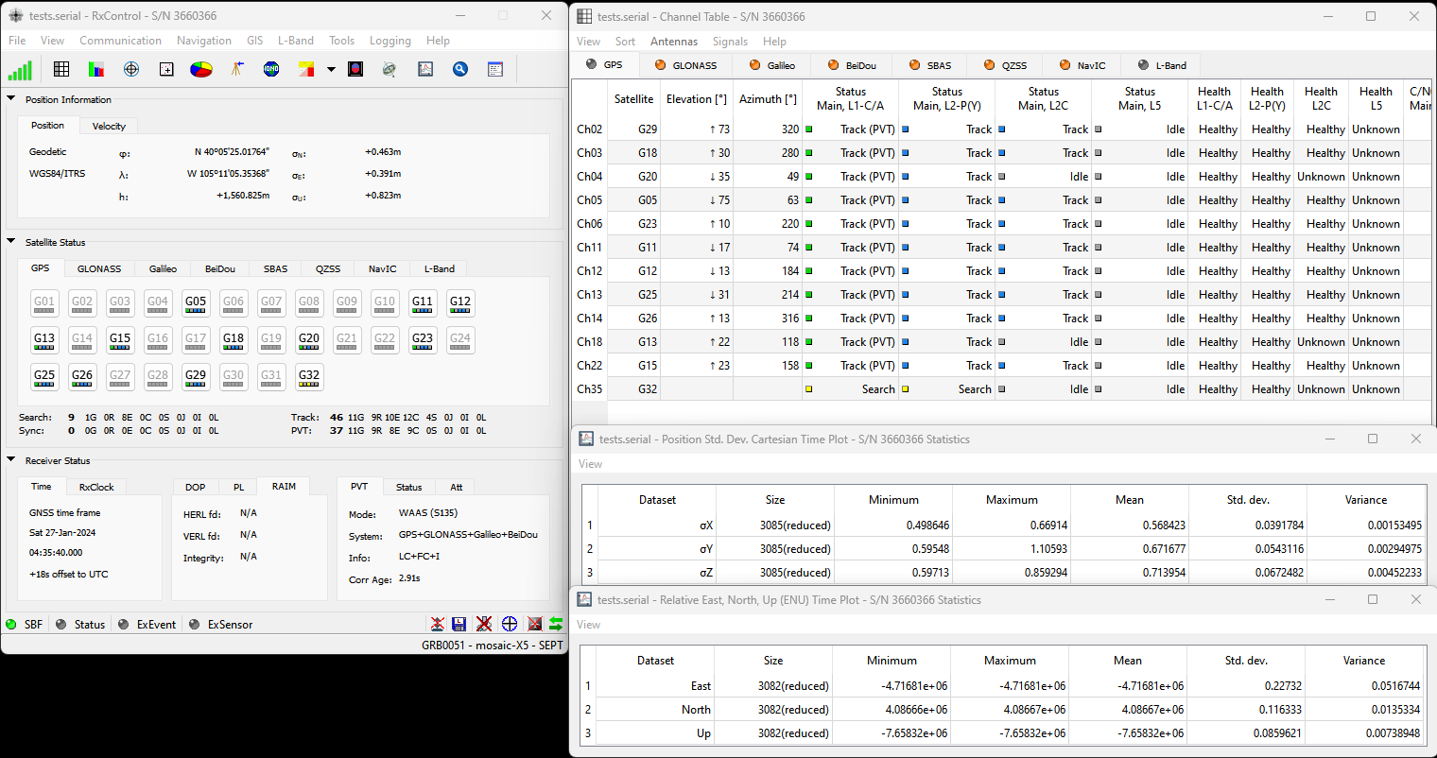
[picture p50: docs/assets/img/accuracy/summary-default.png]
	
	<figcaption markdown>A summary of the GPS signals and the standard deviation of the antenna's location.</figcaption>
	</figure>

	</div>

	<div markdown>

	<figure markdown>
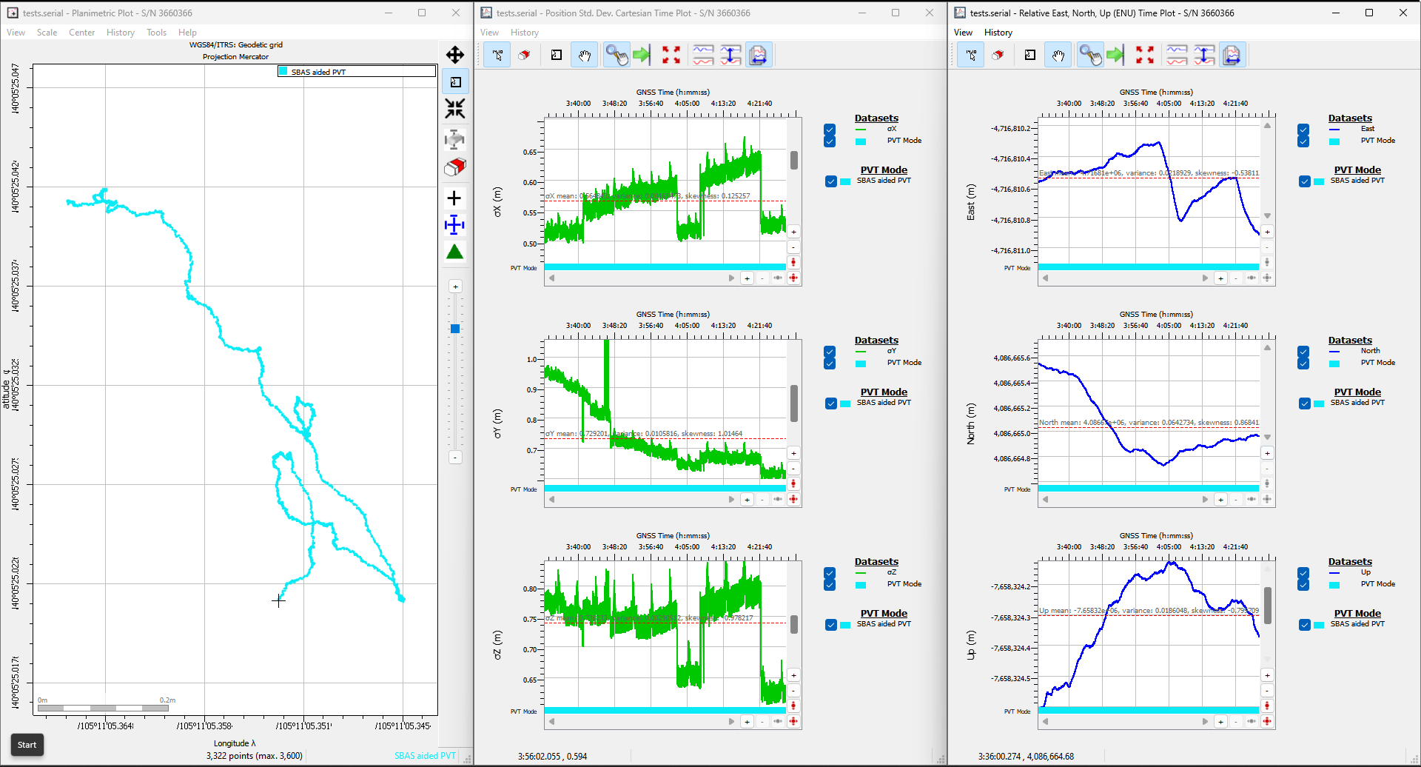
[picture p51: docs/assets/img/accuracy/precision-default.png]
	
	<figcaption markdown>Data recorded from the RTK mosaic-X5 with the default/factory settings.</figcaption>
	</figure>

	</div>

	</div>

	**Conditions:** L1/L2/L5 band antenna, statically mounted to the rooftop of our building, featuring a significant ground plane, with no obstructions for multi-path signals. The RTK mosaic-X5 was connected with a low-loss cable, fully powered at 5V, and default settings.

=== "L5 Band Enabled"
	With the default settings and the `L5` band enabled for the mosaic-X5, our location had a standard deviation of &sigma;~x~ = 0.504m and &sigma;~y~ = 0.673m

	<div class="grid" markdown>

	<div markdown>

	<figure markdown>
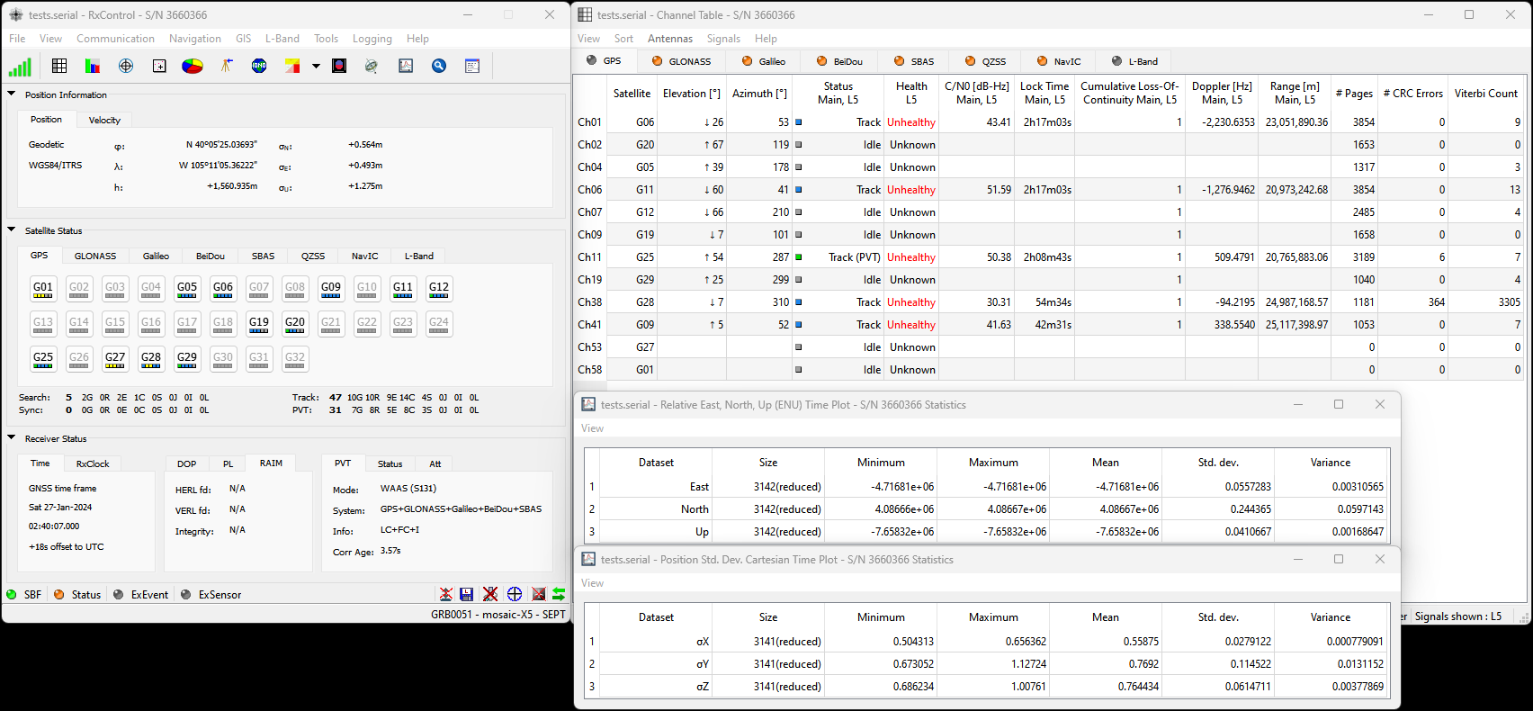
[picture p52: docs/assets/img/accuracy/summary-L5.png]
	
	<figcaption markdown>A summary of the GPS signals and the standard deviation of the antenna's location.</figcaption>
	</figure>

	</div>

	<div markdown>

	<figure markdown>
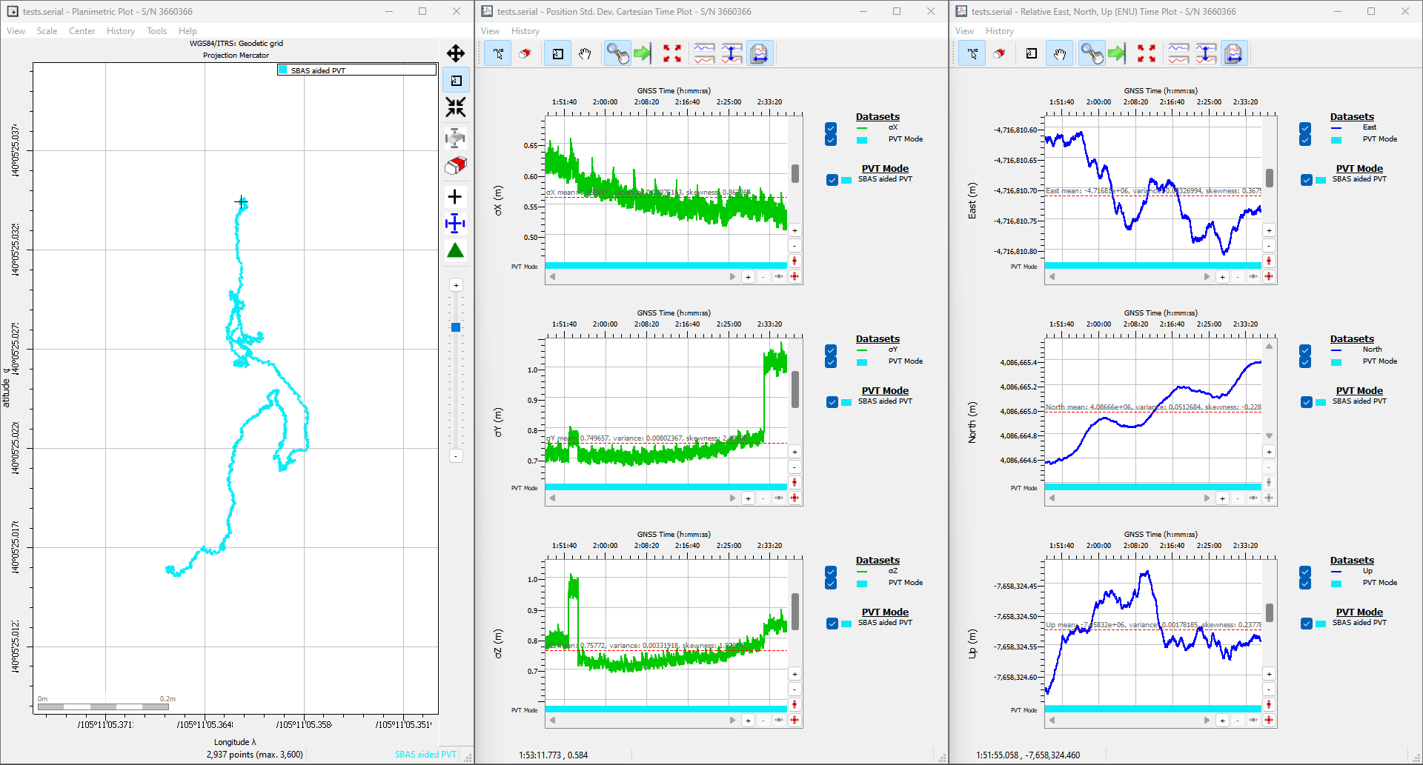
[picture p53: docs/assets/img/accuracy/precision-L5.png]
	
	<figcaption markdown>Data recorded from the RTK mosaic-X5 with the L5 band enabled.</figcaption>
	</figure>

	</div>

	</div>

	**Conditions:** L1/L2/L5 band antenna, statically mounted to the rooftop of our building, featuring a significant ground plane, with no obstructions for multi-path signals. The RTK mosaic-X5 was connected with a low-loss cable, fully powered at 5V, and had the `L5` band enabled.

=== "NTRIP - RTK Corrections"
	With the default setting and RTK corrections enabled for the mosaic-X5, our location had a standard deviation of &sigma;~x~ = 4.29mm and &sigma;~y~ = 6.65mm

	<div class="grid" markdown>

	<div markdown>

	<figure markdown>
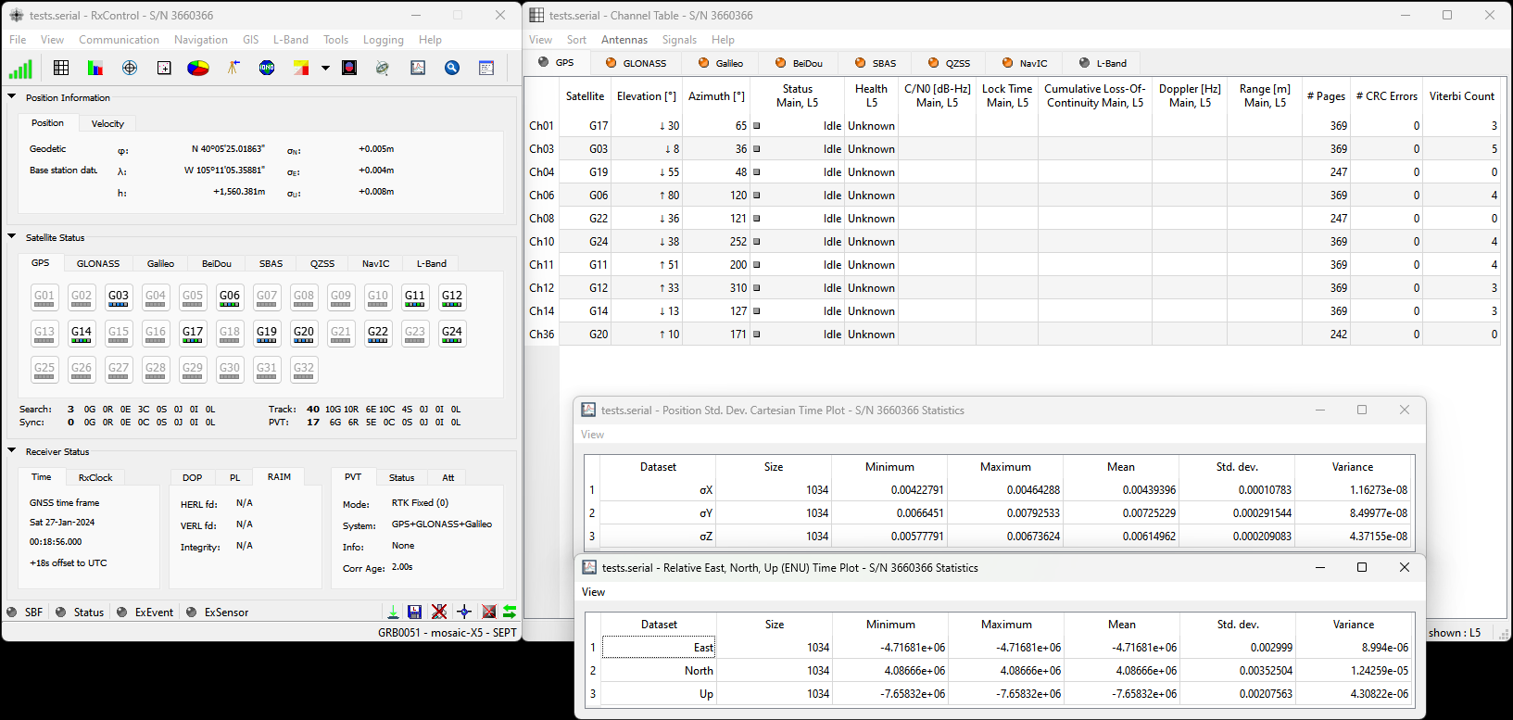
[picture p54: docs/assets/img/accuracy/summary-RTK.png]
	
	<figcaption markdown>A summary of the GPS signals and the standard deviation of the antenna's location.</figcaption>
	</figure>

	</div>

	<div markdown>

	<figure markdown>
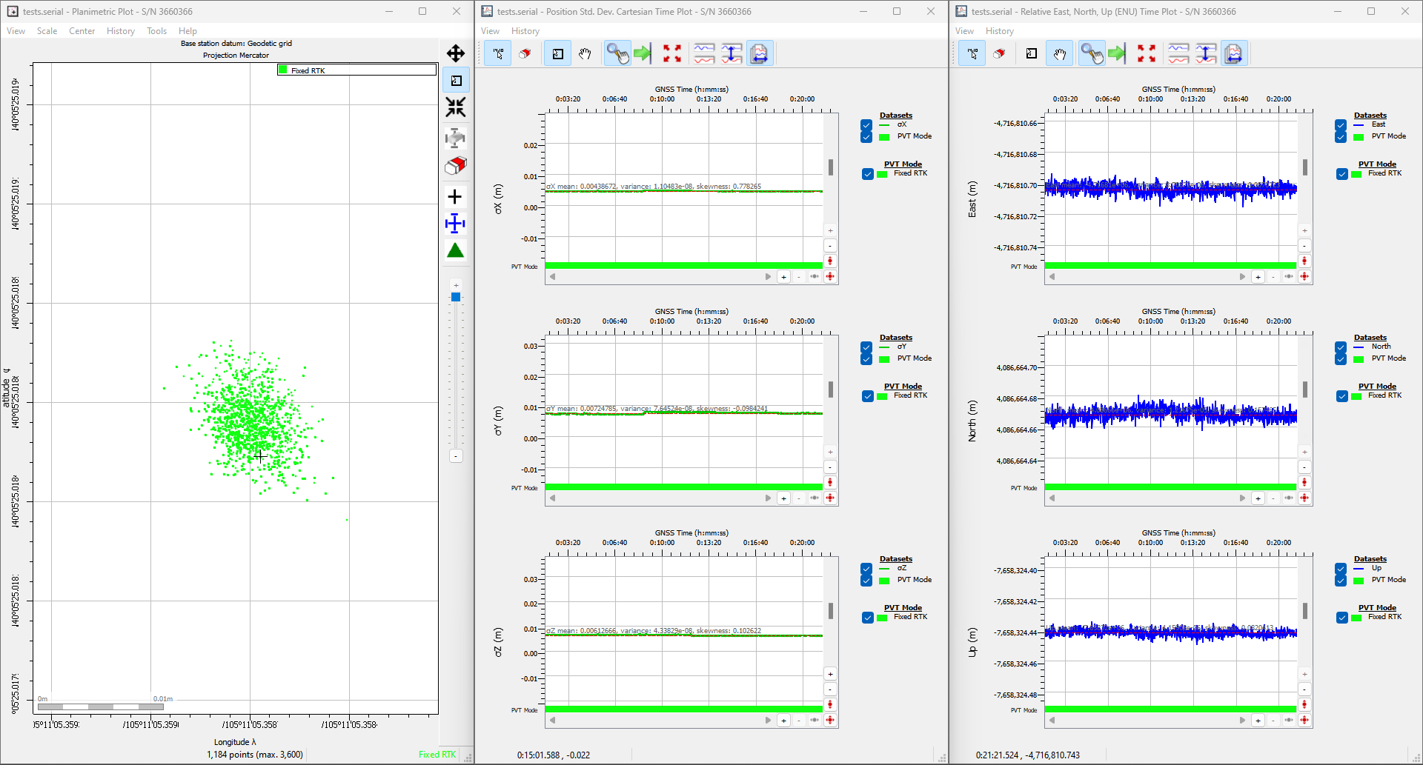
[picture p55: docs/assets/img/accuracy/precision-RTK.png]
	
	<figcaption markdown>Data recorded from the RTK mosaic-X5 with the RTK corrections.</figcaption>
	</figure>

	</div>

	</div>

	**Conditions:** L1/L2/L5 band antenna, statically mounted to the rooftop of our building, featuring a significant ground plane, with no obstructions for multi-path signals. The RTK mosaic-X5 was connected with a low-loss cable, fully powered at 5V, and configured as an NTRIP client with corrections from [RTK2go](http://www.rtk2go.com:2101/SNIP::STATUS).

=== "Ideal *(RTK & L5 Band)*"
	Under *"ideal conditions"*, our location had a standard deviation of &sigma;~x~ = 4.68mm and &sigma;~y~ = 6.70mm

	<div class="grid" markdown>

	<div markdown>

	<figure markdown>
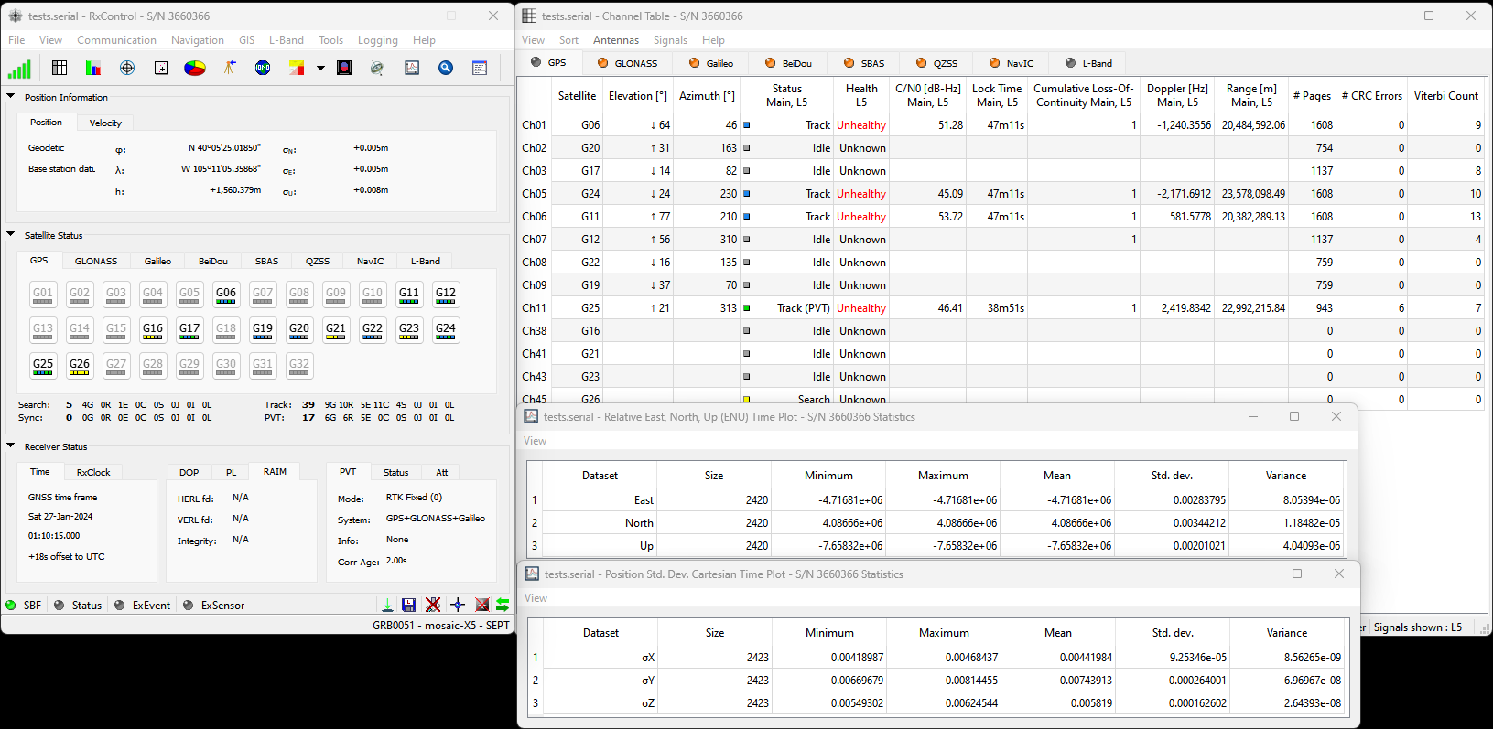
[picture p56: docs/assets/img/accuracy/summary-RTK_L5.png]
	
	<figcaption markdown>A summary of the GPS signals and the standard deviation of the antenna's location.</figcaption>
	</figure>

	</div>

	<div markdown>

	<figure markdown>
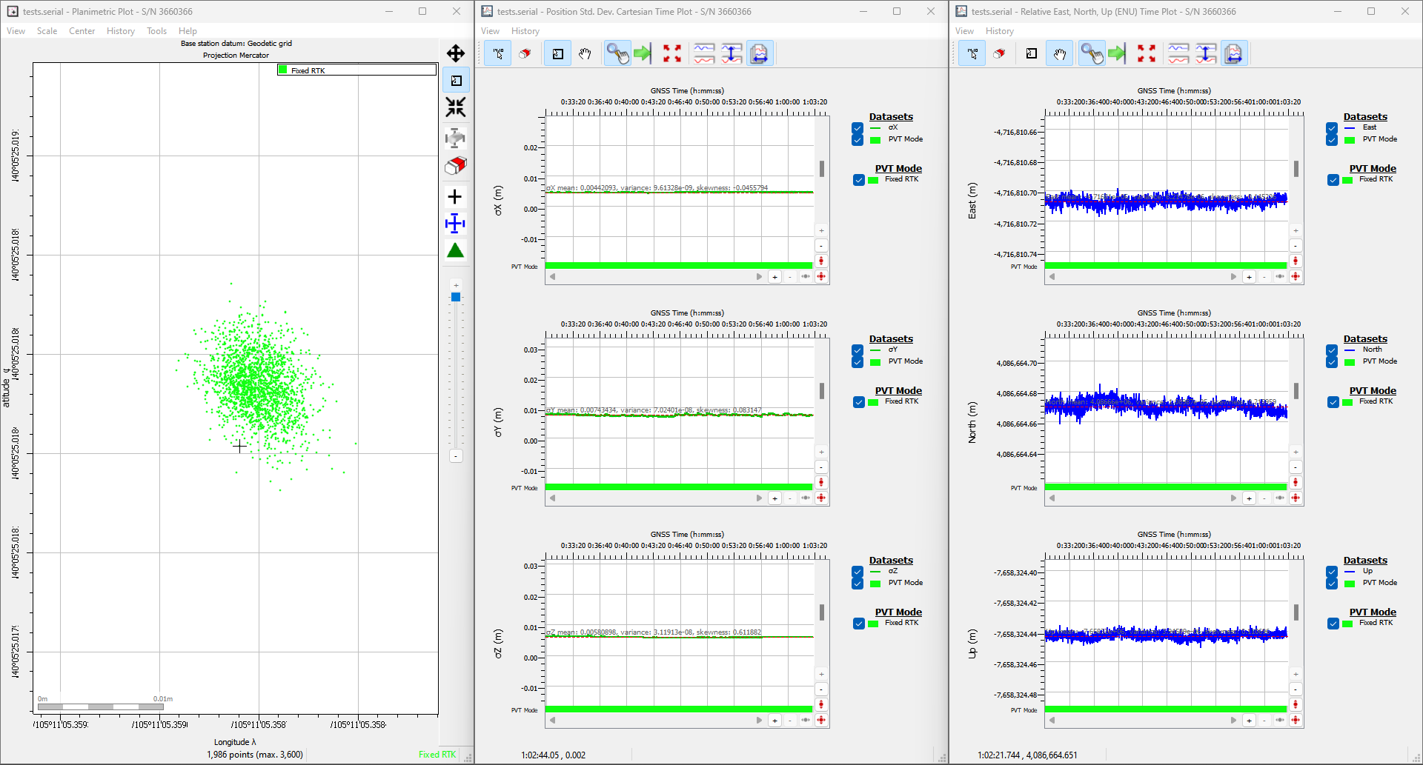
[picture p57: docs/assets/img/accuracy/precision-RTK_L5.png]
	
	<figcaption markdown>Data recorded from the RTK mosaic-X5 with the RTK corrections and the `L5` band enabled.</figcaption>
	</figure>

	</div>

	</div>

	**Ideal:** L1/L2/L5 band antenna, statically mounted to the rooftop of our building, featuring a significant ground plane, with no obstructions for multi-path signals. The RTK mosaic-X5 was connected with a low-loss cable, fully powered at 5V, RTK corrections enabled, and configured to enable the `L5` band.

## Reprogramming the ESP32
In case users accidentally reprogram or corrupt the flash memory on the ESP32, the [factory firmware is available in our GitHub repository](https://github.com/sparkfun/SparkFun_RTK_mosaic-X5/tree/main/Firmware/RTK_mosaic-X5_Firmware).

The batch files in the linked directory are used to flash our factory firmware onto the ESP32 in the RTK mosaic-X5. The batch file relies on the tools from the Arduino IDE and the ESP32 Arduino core and therefore, they will need to be installed before the batch file can be executed.

!!! note
	The batch file is only compatible with Windows computers. For Linux and MacOS, users will need to manually flash the [binary files](https://github.com/sparkfun/SparkFun_RTK_mosaic-X5/tree/main/Firmware/RTK_mosaic-X5_Firmware/build) onto the ESP32.

!!! note
	To compile the firmware, users will need to install the [ESP-IDF](https://idf.espressif.com/), Espressif's development framework for the ESP32. However, the compilation instructions are outside the scope of our support for this product. However, users can refer to the programming guide for the ESP-IDF to figure out how to compile the firmware.

## Enclosure Disassembly
Due to the ESD sensitivity of the mosaic-X5 module, we don't recommend disassembling the RTK mosaic-X5. However, if users must access the PCB to troubleshoot an issue, make a modification, or repair a component, we highly recommend that they take the necessary ESD precautions to avoid damaging the mosaic-X5 module.

!!! warning "Read Before Disassembly!"
	!!! danger "ESD Sensitivity"
		The mosaic-X5 module is sensitive to [ESD](https://en.wikipedia.org/wiki/Electrostatic_discharge "Electrostatic Discharge"). Use a proper grounding system to make sure that the working surface and the components are at the same electric potential.

	??? info "ESD Precaution"
		As recommended by the manufacturer, we highly encourage users to take the necessary precautions to avoid damaging their module.

		- The RTK mosaic-X5 features ESD protection on the USB-C connectors and ethernet jacks.
		- The mosaic-X5 module features internal ESD protection to the `ANT_1` antenna input.

		<div class="grid cards" markdown>

		<div markdown>

		<article style="text-align: center;" markdown>
		<article class="video-500px">
		<iframe src="https://www.youtube.com/embed/hrL5J6Q5gX8?si=jOPBat8rzMnL7Uz4&amp;start=26;&amp;end=35;" title="Septentrio: Getting Started Video (playback starts at ESD warning)" frameborder="0" allow="accelerometer; autoplay; clipboard-write; encrypted-media; gyroscope; picture-in-picture" allowfullscreen></iframe>
		</article>
		</article>

		</div>

		-   <a href="https://www.sparkfun.com/ifixit-anti-static-wrist-strap.html">
			<figure markdown>
			Product Thumbnail
			</figure>		

			---

			**iFixit Anti-Static Wrist Strap**<br>
			TOL-25572</a>

		</div>

Before disassembling the enclosure, users should disconnect the power and all cables from the RTK mosaic-X5. This will prevent users from creating any shorts and will facilitate the teardown process further on.

The RTK mosaic-X5 PCB is held in place by the front and rear panels of the enclosure. While users can remove the panels first, we recommend that users disconnect the screw terminal blocks first. Users may find it more difficult to separate the terminal block from the connector later in the disassembly process.

!!! tip "Remove the Screw Terminal Block First"
	Users may find it easiest to remove the screw terminal blocks first; as opposed to later in the teardown process.

	<figure markdown>
	Prying the Terminal Block
	<figcaption markdown>Using a soft/rigid object to carefully pry the terminal block off.</figcaption>
	</figure>

	Users can wiggle or use a soft/rigid object to carefully pry the terminal block off. In the picture above, a plastic name tag (~1.5mm thick) is used to carefully pry the terminal block up. We have also found the edge of a [PCB ruler](https://www.sparkfun.com/sparkfun-pcb-ruler-12-inch.html) works great too.

Once the terminal blocks have been removed, users can remove the front and rear panels of the enclosure. They are held in place with four, M3, Phillips head screws on the corners of each panel.

!!! tip
	We recommend removing the front panel first to prevent the Qwiic cable from being yanked off the OLED display or main PCB. Once the front panel is free, carefully lift the panel and disconnect the Qwiic cable from the top connector on the OLED display.

At this point, if users have previously disconnected all the cables and the terminal blocks from the back, the RTK mosaic-X5 PCB should slide out of the enclosure. Users can then, remove the rear panel from the enclosure to complete the teardown process.

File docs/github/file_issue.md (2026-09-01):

# Did we make a mistake?

Spot something wrong? Please let us know. 

<!-- Technical Assistance Box -->
!!! warning "Need Help?"
	If you need technical assistance or more information on a product that is not working as you expected, we recommend heading on over to the [SparkPNT Forums](https://community.sparkpnt.com).

	!!! info "Account Registration Required"
		If this is your first visit to our forum, you'll need to create a [Forum Account](https://community.sparkpnt.com/signup) to post questions.

## Discrepancies in the Documentation

All of our documentation can be modified by you! Please help us make it better.

* The documentation files for these pages are contained in the [`docs` folder](https://github.com/sparkfun/SparkFun_RTK_mosaic-X5/tree/main/docs) of the [SparkFun RTK mosaic-X5 repository](https://github.com/sparkfun/SparkFun_RTK_mosaic-X5).

### 🔍 Spot something wrong?

If a section of the documentation is incorrect, please [open an issue](https://github.com/sparkfun/SparkFun_RTK_mosaic-X5/issues) and let us know.

### Do you have a suggested correction?

1. With a GitHub account, [fork this repository](https://github.com/sparkfun/SparkFun_RTK_mosaic-X5/fork).
2. Add your correction(s) or improvement(s) to the markdown file(s)
3. File a pull request with your changes, and enjoy making the ~~words~~ ~~worlds~~ world a better place.
	* Once received, the documentation specialist will automatically be notified.
	* We will review your suggested improvement(s) to make sure they are correct and fit within our documentation standards.

## Problems in the Hardware Design

All of our designs are open-source! Please help us make it better.

* Our board design files are contained in the [`Hardware` folder](https://github.com/sparkfun/SparkFun_RTK_mosaic-X5/tree/main/Hardware) of the [SparkFun RTK mosaic-X5 repository](https://github.com/sparkfun/SparkFun_RTK_mosaic-X5).

### Does something not make sense? 🤔

If part of the design is confusing, please [open an issue](https://github.com/sparkfun/SparkFun_RTK_mosaic-X5/issues) and let us know.

### Did we forget to include an important function of the board? 🤦

If part of the board's functionality is missing, please [open an issue](https://github.com/sparkfun/SparkFun_RTK_mosaic-X5/issues) and file a feature request.

!!! tip "Design Considerations"
	Please keep in mind that we may intentionally exclude certain functions of the board to meet our product design requirements.

	* *For example, our Qwiic Micro boards are intended to fit on a small board layout and only use I^2^C communication; therefore, we may not have the SPI and interrupt pins available for users.*

### Do you wish to contribute directly to improving the board design?

1. With a GitHub account, [fork this repository](https://github.com/sparkfun/SparkFun_RTK_mosaic-X5/fork).
2. Add your design augmentation(s)
3. File a pull request with your changes, and enjoy making the ~~words~~ ~~worlds~~ world a better place.
	1. Once received, the engineer in charge of the original design will automatically be notified.
	2. We will review your suggested improvement(s) to verify that they are within our board design standards and meet our product design requirements.
	3. If approved, we will flag these changes for our next board revision. Congrats! 🍻

		!!! info
			Even if your suggestion is accepted, these changes may not be immediately available for purchase. We may have to cycle through our current product inventory first.

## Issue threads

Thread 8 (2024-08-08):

Measuring Antenna Voltage and Current Draw

PaulZC, 2024-08-08:
The mosaic-X5 itself provides the power for an active GNSS antenna. It is also capable of measuring the antenna voltage and current draw, which can be very useful when investigating antenna issues and cable faults.

Start by selecting the _**Admin \ About**_ tab on the X5's web page:

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

Select _**Diagnostic Report**_:

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

Scroll down to the _**advFEInfo**_ section. _**Ant#0**_ contains the antenna voltage and current draw:

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

For the RTK mosaic-X5, the voltage should be approximately 4.6V - 4.7V (5.0V minus the diode voltage drop).
30mA - 40mA is typical for a tri-band active antenna.

If the antenna is disconnected, or the cable is open circuit, the current draw will drop to 0.0mA. The voltage remains the same.

If the antenna cable is shorted, the X5 goes into current-limit, detects the fault and disables the power output. It then goes into a loop where it turns the power on momentarily, checks for current-limit and turns the power off again if the short is still present. When the short is removed, the power stays on. While the cable is shorted, the advFEInfo Ant#0 current draw reads as 0.0mA - same as for open circuit. So, it is not possible to tell the difference between short and open cable faults with Ant#0, but at least you can tell that a fault is present.

Closed 2024-08-08.

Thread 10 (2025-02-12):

X5 firmware upgrade fails over WiFi

PaulZC, 2025-02-12:
As reported on the SparkFun Forum by TLFLOW, updating the firmware over WiFi fails:

https://community.sparkfun.com/t/mosaic-x5-update-not-working-over-wifi/63337

PaulZC, 2025-02-12:
It looks like I have fixed this with v1.0.4 of the ESP32 firmware:

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

PaulZC, 2025-02-12:
**To replicate:**

Starting with version 1.0.3 of the ESP32 firmware (we have been shipping units with 1.0.3 for about a year now).

Connect a BT/WiFi antenna to the RP ESP32 SMA connector.
Link the two Ethernet ports with a short Ethernet cable. Use a shielded cable if possible. Keep it clear of the BT/WiFi antenna.
Power on the unit.
Connect a serial console to CONFIG ESP32 at 115200 baud.
Use ```show``` to show the current configuration.
Set the firmware into mode 2 with ```set -m 2```
Set the WiFi SSID and password with ```set -s SSID``` and ```set -p PASSWORD```
Restart the firmware in mode 2 with ```restart```
Wait for the X5 to connect to WiFi and the IP address to be shown.
Open a web browser and navigate to the IP address shown on the OLED display.
On the X5 web page, open the Admin \ Upgrade tab.

The console shows the error:

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

Use ```Choose file``` to select the latest firmware .suf file on your machine.
Hit ```Start upgrade```

The SUF file starts to upload.
Many many ```emac_esp32: emac_esp32_transmit(262): insufficient TX buffer size``` errors are shown.

Eventually the full SUF file is uploaded and the X5 firmware restart. This causes Ethernet to go down and the ESP32 also restarts:

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

But the firmware upgrade does succeed. Here I am downgrading from 4.14.10.1 to 4.14.0:

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

But, this is the second time I have tried. I'm pretty sure that the first time I tried, the X5 hung while downloading the SUF file...

PaulZC, 2025-02-12:
I try again - upgrading from 4.14.0 to 4.14.10.1:

The SUF upload takes a while

Then the web page hangs here:

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

That's probably expected because the ESP32 is also restarting and the Ethernet and WiFi connections both need to be reestablished.

If I wait a little longer, I see:

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

So, I retract my earlier comment. Upgrade over WiFi does seem to be working for me - with version 1.0.3 of the ESP32 firmware... Maybe I just wasn't patient enough the first time?

PaulZC, 2025-02-12:
Can we get rid of those nasty ```esp.emac: emac_esp32_transmit(232): insufficient TX buffer size``` errors?

Searching for possible solutions:

https://github.com/espressif/esp-idf/issues/14261

This one is also relevant:

https://github.com/espressif/esp-idf/issues/10851

What happens if I increase the number of TX buffers in the IDF?

With IDF v5.1.1, I try increasing the number of TX buffers and decreasing the DMA buffer size:

```
CONFIG_ETH_DMA_TX_BUFFER_NUM=20
CONFIG_ETH_DMA_BUFFER_SIZE=256
```

Nope. Still MANY ```insufficient TX buffer size``` errors. But, again, if I'm patient, the upgrade does succeed.

Trying:

```
CONFIG_ETH_DMA_TX_BUFFER_NUM=20
CONFIG_ETH_DMA_BUFFER_SIZE=1024
```

Nope. That gets me a stack overflow. And I have to power cycle the unit to recover...

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

Trying:

```
CONFIG_ETH_DMA_TX_BUFFER_NUM=20
CONFIG_ETH_DMA_RX_BUFFER_NUM=20
CONFIG_ETH_DMA_BUFFER_SIZE=512
```

Nope. Still many errors. But, again, the upgrade is successful. I just need to wait until the web page reconnects.

I'm going to give up on this for now. I will try and resolve those errors when time permits, but it's not a high priority as the upgrade is working.

PaulZC, 2025-02-13:
Update:

For the above tests, my computer was connected to the router via Ethernet. Only the mosaic-X5 was connected via WiFi (via the ESP32).

I tried another test with my computer connected via WiFi, and this failed:

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

Actually, I tried this twice. The first time it worked. The above failures were on the second try.

It looks like the ESP32 firmware is crashing or hanging?

OK. I will investigate further and try and correct this - as soon as time permits.

PaulZC, 2025-02-13:
Third attempt gets me a stack overflow:

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

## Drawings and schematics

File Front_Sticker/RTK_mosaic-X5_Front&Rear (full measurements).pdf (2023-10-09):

## RTK MOSAIC - X5

## FRONT

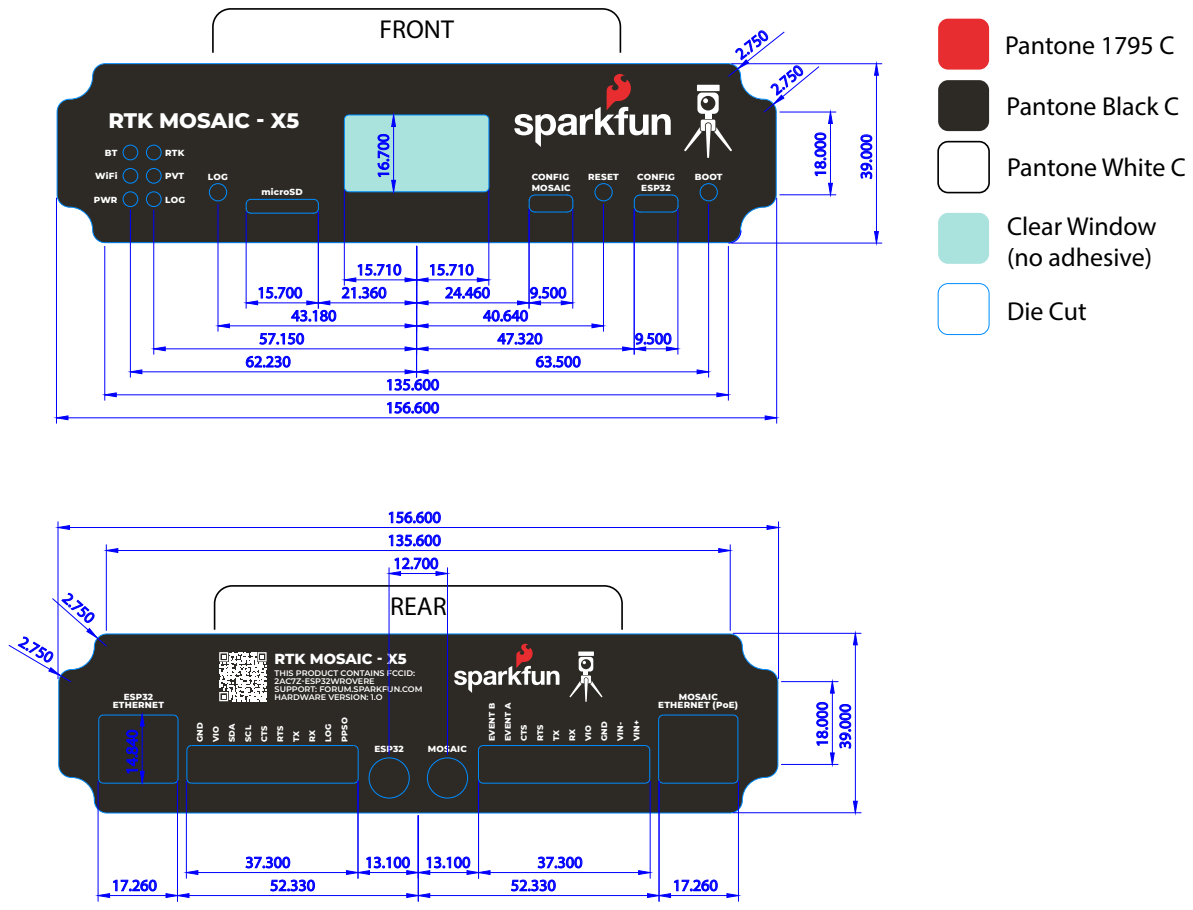
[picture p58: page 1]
WiFi; PWR; RTK; PVT; LOG; microSD; CONFIG MOSAIC; RESET; BOOT; GND; VIO; SDA; SCL; CTS; RTS; PPSO; EVENT B; EVENT A; VIN-; VIN+; ESP32; MOSAIC; REAR; Pantone 1795 C; Pantone Black C; Pantone White C; Clear Window (no adhesive); Die Cut; CONFIG ESP32

RTK MOSAIC - X5
THIS PRODUCT CONTAINS FCCID:
2AC7Z-ESP32WROVERE
SUPPORT: FORUM.SPARKFUN.COM
HARDWARE VERSION: 1.O

MOSAIC ETHERNET (PoE) ESP32 ETHERNET

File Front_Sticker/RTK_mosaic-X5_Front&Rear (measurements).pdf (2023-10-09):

# RTK MOSAIC - X5

# FRONT

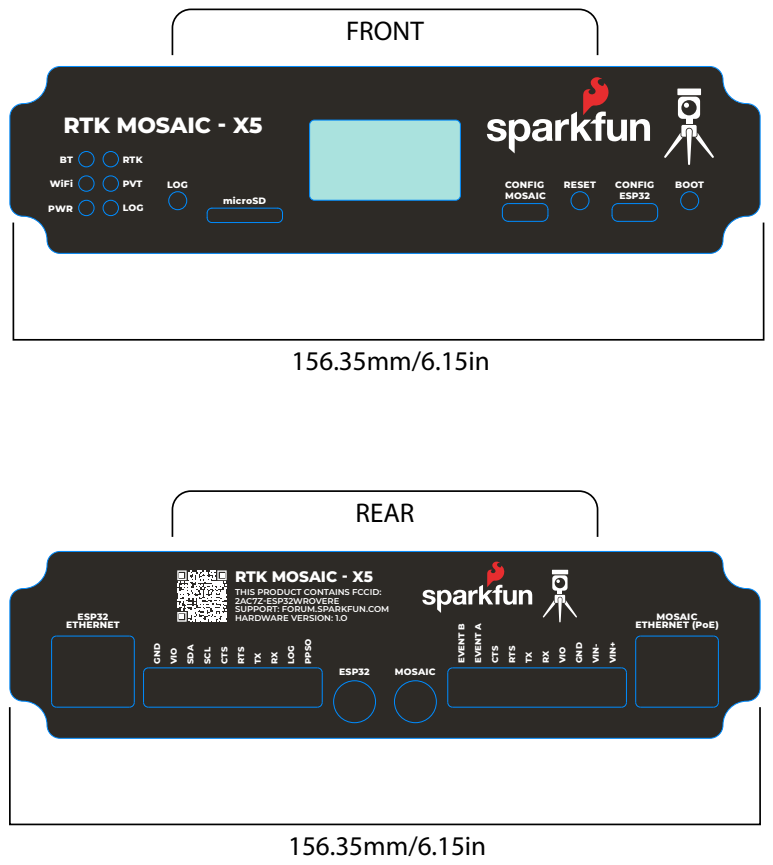
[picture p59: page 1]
WiFi; PWR; RTK; PVT; LOG; microSD; CONFIG MOSAIC; RESET; CONFIG; ESP32; BOOT; GND; VIO; SDA; SCL; CTS; RTS; PPSO; EVENT B; EVENT A; VIN-; VIN+; MOSAIC; REAR

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

MOSAIC ETHERNET (PoE) ESP32 ETHERNET

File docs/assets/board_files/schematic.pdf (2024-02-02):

# IOA27 12 SCK2/IOA14 13 POCI2/IOA12 14 PICO2/IOA13 16 PICO3/IO23 37 SCL/IO22 36

# TX-IO1 35 RX-IO3 34 SDA/IO21 33 POCI3/IO19 31 SCK3/IO18 30 CS3/IO5 29

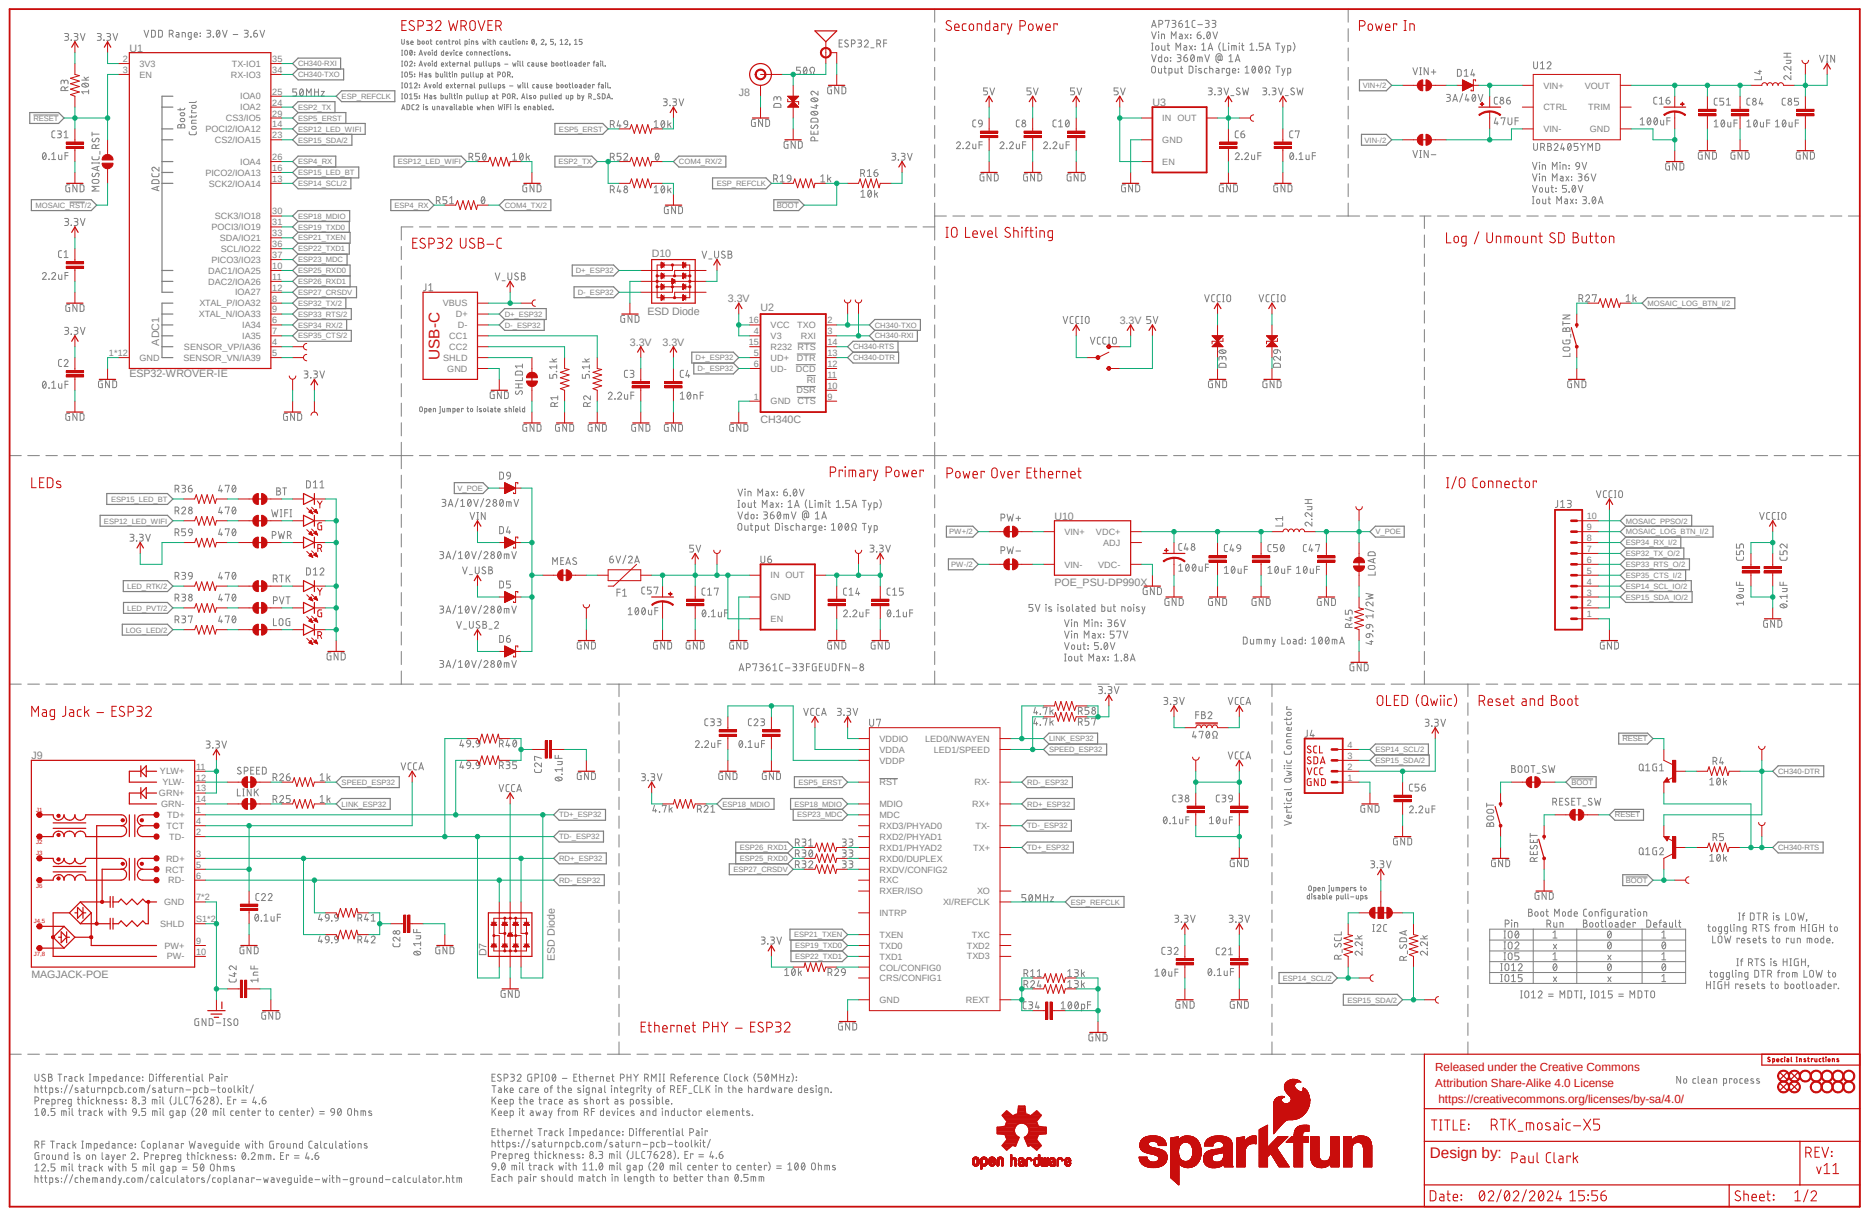
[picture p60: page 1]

VDC- VDC+ ADJ VIN- VIN+ U10 D⁷

LED0/NWAYEN
LED1/SPEED

TD+ 1 TCT 4 TD- 2 RD+ 3 RCT 5 RD- 6 GND 7*2 SHLD S1*2 PW+ 9 PW- 10 YLW+ 11 YLW- 12 GRN+ 13 GRN- 14

Released under the Creative Commons
Attribution Share-Alike 4.0 License
https://creativecommons.org/licenses/by-sa/4.0/

U8

# 2B 6 GND 4 DIR 5

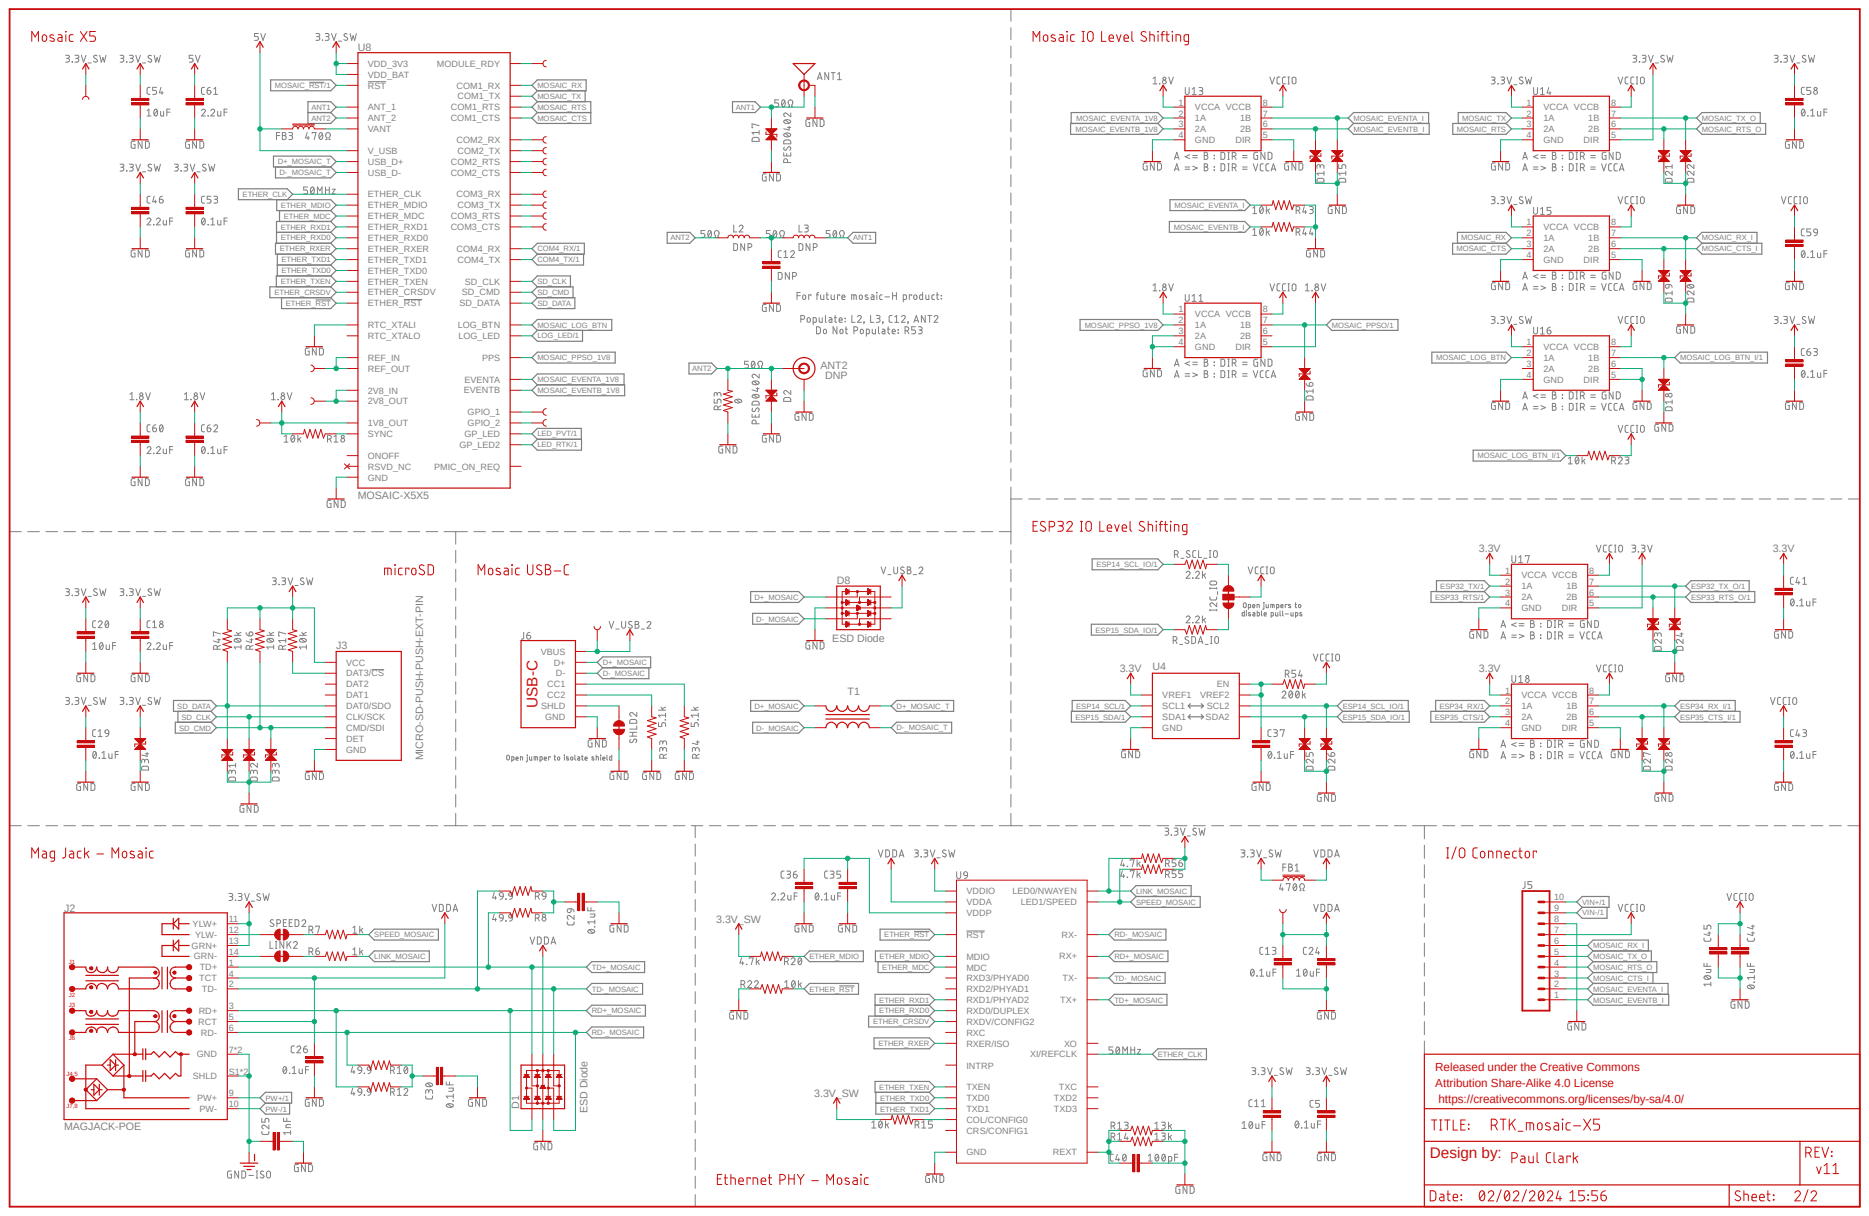
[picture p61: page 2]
MAGJACK-POE; ESD Diode; MOSAIC-X5X5; DNP; GND; VDDIO VDDA VDDP GND; RXER/ISO; INTRP; TXEN TXD0 TXD1 COL/CONFIG0 CRS/CONFIG1; LED0/NWAYEN LED1/SPEED; XI/REFCLK; TXC TXD2 TXD3 REXT; VDD_3V3 VDD_BAT; V_USB; USB_D-; USB_D+; COM1_RX COM1_TX COM1_RTS COM1_CTS; COM2_RX COM2_TX COM2_RTS COM2_CTS; COM3_RX COM3_TX COM3_RTS COM3_CTS; COM4_RX COM4_TX; ETHER_CLK ETHER_MDIO ETHER_MDC ETHER_RXD1 ETHER_RXD0 ETHER_RXER ETHER_TXD1 ETHER_TXD0 ETHER_TXEN ETHER_CRSDV ETHER_RST; SD_CLK SD_CMD SD_DATA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

3.3V DAT3/CS CMD/SDI DAT0/SDO

MICRO-SD-PUSH-PUSH-EXT-PIN ESD Diode
DAT2 DAT1 CLK/SCK DET VCC

VBUS CC1 D+D- CC2 SHLD
Design by: USB⁻C

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

RST MDIO MDC

RXD3/PHYAD0 RXD2/PHYAD1 RXD1/PHYAD2 RXD0/DUPLEX RXDV/CONFIG2 RXC

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

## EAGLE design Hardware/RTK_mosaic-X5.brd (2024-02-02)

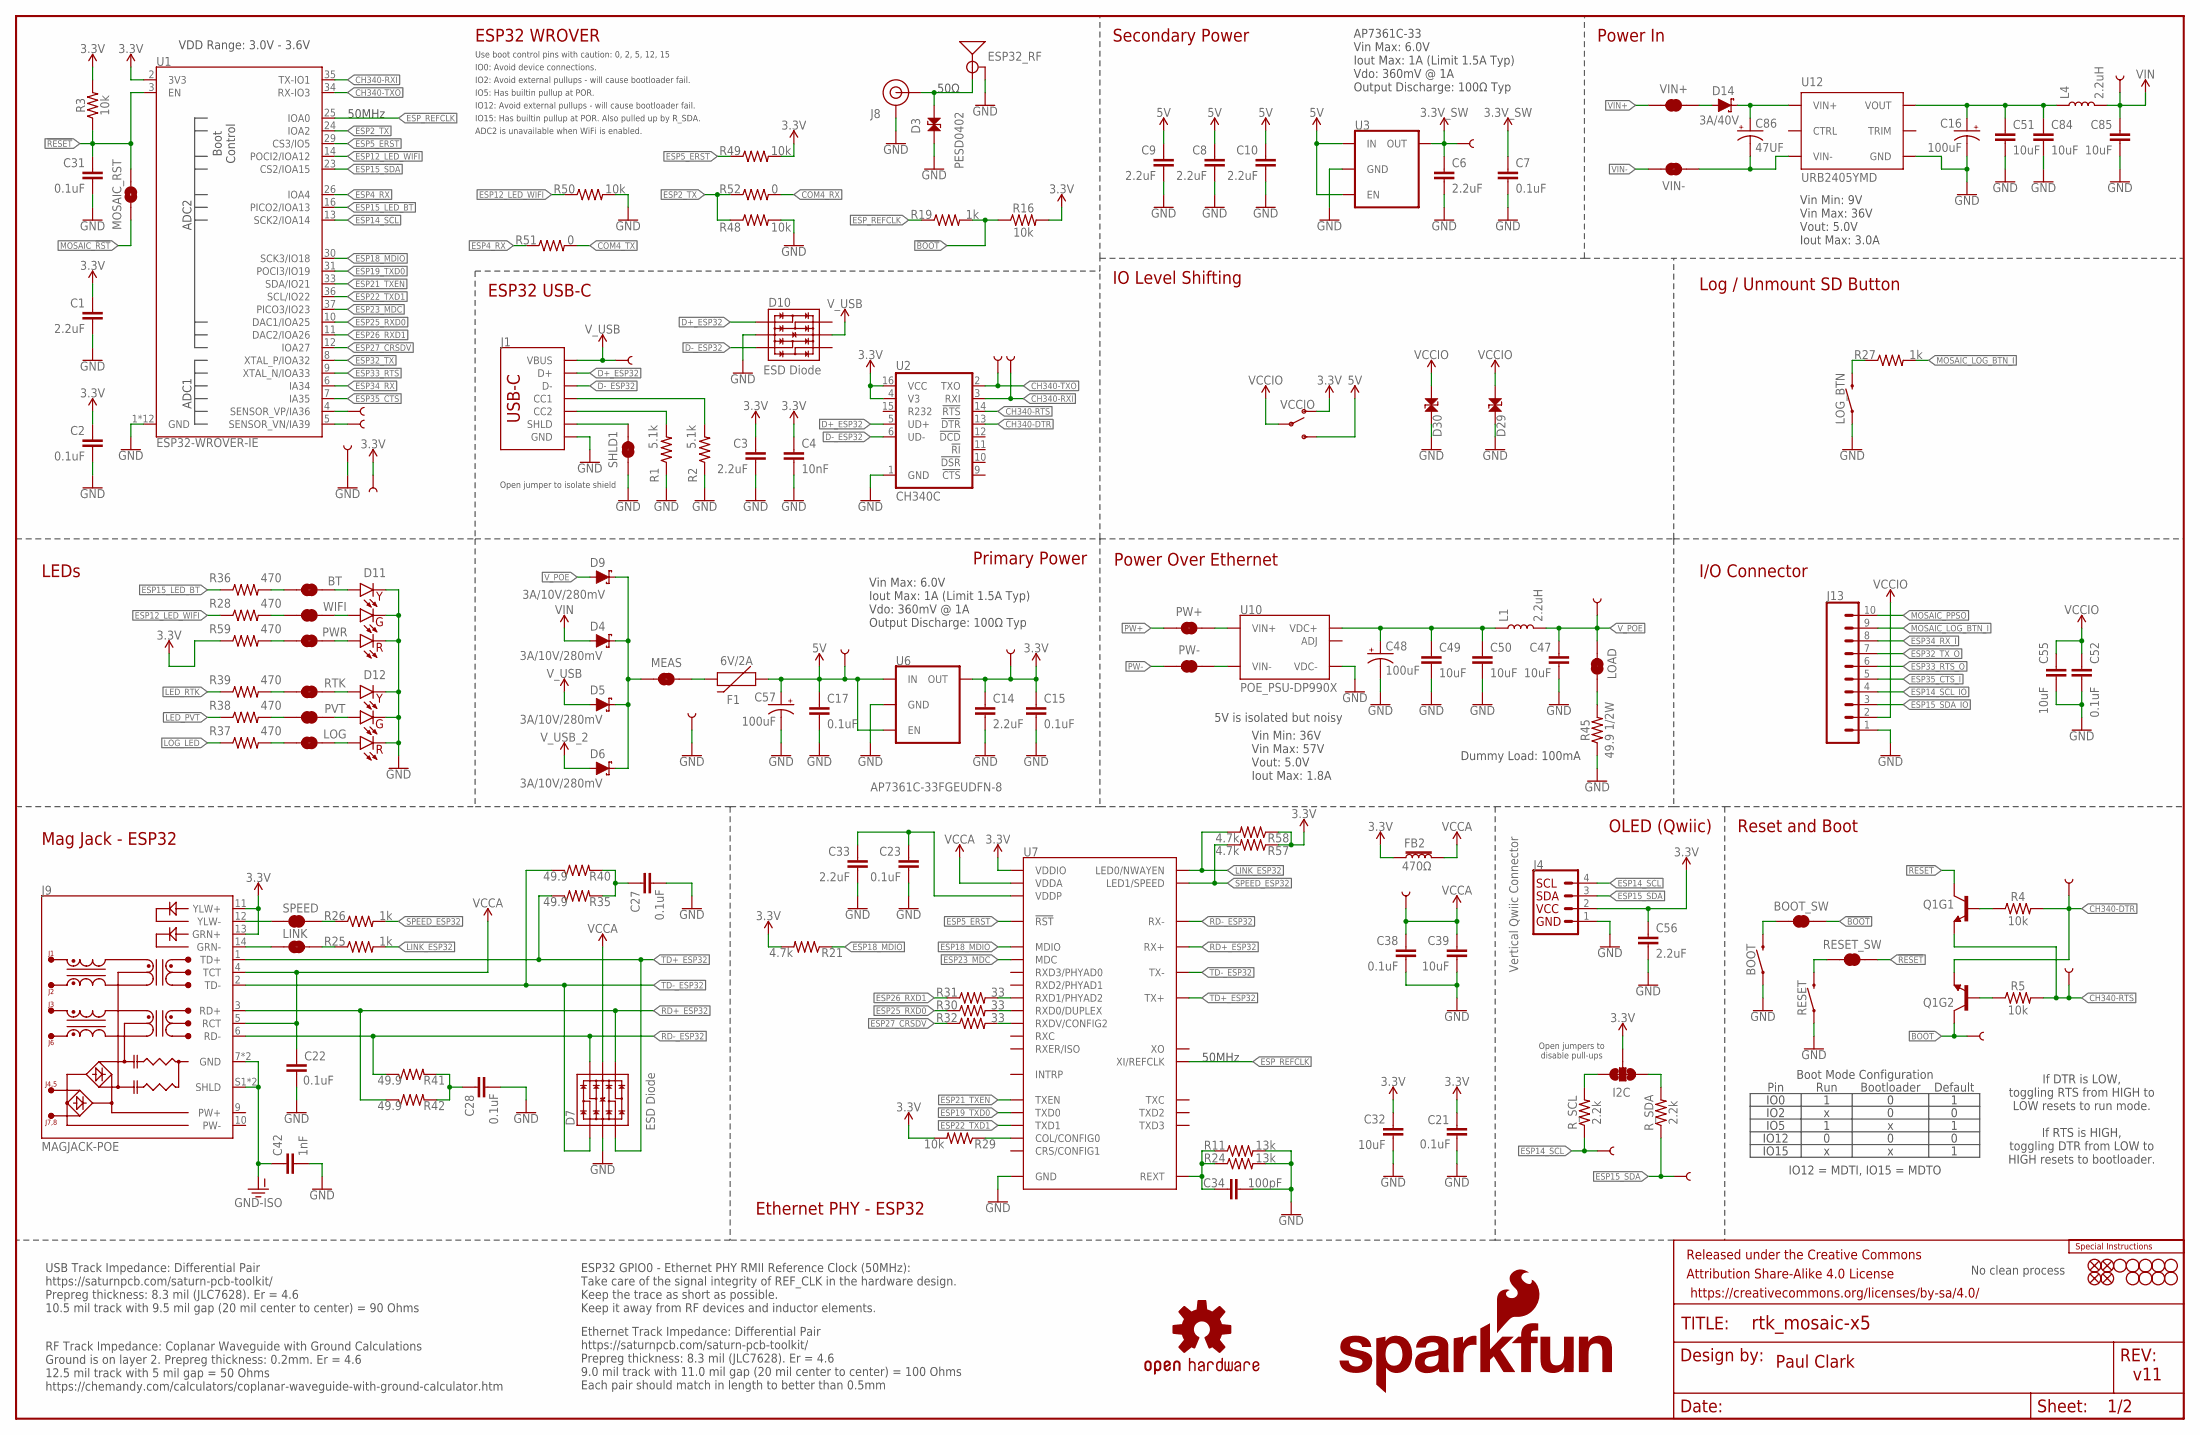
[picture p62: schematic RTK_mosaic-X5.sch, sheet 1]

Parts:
3V3, 3V3_SW, 5V: TEST-POINTPOGO_PTH; 1X01_NO_SILK
BOOT: MOMENTARY-SWITCH-SPST-PTH-RIGHT-ANGLE-8-020; TACTILE_SWITCH_PTH_RA_8-020
BOOT_SW: JUMPER-SMT_2_NC_TRACE_SILK; SMT-JUMPER_2_NC_TRACE_SILK
BT: JUMPER-SMT_2_NC_TRACE_SILK; SMT-JUMPER_2_NC_TRACE_SILK
C1, C3, C6, C8, C9, C10, C14, C33, C56: 2.2uF; 0603
C2, C7, C15, C17, C21, C22, C23, C27, C28, C31, C38, C52: 0.1uF; 0603
C4: 10nF; 0603
C16, C48, C57: 100uF; PANASONIC_D
C32, C39, C55: 10uF; 0603
C34: 100pF; 0603
C42: 1nF; 1206
C47, C49, C50, C51, C84, C85: 10uF; 0805
C86: 47UF; PANASONIC_D
D3, D29, D30: PESD0402; 0402
D4, D5, D6, D9: 3A/10V/280mV; SOD-323
D7, D10: ESD Diode; SOT-23-6
D11, D12: Yellow Green Red; CBI_LED_T-3MM_PTH
D14: 3A/40V; SMA-DIODE
DTR: TEST-POINTPOGO_PTH; 1X01_NO_SILK
ESP1, ESP2, ESP36, ESP39: TEST-POINTPOGO_PTH; 1X01_NO_SILK
ESP32_RF: ANTENNA-SMA-GROUNDEDEDGE_RPSMA; RP-SMA-EDGE
F1: 6V/2A; 1210
FB2: 470Ω; 0603
FD1, FD2, FD3, FD4: FIDUCIAL1X2; FIDUCIAL-1X2
FRAME1: FRAME-LEDGER; CREATIVE_COMMONS
GND: TEST-POINTPOGO_PTH; 1X01_NO_SILK
H1, H2, H3, H4, H5, H6, H7, H8, H10: STAND-OFFTIGHT; STAND-OFF-TIGHT
I2C: JUMPER-SMT_3_2-NC_TRACE_SILK; SMT-JUMPER_3_2-NC_TRACE_SILK
J1: USB_C_4-LAYER_PADS; USB-C-16P_4LAYER-PADS
J4: Vertical Qwiic Connector; JST04_1MM_VERT
J8: U.FL2PIN-REDUCED-FOOTPRINT; U.FL_REDUCED_FOOTPRINT
J9: MAGJACK-POE; MAGJACK-SYM_LED
J13: CONN_10_3.5MM_RA_HEADER; 1X10_SCREW_TERMINAL_3.5MM
L1, L4: 2.2uH; 0805-WIDE
LINK: JUMPER-SMT_2_NC_TRACE_SILK; SMT-JUMPER_2_NC_TRACE_SILK
LOAD: JUMPER-SMT_2_NC_TRACE_SILK; SMT-JUMPER_2_NC_TRACE_SILK
LOG: JUMPER-SMT_2_NC_TRACE_SILK; SMT-JUMPER_2_NC_TRACE_SILK
LOGO1: SPECIAL_INSTRUCTIONS-ORDERING; ORDERING_INSTRUCTIONS
LOGO4: OSHW-LOGOS; OSHW-LOGO-S
LOGO5: SFE_LOGO_NAME.2_INCH; SFE_LOGO_NAME_.2
LOGO6: SFE_LOGO_FLAME.2_INCH; SFE_LOGO_FLAME_.2
LOG_BTN: MOMENTARY-SWITCH-SPST-PTH-RIGHT-ANGLE-8-020; TACTILE_SWITCH_PTH_RA_8-020
MEAS: JUMPER-COMBO_2_NC_TRACE; COMBO-JUMPER_2_NC_TRACE
MOSAIC_RST: JUMPER-COMBO_2_NO; COMBO-JUMPER_2_NO
PVT: JUMPER-SMT_2_NC_TRACE_SILK; SMT-JUMPER_2_NC_TRACE_SILK
PW+: JUMPER-COMBO_2_NC_TRACE; COMBO-JUMPER_2_NC_TRACE
PW-: JUMPER-COMBO_2_NC_TRACE; COMBO-JUMPER_2_NC_TRACE
PWR: JUMPER-SMT_2_NC_TRACE_SILK; SMT-JUMPER_2_NC_TRACE_SILK
Q1: TRANS_NPN_DUAL-MBT3904DW1T1; SC70-6
R1, R2: 5.1k; 0603
R3, R4, R5, R16, R29, R48, R49, R50: 10k; 0603
R11, R24: 13k; 0603
R19, R25, R26, R27: 1k; 0603
R21, R57, R58: 4.7k; 0603
R28, R36, R37, R38, R39, R59: 470; 0603
R30, R31, R32: 33; 0603
R35, R40, R41, R42: 49.9; 0603
R45: 49.9 1/2W; 1206
R51, R52: 0; 0603
RESET: MOMENTARY-SWITCH-SPST-PTH-RIGHT-ANGLE-8-020; TACTILE_SWITCH_PTH_RA_8-020
RESET_SW: JUMPER-SMT_2_NC_TRACE_SILK; SMT-JUMPER_2_NC_TRACE_SILK
RTK: JUMPER-SMT_2_NC_TRACE_SILK; SMT-JUMPER_2_NC_TRACE_SILK
RTS: TEST-POINTPOGO_PTH; 1X01_NO_SILK
RX: TEST-POINTPOGO_PTH; 1X01_NO_SILK
R_SCL: 2.2k; 0603
R_SDA: 2.2k; 0603
SCL2: TEST-POINTPOGO_PTH; 1X01_NO_SILK
SDA2: TEST-POINTPOGO_PTH; 1X01_NO_SILK
SHLD1: JUMPER-SMT_2_NC_TRACE_SILK; SMT-JUMPER_2_NC_TRACE_SILK
SPEED: JUMPER-SMT_2_NC_TRACE_SILK; SMT-JUMPER_2_NC_TRACE_SILK
TP_BOOT: TEST-POINTPOGO_PTH; 1X01_NO_SILK
TX: TEST-POINTPOGO_PTH; 1X01_NO_SILK
U1: ESP32-WROVER-IE; ESP32-WROVER-E/IE
U2: CH340C; SO016
U3, U6: AP7361C-33FGEUDFN-8; UDFN-8
U7: KSZ8041NLI; MLF55Q-32LD
U10: POE_PSU-DP990X; DP990X
U12: URB2405YMD; URB_YMD-15WR3
VCCA: TEST-POINTPOGO_PTH; 1X01_NO_SILK
VCCIO: SWITCH-SPDT-SMD-AYZ0202; SWITCH_DPDT_SMD_AYZ0202
VIN: TEST-POINTPOGO_PTH; 1X01_NO_SILK
VIN+: JUMPER-COMBO_2_NC_TRACE; COMBO-JUMPER_2_NC_TRACE
VIN-: JUMPER-COMBO_2_NC_TRACE; COMBO-JUMPER_2_NC_TRACE
VPOE: TEST-POINTPOGO_PTH; 1X01_NO_SILK
VUSB: TEST-POINTPOGO_PTH; 1X01_NO_SILK
WIFI: JUMPER-SMT_2_NC_TRACE_SILK; SMT-JUMPER_2_NC_TRACE_SILK

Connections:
3.3V: 3V3.1, C1.1, C2.1, C3.1, C4.1, C14.1, C15.1, C21.1, C32.1, C56.1, ESP2.1, FB2.1, I2C.2, J4.2, J9.11 (YLW+), J9.13 (GRN+), R3.2, R16.2, R21.2, R29.2, R49.2, R57.1, R58.1, R59.1, U1.2 (3V3), U2.4 (V3), U2.16 (VCC), U6.1 (OUT), U7.17 (VDDIO), VCCIO.1 (O); also elsewhere on the board
3.3V_SW: 3V3_SW.1, C6.1, C7.1, U3.1 (OUT); also elsewhere on the board
5V: 5V.1, C8.1, C9.1, C10.1, C17.1, C57.+, F1.1, U3.5 (EN), U3.8 (IN), U6.5 (EN), U6.8 (IN), VCCIO.3 (S); also elsewhere on the board
5V_RAW: C48.+, C49.1, C50.1, L1.1, U10.1 (VDC+), U10.2 (VDC+)
5V_RAW1: C16.+, C51.1, C84.1, L4.1, U12.4 (VOUT)
!BOOT!: BOOT_SW.1, Q1.6 (C), R16.1, R19.2, TP_BOOT.1
!RESET!: C31.1, MOSAIC_RST.2, MOSAIC_RST.4 (2), Q1.3 (C), R3.1, RESET_SW.1, U1.3 (EN)
CH340-DTR: DTR.1, Q1.1 (E), R4.2, U2.13 (!DTR)
CH340-RTS: Q1.4 (E), R5.2, RTS.1, U2.14 (!RTS)
CH340-RXI: TX.1, U1.35 (TX-IO1), U2.3 (RXI)
CH340-TXO: RX.1, U1.34 (RX-IO3), U2.2 (TXO)
COM4_RX: R52.2; also elsewhere on the board
COM4_TX: R51.2; also elsewhere on the board
D+_ESP32: D10.1 (IO1), J1.A6 (D+), J1.B6 (D+), U2.5 (UD+)
D-_ESP32: D10.3 (IO2), J1.A7 (D-), J1.B7 (D-), U2.6 (UD-)
ESP2_TX: R48.1, R52.1, U1.24 (IOA2)
ESP4_RX: R51.1, U1.26 (IOA4)
ESP5_ERST: R49.1, U1.29 (CS3/IO5), U7.32 (!RST!)
ESP12_LED_WIFI: R28.1, R50.1, U1.14 (POCI2/IOA12)
ESP14_SCL: J4.4, R_SCL.1, SCL2.1, U1.13 (SCK2/IOA14); also elsewhere on the board
ESP14_SCL_IO: J13.4; also elsewhere on the board
ESP15_LED_BT: R36.1, U1.16 (PICO2/IOA13)
ESP15_SDA: J4.3, R_SDA.1, SDA2.1, U1.23 (CS2/IOA15); also elsewhere on the board
ESP15_SDA_IO: J13.3; also elsewhere on the board
ESP18_MDIO: R21.1, U1.30 (SCK3/IO18), U7.11 (MDIO)
ESP19_TXD0: U1.31 (POCI3/IO19), U7.24 (TXD0)
ESP21_TXEN: U1.33 (SDA/IO21), U7.23 (TXEN)
ESP22_TXD1: U1.36 (SCL/IO22), U7.25 (TXD1)
ESP23_MDC: U1.37 (PICO3/IO23), U7.12 (MDC)
ESP25_RXD0: R30.1, U1.10 (DAC1/IOA25)
ESP26_RXD1: R31.1, U1.11 (DAC2/IOA26)
ESP27_CRSDV: R32.1, U1.12 (IOA27)
ESP32_RF: D3.1, ESP32_RF.SIG (SIGNAL), J8.FEED (SIGNAL)
ESP32_TX: U1.8 (XTAL_P/IOA32); also elsewhere on the board
ESP32_TX_O: J13.7; also elsewhere on the board
ESP33_RTS: U1.9 (XTAL_N/IOA33); also elsewhere on the board
ESP33_RTS_O: J13.6; also elsewhere on the board
ESP34_RX: U1.6 (IA34); also elsewhere on the board
ESP34_RX_I: J13.8; also elsewhere on the board
ESP35_CTS: U1.7 (IA35); also elsewhere on the board
ESP35_CTS_I: J13.5; also elsewhere on the board
ESP36: ESP36.1, U1.4 (SENSOR_VP/IA36)
ESP39: ESP39.1, U1.5 (SENSOR_VN/IA39)
ESP_REFCLK: R19.1, U1.25 (IOA0), U7.9 (XI/REFCLK)
GND: BOOT.1, C1.2, C2.2, C3.2, C4.2, C6.2, C7.2, C8.2, C9.2, C10.2, C14.2, C15.2, C16.-, C17.2, C21.2, C22.2, C23.2, C27.2, C28.2, C31.2, C32.2, C33.2, C34.2, C38.2, C39.2, C42.2, C47.2, C48.-, C49.2, C50.2, C51.2, C52.2, C55.2, C56.2, C57.-, C84.2, C85.2, D3.2, D7.2 (VSS), D10.2 (VSS), D11.CATHODE_1 (YELLOW_CATHODE), D11.CATHODE_2 (GREEN_CATHODE), D11.CATHODE_3 (RED_CATHODE), D12.CATHODE_1 (YELLOW_CATHODE), D12.CATHODE_2 (GREEN_CATHODE), D12.CATHODE_3 (RED_CATHODE), D29.2, D30.2, ESP1.1, ESP32_RF.GND@0 (GND), ESP32_RF.GND@1 (GND), ESP32_RF.GND@2 (GND), ESP32_RF.GND@3 (GND), GND.1, J1.GND, J1.GND2 (GND), J4.1, J8.1 (GND), J8.2 (GND), J13.1, LOG_BTN.1, R1.1, R2.1, R11.2, R24.2, R45.1, R48.2, R50.2, RESET.1, SHLD1.1, U1.1 (GND), U1.15 (GND), U1.38 (GND), U1.GND, U1.GNDT1 (GND), U1.GNDT2 (GND), U1.GNDT3 (GND), U1.GNDT4 (GND), U1.GNDT5 (GND), U1.GNDT6 (GND), U1.GNDT7 (GND), U1.GNDT8 (GND), U2.1 (GND), U3.4 (GND), U3.EP (GND), U6.4 (GND), U6.EP (GND), U7.1 (GND), U7.GND, U10.3 (VDC-), U12.6 (GND); also elsewhere on the board
GND-ISO: C42.1, J9.7 (GND), J9.8 (GND), J9.S1 (SHLD), J9.S2 (SHLD); also elsewhere on the board
LED_PVT: R38.1; also elsewhere on the board
LED_RTK: R39.1; also elsewhere on the board
LINK_ESP32: R25.2, R58.2, U7.30 (LED0/NWAYEN)
LOG_LED: R37.1; also elsewhere on the board
MEAS: D4.C, D5.C, D6.C, D9.C, MEAS.2, MEAS.4 (2)
MOSAIC_!RST!: MOSAIC_RST.1, MOSAIC_RST.3 (1); also elsewhere on the board
MOSAIC_LOG_BTN_I: J13.9, R27.2; also elsewhere on the board
MOSAIC_PPSO: J13.10; also elsewhere on the board
unnamed: J1.B5 (CC2), R1.2
unnamed: J1.A5 (CC1), R2.2
unnamed: J9.14 (GRN-), LINK.1
unnamed: Q1.2 (B), R5.1
unnamed: Q1.5 (B), R4.1
unnamed: J9.12 (YLW-), SPEED.1
unnamed: F1.2, MEAS.1, MEAS.3 (1)
unnamed: LOG_BTN.2, R27.1
unnamed: R26.1, SPEED.2
unnamed: I2C.3, R_SCL.2
unnamed: I2C.1, R_SDA.2
unnamed: LOG.2, R37.2
unnamed: D12.ANODE_3 (RED_ANODE), LOG.1
unnamed: D11.ANODE_2 (GREEN_ANODE), WIFI.1
unnamed: C27.1, R35.2, R40.2
unnamed: C28.1, R41.2, R42.2
unnamed: LINK.2, R25.1
unnamed: BT.1, D11.ANODE_1 (YELLOW_ANODE)
unnamed: C23.1, C33.1, U7.2 (VDDP)
unnamed: C34.1, R11.1, R24.1, U7.10 (REXT)
unnamed: R29.1, U7.28 (COL/CONFIG0)
unnamed: BT.2, R36.2
unnamed: LOAD.1, R45.2
unnamed: RESET.2, RESET_SW.2
unnamed: BOOT.2, BOOT_SW.2
unnamed: R30.2, U7.16 (RXD0/DUPLEX)
unnamed: R31.2, U7.15 (RXD1/PHYAD2)
unnamed: R28.2, WIFI.2
unnamed: D12.ANODE_2 (GREEN_ANODE), PVT.1
unnamed: D12.ANODE_1 (YELLOW_ANODE), RTK.1
unnamed: R39.2, RTK.2
unnamed: PVT.2, R38.2
unnamed: R32.2, U7.18 (RXDV/CONFIG2)
unnamed: PWR.2, R59.2
unnamed: D11.ANODE_3 (RED_ANODE), PWR.1
PW1+: PW+.1, PW+.3 (1), U10.5 (VIN+), U10.6 (VIN+)
PW1-: PW-.1, PW-.3 (1), U10.7 (VIN-), U10.8 (VIN-)
PW+: PW+.2, PW+.4 (2); also elsewhere on the board
PW-: PW-.2, PW-.4 (2); also elsewhere on the board
RD+_ESP32: D7.4 (IO3), J9.3 (RD+), R42.1, U7.5 (RX+)
RD-_ESP32: D7.6 (IO4), J9.6 (RD-), R41.1, U7.4 (RX-)
SHIELD: J1.SHLD1 (SHLD), J1.SHLD2 (SHLD), J1.SHLD3 (SHLD), J1.SHLD4 (SHLD), SHLD1.2
SPEED_ESP32: R26.2, R57.2, U7.31 (LED1/SPEED)
TD+_ESP32: D7.3 (IO2), J9.1 (TD+), R35.1, U7.7 (TX+)
TD-_ESP32: D7.1 (IO1), J9.2 (TD-), R40.1, U7.6 (TX-)
VCCA: C22.1, C38.1, C39.1, D7.5 (VCC), FB2.2, J9.4 (TCT), J9.5 (RCT), U7.3 (VDDA), VCCA.1
VCCIO: C52.1, C55.1, D29.1, D30.1, J13.2, VCCIO.2; also elsewhere on the board
VIN: C85.1, D4.A, L4.2, VIN.1
VIN1+: D14.A, VIN+.1, VIN+.3 (1)
VIN1-: C86.-, U12.2 (VIN-), VIN-.2, VIN-.4 (2)
VIN2+: C86.+, D14.C, U12.3 (VIN+)
VIN+: VIN+.2, VIN+.4 (2); also elsewhere on the board
VIN-: VIN-.1, VIN-.3 (1); also elsewhere on the board
V_POE: C47.1, D9.A, L1.2, LOAD.2, VPOE.1
V_USB: D5.A, D10.5 (VCC), J1.VBUS1 (VBUS), J1.VBUS2 (VBUS), VUSB.1
V_USB_2: D6.A; also elsewhere on the board

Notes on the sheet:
ESP32 WROVER
ESP32 USB-C
Paul Clark
v11
Reset and Boot
Secondary Power
Primary Power
Ethernet PHY - ESP32
Mag Jack - ESP32
VDD Range: 3.0V - 3.6V
If DTR is LOW, toggling RTS from HIGH to LOW resets to run mode. If RTS is HIGH, toggling DTR from LOW to HIGH resets to bootloader.
Pin
IO0
IO2
IO12
IO15
IO5
Run
Bootloader
Default
IO12 = MDTI, IO15 = MDTO
Boot Mode Configuration
IO0: Avoid device connections.
ADC2 is unavailable when WiFi is enabled.
IO12: Avoid external pullups - will cause bootloader fail.
Use boot control pins with caution: 0, 2, 5, 12, 15
IO2: Avoid external pullups - will cause bootloader fail.
IO15: Has builtin pullup at POR. Also pulled up by R_SDA.
IO5: Has builtin pullup at POR.
Open jumpers to disable pull-ups
Open jumper to isolate shield
AP7361C-33 Vin Max: 6.0V Iout Max: 1A (Limit 1.5A Typ) Vdo: 360mV @ 1A Output Discharge: 100Ω Typ
RF Track Impedance: Coplanar Waveguide with Ground Calculations Ground is on layer 2. Prepreg thickness: 0.2mm. Er = 4.6 12.5 mil track with 5 mil gap = 50 Ohms https://chemandy.com/calculators/coplanar-waveguide-with-ground-calculator.htm
USB Track Impedance: Differential Pair https://saturnpcb.com/saturn-pcb-toolkit/ Prepreg thickness: 8.3 mil (JLC7628). Er = 4.6 10.5 mil track with 9.5 mil gap (20 mil center to center) = 90 Ohms
50Ω
Power Over Ethernet
5V is isolated but noisy
Dummy Load: 100mA
Power In
OLED (Qwiic)

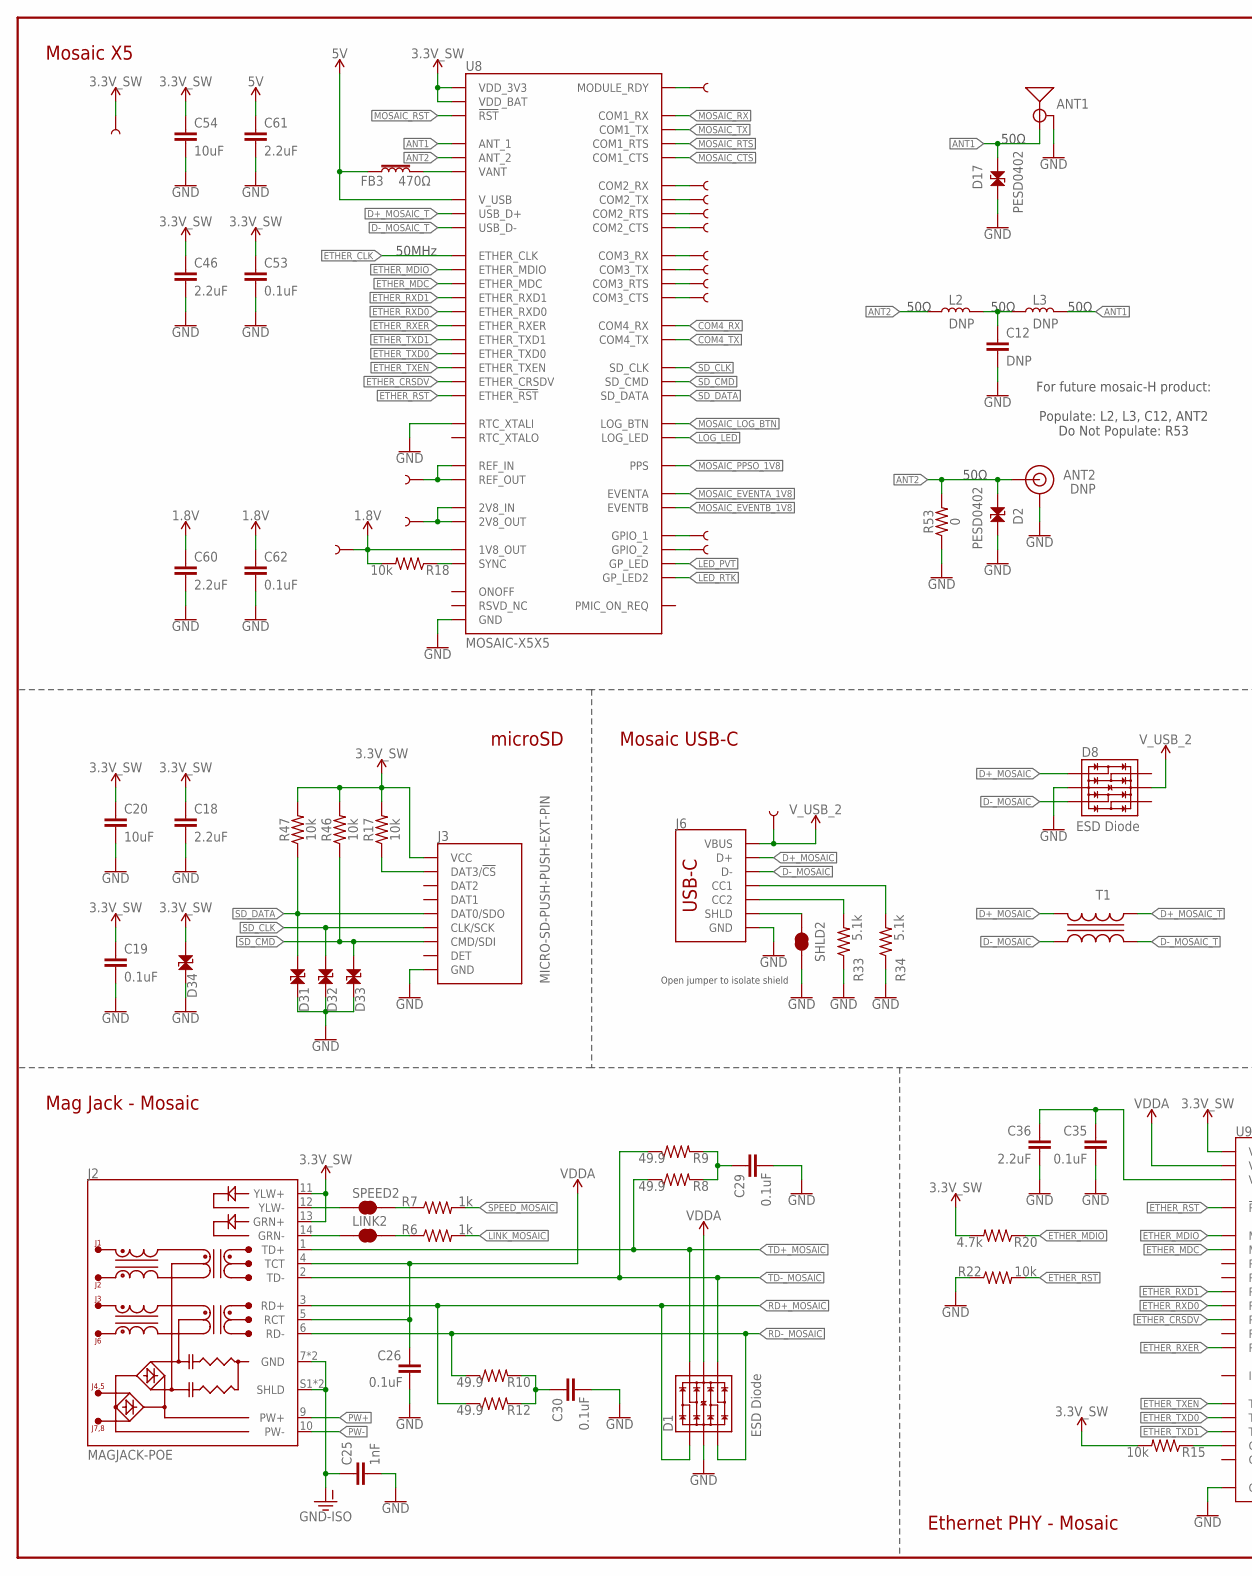
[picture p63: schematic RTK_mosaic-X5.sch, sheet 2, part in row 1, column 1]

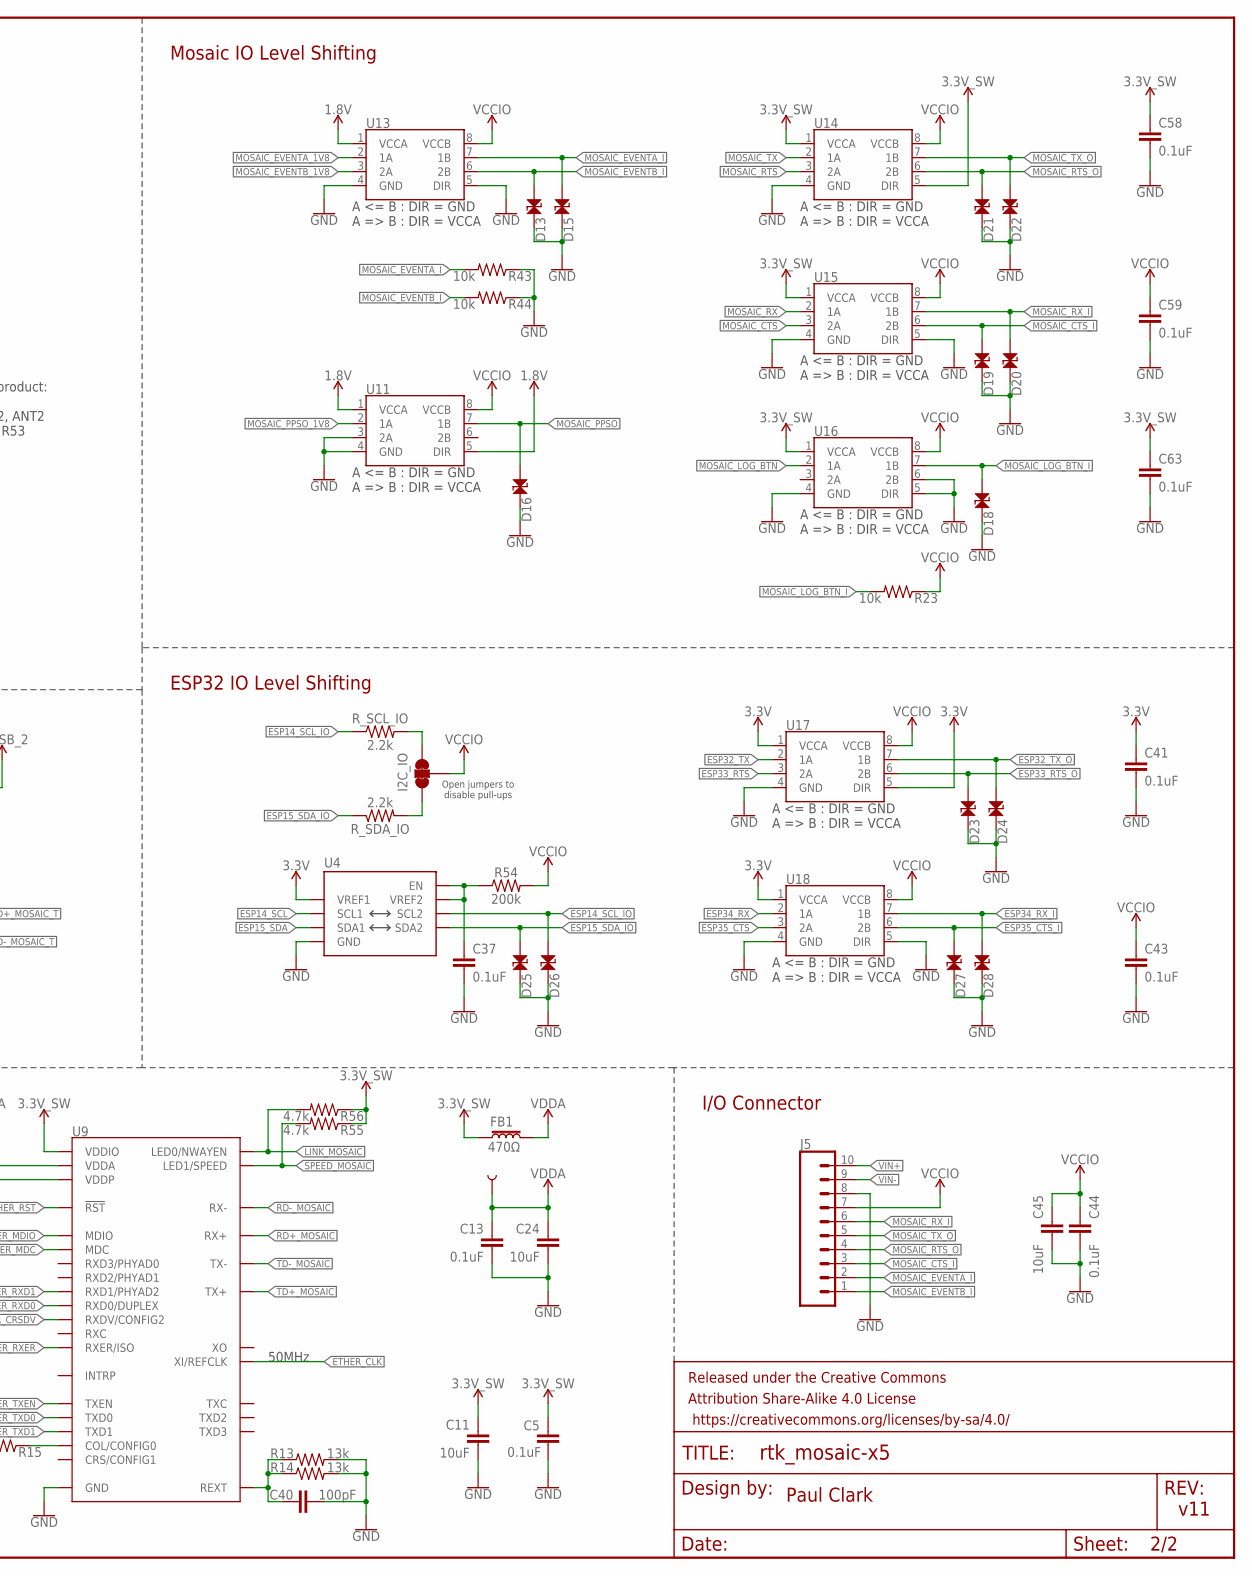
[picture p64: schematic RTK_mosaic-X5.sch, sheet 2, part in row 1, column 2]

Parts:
1V8, 2V8: TEST-POINTPOGO_PTH; 1X01_NO_SILK
ANT1: ANTENNA-SMA-GROUNDEDEDGE_SMA; SMA-EDGE
ANT2: DNP; U.FL_REDUCED_FOOTPRINT__NO_CREAM
C5, C13, C19, C26, C29, C30, C35, C37, C41, C43, C44, C53, C58, C59, C62, C63: 0.1uF; 0603
C11, C20, C24, C45, C54: 10uF; 0603
C12: DNP; 0603_NO_CREAM
C18, C36, C46, C60, C61: 2.2uF; 0603
C25: 1nF; 1206
C40: 100pF; 0603
COM2_CTS, COM2_RTS, COM2_RX, COM2_TX, COM3_CTS, COM3_RTS, COM3_RX, COM3_TX: TEST-POINTPOGO_PTH; 1X01_NO_SILK
D1, D8: ESD Diode; SOT-23-6
D2, D13, D15, D16, D17, D18, D19, D20, D21, D22, D23, D24, D25, D26, D27, D28, D31, D32, D33, D34: PESD0402; 0402
FB1, FB3: 470Ω; 0603
FRAME3: FRAME-LEDGERNO_FOOTPRINT; DUMMY
GPIO_1, GPIO_2: TEST-POINTPOGO_PTH; 1X01_NO_SILK
I2C_IO: JUMPER-SMT_3_2-NC_TRACE_SILK; SMT-JUMPER_3_2-NC_TRACE_SILK
J2: MAGJACK-POE; MAGJACK-SYM_LED
J3: MICRO-SD-PUSH-PUSH-EXT-PIN; MICROSD-EXTERNALPIN
J5: CONN_10_3.5MM_RA_HEADER; 1X10_SCREW_TERMINAL_3.5MM
J6: USB_C_4-LAYER_PADS; USB-C-16P_4LAYER-PADS
L2, L3: DNP; 0603_NO-CREAM
LINK2: JUMPER-SMT_2_NC_TRACE_SILK; SMT-JUMPER_2_NC_TRACE_SILK
R6, R7: 1k; 0603
R8, R9, R10, R12: 49.9; 0603
R13, R14: 13k; 0603
R15, R17, R18, R22, R23, R43, R44, R46, R47: 10k; 0603
R20, R55, R56: 4.7k; 0603
R33, R34: 5.1k; 0603
R53: 0; 0603
R54: 200k; 0603
RDY, RDY1: TEST-POINTPOGO_PTH; 1X01_NO_SILK
REF: TEST-POINTPOGO_PTH; 1X01_NO_SILK
R_SCL_IO: 2.2k; 0603
R_SDA_IO: 2.2k; 0603
SHLD2: JUMPER-SMT_2_NC_TRACE_SILK; SMT-JUMPER_2_NC_TRACE_SILK
SPEED2: JUMPER-SMT_2_NC_TRACE_SILK; SMT-JUMPER_2_NC_TRACE_SILK
T1: TRANSFORMER0508; RFCMF1220100M4T
U4: PCA9306VSSOP_8PIN; VSSOP_8PIN
U8: MOSAIC-X5X5; MOSAIC_LGA
U9: KSZ8041NLI; MLF55Q-32LD
U11, U13, U14, U15, U16, U17, U18: 74LVC2T45DC; VSSOP8_(SOT765-1)
VDDA: TEST-POINTPOGO_PTH; 1X01_NO_SILK
VUSB2: TEST-POINTPOGO_PTH; 1X01_NO_SILK

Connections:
1.8V: 1V8.1, C60.1, C62.1, R18.2, U8.AC4 (1V8_OUT), U11.1 (VCCA), U11.5 (DIR), U13.1 (VCCA)
2V8: 2V8.1, U8.M23 (2V8_IN), U8.N23 (2V8_OUT)
3.3V: C41.1, U4.P2 (VREF1), U17.1 (VCCA), U17.5 (DIR), U18.1 (VCCA); also elsewhere on the board
3.3V_SW: C5.1, C11.1, C18.1, C19.1, C20.1, C46.1, C53.1, C54.1, C58.1, C63.1, D34.1, FB1.1, J2.11 (YLW+), J2.13 (GRN+), J3.4 (VCC), R15.2, R17.2, R20.2, R46.2, R47.2, R55.1, R56.1, RDY1.1, U8.A18 (VDD_3V3), U8.A19 (VDD_3V3), U8.A20 (VDD_3V3), U8.B8 (VDD_BAT), U8.B18 (VDD_3V3), U8.B19 (VDD_3V3), U8.B20 (VDD_3V3), U8.C18 (VDD_3V3), U8.C19 (VDD_3V3), U8.C20 (VDD_3V3), U9.17 (VDDIO), U14.1 (VCCA), U14.5 (DIR), U15.1 (VCCA), U16.1 (VCCA); also elsewhere on the board
5V: C61.1, FB3.1, U8.A8 (V_USB); also elsewhere on the board
ANT1: ANT1.SIG (SIGNAL), D17.1, L3.2, U8.AC20 (ANT_1)
ANT2: ANT2.FEED (SIGNAL), D2.1, L2.1, R53.2, U8.V23 (ANT_2)
COM2_CTS: COM2_CTS.1, U8.J1 (COM2_CTS)
COM2_RTS: COM2_RTS.1, U8.G1 (COM2_RTS)
COM2_RX: COM2_RX.1, U8.F1 (COM2_RX)
COM2_TX: COM2_TX.1, U8.H1 (COM2_TX)
COM3_CTS: COM3_CTS.1, U8.N1 (COM3_CTS)
COM3_RTS: COM3_RTS.1, U8.L1 (COM3_RTS)
COM3_RX: COM3_RX.1, U8.K1 (COM3_RX)
COM3_TX: COM3_TX.1, U8.M1 (COM3_TX)
COM4_RX: U8.D3 (COM4_RX); also elsewhere on the board
COM4_TX: U8.E3 (COM4_TX); also elsewhere on the board
D+_MOSAIC: D8.1 (IO1), J6.A6 (D+), J6.B6 (D+), T1.A2
D+_MOSAIC_T: T1.A1, U8.A5 (USB_D+)
D-_MOSAIC: D8.3 (IO2), J6.A7 (D-), J6.B7 (D-), T1.B2
D-_MOSAIC_T: T1.B1, U8.A6 (USB_D-)
ESP14_SCL: U4.P3 (SCL1); also elsewhere on the board
ESP14_SCL_IO: D26.1, R_SCL_IO.1, U4.P6 (SCL2); also elsewhere on the board
ESP15_SDA: U4.P4 (SDA1); also elsewhere on the board
ESP15_SDA_IO: D25.1, R_SDA_IO.1, U4.P5 (SDA2); also elsewhere on the board
ESP32_TX: U17.2 (1A); also elsewhere on the board
ESP32_TX_O: D24.1, U17.7 (1B); also elsewhere on the board
ESP33_RTS: U17.3 (2A); also elsewhere on the board
ESP33_RTS_O: D23.1, U17.6 (2B); also elsewhere on the board
ESP34_RX: U18.2 (1A); also elsewhere on the board
ESP34_RX_I: D28.1, U18.7 (1B); also elsewhere on the board
ESP35_CTS: U18.3 (2A); also elsewhere on the board
ESP35_CTS_I: D27.1, U18.6 (2B); also elsewhere on the board
ETHER_!RST!: R22.2, U8.F2 (ETHER_!RST!), U9.32 (!RST!)
ETHER_CLK: U8.AA2 (ETHER_CLK), U9.9 (XI/REFCLK)
ETHER_CRSDV: U8.N2 (ETHER_CRSDV), U9.18 (RXDV/CONFIG2)
ETHER_MDC: U8.V2 (ETHER_MDC), U9.12 (MDC)
ETHER_MDIO: R20.1, U8.W2 (ETHER_MDIO), U9.11 (MDIO)
ETHER_RXD0: U8.R2 (ETHER_RXD0), U9.16 (RXD0/DUPLEX)
ETHER_RXD1: U8.T2 (ETHER_RXD1), U9.15 (RXD1/PHYAD2)
ETHER_RXER: U8.M2 (ETHER_RXER), U9.20 (RXER/ISO)
ETHER_TXD0: U8.J2 (ETHER_TXD0), U9.24 (TXD0)
ETHER_TXD1: U8.H2 (ETHER_TXD1), U9.25 (TXD1)
ETHER_TXEN: U8.L2 (ETHER_TXEN), U9.23 (TXEN)
GND: ANT1.GND@0 (GND), ANT1.GND@1 (GND), ANT1.GND@2 (GND), ANT1.GND@3 (GND), ANT2.1 (GND), ANT2.2 (GND), C5.2, C11.2, C12.2, C13.2, C18.2, C19.2, C20.2, C24.2, C25.2, C26.2, C29.2, C30.2, C35.2, C36.2, C37.2, C40.2, C41.2, C43.2, C44.2, C45.2, C46.2, C53.2, C54.2, C58.2, C59.2, C60.2, C61.2, C62.2, C63.2, D1.2 (VSS), D2.2, D8.2 (VSS), D13.2, D15.2, D16.2, D17.2, D18.2, D19.2, D20.2, D21.2, D22.2, D23.2, D24.2, D25.2, D26.2, D27.2, D28.2, D31.2, D32.2, D33.2, D34.2, J3.6 (GND), J3.10 (GND), J3.11 (GND), J3.12 (GND), J3.13 (GND), J5.8, J6.GND, J6.GND2 (GND), R13.2, R14.2, R22.1, R33.1, R34.1, R43.1, R44.1, R53.1, SHLD2.1, U4.P1 (GND), U8.A3 (RTC_XTALI), U8.A4 (GND), U8.A7 (GND), U8.A15 (GND), U8.A16 (GND), U8.A17 (GND), U8.A21 (GND), U8.A22 (GND), U8.A23 (GND), U8.AA13 (GND), U8.AA14 (GND), U8.AA15 (GND), U8.AA16 (GND), U8.AA17 (GND), U8.AA18 (GND), U8.AA19 (GND), U8.AA20 (GND), U8.AA21 (GND), U8.AA22 (GND), U8.AA23 (GND), U8.AB2 (GND), U8.AB3 (GND), U8.AB4 (GND), U8.AB5 (GND), U8.AB6 (GND), U8.AB7 (GND), U8.AB8 (GND), U8.AB13 (GND), U8.AB14 (GND), U8.AB15 (GND), U8.AB16 (GND), U8.AB17 (GND), U8.AB18 (GND), U8.AB19 (GND), U8.AB20 (GND), U8.AB21 (GND), U8.AB22 (GND), U8.AB23 (GND), U8.AC13 (GND), U8.AC15 (GND), U8.AC18 (GND), U8.AC19 (GND), U8.AC21 (GND), U8.AC22 (GND), U8.AC23 (GND), U8.B4 (GND), U8.B5 (GND), U8.B6 (GND), U8.B7 (GND), U8.B13 (GND), U8.B17 (GND), U8.B21 (GND), U8.C4 (GND), U8.C7 (GND), U8.C15 (GND), U8.C16 (GND), U8.C17 (GND), U8.C23 (GND), U8.D2 (GND), U8.D21 (GND), U8.D22 (GND), U8.D23 (GND), U8.E2 (GND), U8.E21 (GND), U8.E22 (GND), U8.E23 (GND), U8.F21 (GND), U8.F22 (GND), U8.F23 (GND), U8.G2 (GND), U8.G21 (GND), U8.G23 (GND), U8.H21 (GND), U8.H22 (GND), U8.H23 (GND), U8.J21 (GND), U8.J22 (GND), U8.J23 (GND), U8.K2 (GND), U8.K21 (GND), U8.K22 (GND), U8.K23 (GND), U8.L21 (GND), U8.L22 (GND), U8.L23 (GND), U8.M21 (GND), U8.M22 (GND), U8.N21 (GND), U8.N22 (GND), U8.P1 (GND), U8.P2 (GND), U8.P3 (GND), U8.P21 (GND), U8.P22 (GND), U8.R3 (GND), U8.R21 (GND), U8.R22 (GND), U8.T21 (GND), U8.T22 (GND), U8.T23 (GND), U8.U2 (GND), U8.U21 (GND), U8.U22 (GND), U8.U23 (GND), U8.V21 (GND), U8.V22 (GND), U8.W21 (GND), U8.W22 (GND), U8.W23 (GND), U8.Y2 (GND), U8.Y21 (GND), U8.Y22 (GND), U8.Y23 (GND), U9.1 (GND), U9.GND, U11.3 (2A), U11.4 (GND), U13.4 (GND), U13.5 (DIR), U14.4 (GND), U15.4 (GND), U15.5 (DIR), U16.4 (GND), U16.5 (DIR), U16.6 (2B), U17.4 (GND), U18.4 (GND), U18.5 (DIR); also elsewhere on the board
GND-ISO: C25.1, J2.7 (GND), J2.8 (GND), J2.S1 (SHLD), J2.S2 (SHLD); also elsewhere on the board
GPIO_1: GPIO_1.1, U8.AA4 (GPIO_1)
GPIO_2: GPIO_2.1, U8.L3 (GPIO_2)
LED_PVT: U8.A14 (GP_LED); also elsewhere on the board
LED_RTK: U8.M3 (GP_LED2); also elsewhere on the board
LINK_MOSAIC: R6.2, R56.2, U9.30 (LED0/NWAYEN)
LOG_LED: U8.B2 (LOG_LED); also elsewhere on the board
MOSAIC_!RST!: U8.A11 (!RST!); also elsewhere on the board
MOSAIC_CTS: U8.E1 (COM1_CTS), U15.3 (2A)
MOSAIC_CTS_I: D19.1, J5.3, U15.6 (2B)
MOSAIC_EVENTA_1V8: U8.AC6 (EVENTA), U13.2 (1A)
MOSAIC_EVENTA_I: D15.1, J5.2, R43.2, U13.7 (1B)
MOSAIC_EVENTB_1V8: U8.AC7 (EVENTB), U13.3 (2A)
MOSAIC_EVENTB_I: D13.1, J5.1, R44.2, U13.6 (2B)
MOSAIC_LOG_BTN: U8.K3 (LOG_BTN), U16.2 (1A)
MOSAIC_LOG_BTN_I: D18.1, R23.2, U16.7 (1B); also elsewhere on the board
MOSAIC_PPSO: D16.1, U11.7 (1B); also elsewhere on the board
MOSAIC_PPSO_1V8: U8.AC8 (PPS), U11.2 (1A)
MOSAIC_RTS: U8.C1 (COM1_RTS), U14.3 (2A)
MOSAIC_RTS_O: D21.1, J5.4, U14.6 (2B)
MOSAIC_RX: U8.B1 (COM1_RX), U15.2 (1A)
MOSAIC_RX_I: D20.1, J5.6, U15.7 (1B)
MOSAIC_TX: U8.D1 (COM1_TX), U14.2 (1A)
MOSAIC_TX_O: D22.1, J5.5, U14.7 (1B)
unnamed: C37.1, R54.1, U4.P7 (VREF2), U4.P8 (EN)
unnamed: J6.SHLD1 (SHLD), J6.SHLD2 (SHLD), J6.SHLD3 (SHLD), J6.SHLD4 (SHLD), SHLD2.2
unnamed: R18.1, U8.AC3 (SYNC)
unnamed: C12.1, L2.2, L3.1
unnamed: J6.B5 (CC2), R33.2
unnamed: J6.A5 (CC1), R34.2
unnamed: J2.14 (GRN-), LINK2.1
unnamed: J2.12 (YLW-), SPEED2.1
unnamed: I2C_IO.3, R_SCL_IO.2
unnamed: I2C_IO.1, R_SDA_IO.2
unnamed: R7.1, SPEED2.2
unnamed: LINK2.2, R6.1
unnamed: C29.1, R8.2, R9.2
unnamed: C30.1, R10.2, R12.2
unnamed: C35.1, C36.1, U9.2 (VDDP)
unnamed: C40.1, R13.1, R14.1, U9.10 (REXT)
unnamed: R15.1, U9.28 (COL/CONFIG0)
PW+: J2.9 (PW+); also elsewhere on the board
PW-: J2.10 (PW-); also elsewhere on the board
RD+_MOSAIC: D1.1 (IO1), J2.3 (RD+), R12.1, U9.5 (RX+)
RD-_MOSAIC: D1.3 (IO2), J2.6 (RD-), R10.1, U9.4 (RX-)
RDY: RDY.1, U8.A12 (MODULE_RDY)
REF: REF.1, U8.AC16 (REF_OUT), U8.AC17 (REF_IN)
SD_CLK: D32.1, J3.5 (CLK/SCK), U8.AA1 (SD_CLK)
SD_CMD: D33.1, J3.3 (CMD/SDI), R46.1, U8.AB1 (SD_CMD)
SD_DAT3: J3.2 (DAT3/!CS!), R17.1
SD_DATA: D31.1, J3.7 (DAT0/SDO), R47.1, U8.Y1 (SD_DATA)
SPEED_MOSAIC: R7.2, R55.2, U9.31 (LED1/SPEED)
TD+_MOSAIC: D1.6 (IO4), J2.1 (TD+), R8.1, U9.7 (TX+)
TD-_MOSAIC: D1.4 (IO3), J2.2 (TD-), R9.1, U9.6 (TX-)
VANT: FB3.2, U8.P23 (VANT), U8.R23 (VANT)
VCCIO: C43.1, C44.1, C45.1, C59.1, I2C_IO.2, J5.7, R23.1, R54.2, U11.8 (VCCB), U13.8 (VCCB), U14.8 (VCCB), U15.8 (VCCB), U16.8 (VCCB), U17.8 (VCCB), U18.8 (VCCB); also elsewhere on the board
VDDA: C13.1, C24.1, C26.1, D1.5 (VCC), FB1.2, J2.4 (TCT), J2.5 (RCT), U9.3 (VDDA), VDDA.1
VIN+: J5.10; also elsewhere on the board
VIN-: J5.9; also elsewhere on the board
V_USB_2: D8.5 (VCC), J6.VBUS1 (VBUS), J6.VBUS2 (VBUS), VUSB2.1; also elsewhere on the board

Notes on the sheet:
microSD
Mosaic USB-C
Open jumper to isolate shield
Ethernet PHY - Mosaic
Mag Jack - Mosaic
I/O Connector
Mosaic X5
Mosaic IO Level Shifting
50Ω
Paul Clark
v11
For future mosaic-H product: Populate: L2, L3, C12, ANT2 Do Not Populate: R53
Open jumpers to disable pull-ups
ESP32 IO Level Shifting
50MHz

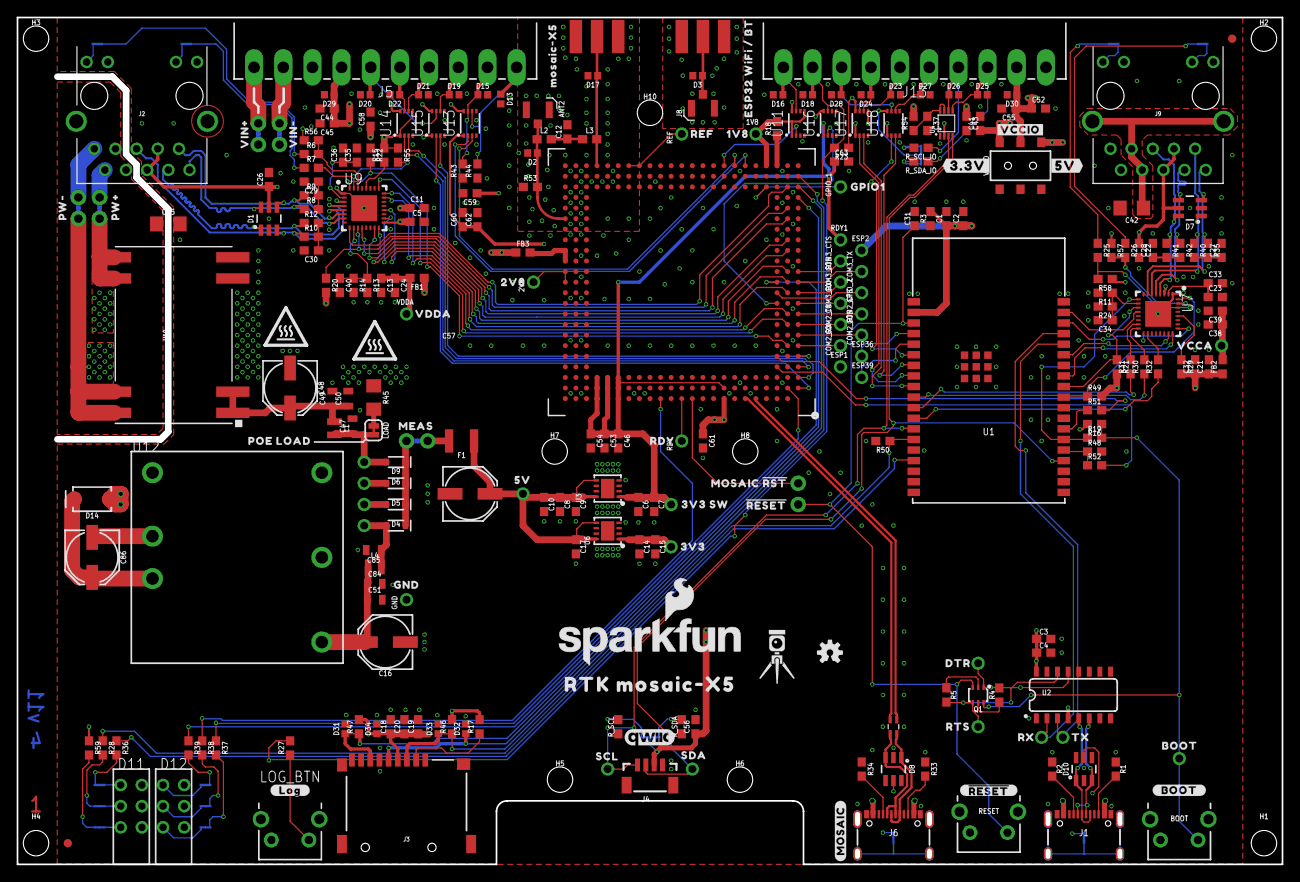
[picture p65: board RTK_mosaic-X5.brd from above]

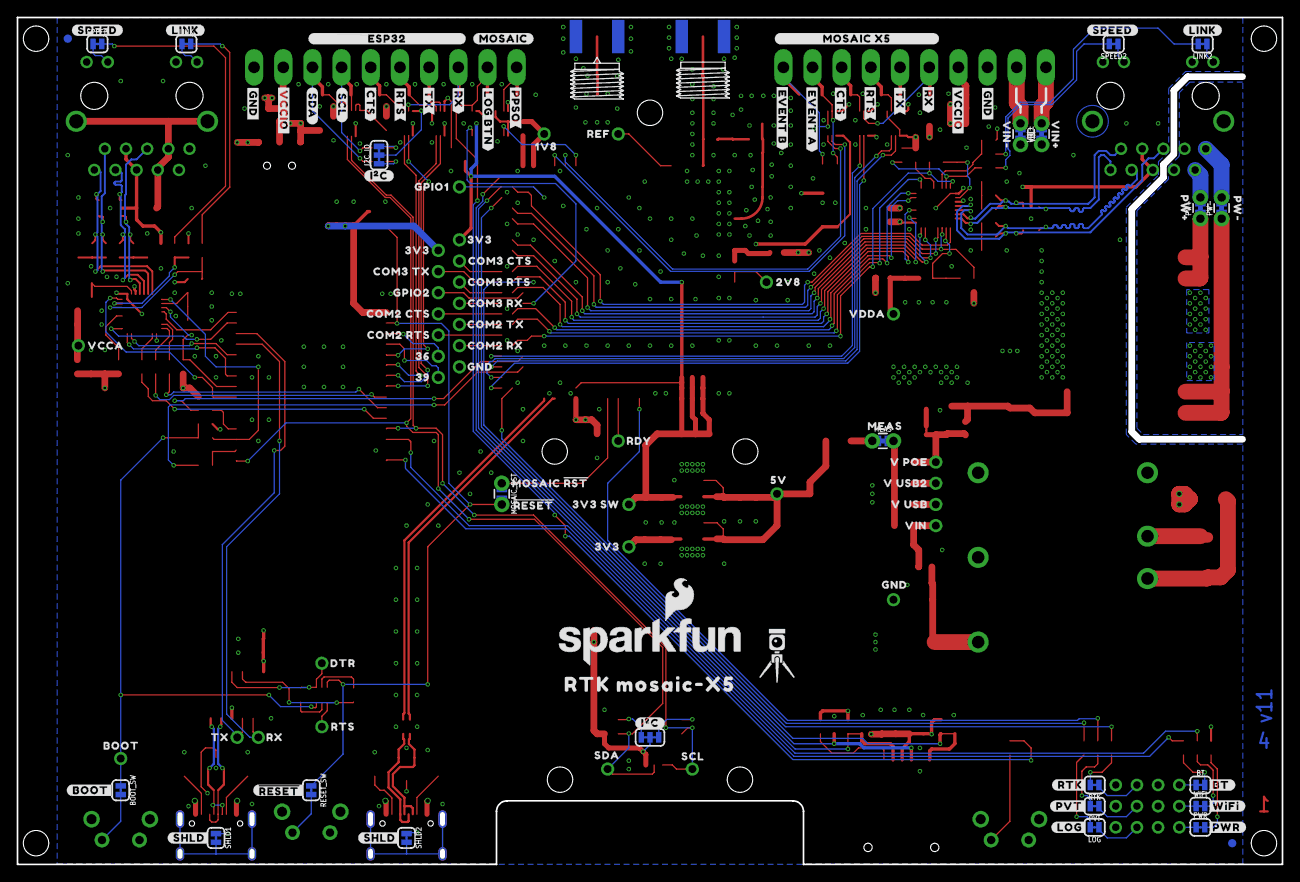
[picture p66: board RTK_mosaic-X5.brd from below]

Board: 4 copper layers, 151.8 x 101.6 mm, 408 parts (108 on the bottom side), 184 nets.

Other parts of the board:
LOGO2: QWIIC_LOGO_6MM; QWIIC_6MM
LOGO7: SFE_LOGO_NAME.2_INCH; SFE_LOGO_NAME_.2
LOGO8: SFE_LOGO_FLAME.2_INCH; SFE_LOGO_FLAME_.2
U$2: MOSAIC#X50
U$3, U$45: #SHLD#0
U$4, U$74: #RESET#0
U$5, U$113: PW#0
U$6, U$114: PW#1
U$7: ##RESET##5
U$8, U$46: #I�C#0
U$9, U$73: MOSAIC_#RST#6
U$10, U$120: #LINK#1
U$11: #LOG#4
U$12: #PVT#2
U$13: #RTK#3
U$14: #BT#2
U$15: #BOOT#6
U$16: #_______________MOSAIC_X5_______________#8
U$17, U$31: #RX#2
U$18, U$32: #TX#3
U$19, U$29: #RTS#4
U$20, U$30: #CTS#5
U$21: ESP32_WIFI_#_BT0
U$22: #EVENT_A#6
U$23: #EVENT_B#7
U$24, U$107: VCCA0
U$25, U$28: #GND#0
U$26, U$27, U$100: #VCCIO#1
U$33: #PPSO#11
U$34: #LOG_BTN#33
U$35: #SCL#10
U$36: #SDA#9
U$37, U$119: #MOSAIC#8
U$38: #___________________ESP32___________________#34
U$39: #3#3V#6
U$40: #5V#0
U$41, U$42: 2V8220
U$43, U$44: BOOT2
U$47: COM2_CTS219
U$48: COM2_RTS219
U$49: COM2_RX219
U$54: COM2_TX219
U$55, U$76: RTS2231
U$56, U$77: DTR2232
U$57: COM3_CTS18
U$58: COM3_RTS18
U$59, U$88: 3V3_SW25
U$60, U$87: 3V325
U$61, U$86: 5V25
U$62, U$84: MEAS2
U$63, U$70: VIN#0
U$64: COM3_RX219
U$65: COM3_TX18
U$66, U$67: GPIO17
U$68: GPIO218
U$69, U$99: RTK_MOSAIC#X50
U$71, U$72: VIN#1
U$75, U$78: RDY5
U$79, U$80: REF219
U$81: V_POE0
U$82: V_USB3
U$83: V_USB24
U$85: VIN1
U$89, U$90: RX0
U$91, U$92: SCL3
U$93, U$94: SDA4
U$95, U$96: TX1
U$97, U$98: VDDA220
U$101, U$102: 1V80
U$103: #PWR#0
U$104: #WIFI#1
U$105: 360
U$106: 39361
U$108: GND39362
U$109, U$110: 3V339362
U$116: #_LOG_#5
U$117: #_#RESET#_#0
U$118: #_BOOT_#1
U$121, U$122: #SPEED#0
U$135, U$143: GND12
U$136: POE_LOAD0
U$146, U$147: HIGH_TEMP_WARNING
U$152, U$153: RTK5#SVG0

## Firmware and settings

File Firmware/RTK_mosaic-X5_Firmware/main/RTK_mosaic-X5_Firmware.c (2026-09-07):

/* 

   SparkFun RTK mosaic-X5 Firmware

   The firmware has two modes:
   1 - Ethernet (default)
   2 - WiFi

   In Mode 1, the RTK mosaic-X5 should be connected directly to an Ethernet network. Use a
   standard Ethernet patch cable to connect the MOSAIC ETHERNET port to your network.
   The RTK mosaic-X5 supports Power-over-Ethernet (PoE), allowing it to be powered by the
   network too.
   In Mode 1 the ESP32 requests NMEA GGA information from the X5 over COM4. It displays the
   GGA data (time and position) on the built-in OLED display, together with the X5's Ethernet
   IP address. Open a web browser and navigate to that address to view the X5's internal web page.
   In Mode 1 the ESP32 does not modify the X5's Ethernet settings, allowing you to change and
   save the settings without them being overwritten.

   Mode 2 allows you to connect the RTK mosaic-X5 to your WiFi network. Link the MOSAIC and
   ESP32 ETHERNET ports using a standard Ethernet patch cable. The ESP32 acts as a WiFi Bridge,
   forwarding all traffic from X5 Ethernet to WiFi and vice versa.
   The WiFi SSID and password are set using the CONFIG ESP32 USB serial console.
   Once the ESP32 is connected to WiFi, you can view the X5's internal web page at the IP address
   shown on the OLED display.
   In Mode 2 the ESP32 sets the X5 Ethernet interface to DHCP, so that the X5 can request an IP
   address from the WiFi router transparently through the ESP32.

   The mode can be changed via the CONFIG ESP32 USB serial console. Connect to the CONFIG ESP32
   USB port and open a terminal at 115200 baud to see the console. Type help for help.

   E.g.:

   help
   show
   set --mode=2 --ssid=SSID --password=PASSWORD
   restart

   ---

   Updates September 7th 2026 (v1.0.6):

   ESP-IDF:
	 Bump to ESP-IDF v5.1.7
	 Add CONFIG_ETH_TRANSMIT_MUTEX=y
   WiFi mode improvements:
     Fixed an error where it was possible for the original ESP32 Ethernet MAC address to
      replace the desired spoofed mosaic-X5 MAC address
     The firmware ignores an all-zeros MAC Address in IPStatus (or an Ethernet packet)
        This was causing problems when starting in WiFi mode
     The IP_EVENT_STA_GOT_IP event IP address is copied to the OLED display
        This is received before the IPStatus update
        This ensures the IP address is displayed even if the IPStatus is missed
     The firmware no longer sends "seth,off" to turn Ethernet off before configuring DHCP
        It looks like this caused more problems than it solved
     Reduced the wait-for-IPStatus timeout from 5s to 3s
        It is received quicker than that
   General improvements:
     The minimal vTaskDelay has been increased from vTaskDelay(0) to vTaskDelay(1)
        This prevents unwanted Watchdog resets during during wait-for-command-response

   ---

   Updates April 22nd 2026 (v1.0.5):

   mosaic-X5 firmware 4.15.1 requires a mandatory user-defined username and password on IP interfaces.
   v1.0.5 adds the two nvm parameters x5_user (set -u) and x5_pass (set -x).
   If defined, these are passed to the X5 as "login,<x5_user>,<x5_pass>"
   
   Please note: the ESP32 does not _need_ to know the username and password _unless_ you also change
   the default access levels for the COM interfaces. Please see the docs for more details:
   https://docs.sparkfun.com/SparkFun_RTK_mosaic-X5/software_overview/#esp32-firmware-update

   Type help for help.

   E.g.:

   help
   show
   set --x5_user=USERNAME --x5_pass=PASSWORD
   restart

   ---

   Updates June 24th 2025 (v1.0.4):

   We've had one unit where the SBF and NMEA protocols became disabled on COM4, causing the ESP32
   firmware to hang. This version uses sdio to ensure SBF and NMEA are enabled on COM4 when starting.

   We've also had a unit where the NMEA prefix had been set to GN, instead of GP. This too
   caused the firmware to hang. This version is tolerant and can parse both GPGGA and GNGGA.

   A user requested that the position shown on the OLED was in DD MM SS.SSS format - same as
   the X5 internal web page. This version does that. The DDMM.MMMMM lat / lon in GPGGA is converted to
   DD MM SS.SSSS.

   Instead of using enoc and esoc to poll the NMEA GGA and SBF IPStatus messages, this version
   includes a parser which will extract:
   * lat, lon, etc. from periodic NMEA GGA messages on NMEA Stream10
   * the X5 Ethernet IP address from on-change IPStatus messages on SBF Stream10
   Sorry if you were using NMEA and SBF Stream10 for your own purposes!

   Because the GPGGA messages are periodic, not polled, the OLED is updated each time a GGA message is
   received - every second. The OLED displays UTC time from GGA, whereas the X5 web page displays GPS
   time. There is currently a difference of 18 seconds between the two.

   The altitude displayed on the OLED defaults to Orthometric height (height above MSL). This can be
   changed to include the geoid separation by changing the RTK_X5_DISPLAY_ALT_WITH_GEOID_SEPARATION
   configuration setting. The altitude displayed on the X5 web page includes the geoid separation.

   ---

   Written for and tested on ESP IDF v5.1.7

   Needs:
   idf.py add-dependency "espressif/ssd1306^1.0.5"

   Based on:

   mowi_wifi_client (WiFi to Ethernet packet forwarding with BLE based Provisioning)

   This example code is licensed under CC BY-SA 4.0 and OSHW Definition 1.0.

   For more information about MOWI visit https://github.com/septentrio-gnss/mowi/.

   This software is based on following ESP-IDF / ESP-IOT-SOLUTION examples:
   https://github.com/espressif/esp-idf/tree/master/examples/ethernet/eth2ap
   https://github.com/espressif/esp-iot-solution/tree/release/v1.1/examples/eth2wifi
   https://github.com/espressif/esp-idf/tree/master/examples/provisioning 

   This software is distributed on an "AS IS" BASIS, WITHOUT WARRANTIES OR
   CONDITIONS OF ANY KIND, either express or implied.
*/

#include <stdio.h>
#include <string.h>

#include <sdkconfig.h>
#include <freertos/FreeRTOS.h>
#include <freertos/task.h>
#include <freertos/event_groups.h>
#include <freertos/queue.h>

#include <esp_log.h>
#include <esp_wifi.h>
#include <esp_eth.h>
#include <esp_eth_driver.h>
#include <esp_mac.h>
#include <esp_event.h>
#include <esp_netif.h>
#include <nvs_flash.h>

#include <esp_private/wifi.h>
#include <driver/gpio.h>
#include <driver/uart.h>
#include <hal/uart_hal.h>

#include "ssd1306.h"
#include "ssd1306_fonts.h"
#include "fnt_5x8.h"

#include <esp_timer.h>
#include <driver/i2c.h>

#include <esp_console.h>
#include <esp_vfs_dev.h>
#include <linenoise/linenoise.h>
#include <argtable3/argtable3.h>
#include <esp_vfs_fat.h>
#include <nvs.h>
#include <nvs_flash.h>
#include "cmd_nvs.h"
#include "cmd_rtk.h"

#include <lwip/inet.h>
#include <lwip/ip4_addr.h>

/* The firmware version is updated by the Dockerfile */
static const char *VERSION = "Firmware v0.0.0";
static const char *TAG = "RTK_mosaic-X5_Firmware";
#define PROMPT_STR "RTK_X5"
static const char* prompt;

static esp_eth_handle_t s_eth_handle = NULL;
static esp_eth_mac_t *s_mac = NULL;
static esp_eth_phy_t *s_phy = NULL;
static QueueHandle_t flow_control_queue = NULL;

static uint8_t eth_mac[6];
static volatile bool eth_mac_is_set = false;
static bool wifi_is_connected = false;
static char ipAddress[25];

int* mode = NULL;
char* ssid = NULL;
char* password = NULL;
char* x5_user = NULL;
char* x5_pass = NULL;
char* esp_log_level = NULL;

const char *cidr2mask(uint8_t cidr) {
    switch (cidr) {
        default:
            return "Invalid";
            break;
        case 32:
            return "255.255.255.255";
            break;
        case 31:
            return "255.255.255.254";
            break;
        case 30:
            return "255.255.255.252";
            break;
        case 29:
            return "255.255.255.248";
            break;
        case 28:
            return "255.255.255.240";
            break;
        case 27:
            return "255.255.255.224";
            break;
        case 26:
            return "255.255.255.192";
            break;
        case 25:
            return "255.255.255.128";
            break;
        case 24:
            return "255.255.255.0";
            break;
        case 23:
            return "255.255.254.0";
            break;
        case 22:
            return "255.255.252.0";
            break;
        case 21:
            return "255.255.248.0";
            break;
        case 20:
            return "255.255.240.0";
            break;
        case 19:
            return "255.255.224.0";
            break;
        case 18:
            return "255.255.192.0";
            break;
        case 17:
            return "255.255.128.0";
            break;
        case 16:
            return "255.255.0.0";
            break;
        case 15:
            return "255.254.0.0";
            break;
        case 14:
            return "255.252.0.0";
            break;
        case 13:
            return "255.248.0.0";
            break;
        case 12:
            return "255.240.0.0";
            break;
        case 11:
            return "255.224.0.0";
            break;
        case 10:
            return "255.192.0.0";
            break;
        case 9:
            return "255.128.0.0";
            break;
        case 8:
            return "255.0.0.0";
            break;
        case 7:
            return "254.0.0.0";
            break;
        case 6:
            return "252.0.0.0";
            break;
        case 5:
            return "248.0.0.0";
            break;
        case 4:
            return "240.0.0.0";
            break;
        case 3:
            return "224.0.0.0";
            break;
        case 2:
            return "192.0.0.0";
            break;
        case 1:
            return "128.0.0.0";
            break;
        case 0:
            return "0.0.0.0";
            break;
    }
}

static volatile bool x5_uart_task_running = true;

typedef struct {
    void *packet;
    uint16_t length;
} flow_control_msg_t;

/* These could be in Kconfig, but who will want to change them? */
#define CONFIG_RTK_X5_MOSAIC_UART_PORT_NUM (1)
#define CONFIG_RTK_X5_MOSAIC_UART_BUF_SIZE (1024)
#define CONFIG_RTK_X5_WIFI_GPIO_PIN (12)
#define CONFIG_RTK_X5_BT_GPIO_PIN (13)
#define CONFIG_RTK_X5_UART_TX_GPIO_PIN (2)
#define CONFIG_RTK_X5_UART_RX_GPIO_PIN (4)
#define CONFIG_RTK_X5_ETHERNET_PHY_ADDR (1)
#define CONFIG_RTK_X5_ETHERNET_ERST_GPIO (5)
#define CONFIG_RTK_X5_ETHERNET_MDC_GPIO (23)
#define CONFIG_RTK_X5_ETHERNET_MDIO_GPIO (18)
// Unused IO UART pins
#define CONFIG_RTK_X5_IO_TX_GPIO_PIN (32)
#define CONFIG_RTK_X5_IO_RTS_GPIO_PIN (33)
#define CONFIG_RTK_X5_IO_RX_GPIO_PIN (34)
#define CONFIG_RTK_X5_IO_CTS_GPIO_PIN (35)


/* mosaic-X5 serial commands */
const char MOSAIC_CMD_ESCAPE[] = "SSSSSSSSSSSSSSSSSSSS\n\r";
const char MOSAIC_CMD_ESCAPE_RESPONSE[] = "COM4>";

const char MOSAIC_CMD_DATA_IN_OUT[] = "sdio,COM4,CMD,SBF+NMEA\n\r"; // Input: CMD; Output: SBF+NMEA
const char MOSAIC_CMD_DATA_IN_OUT_RESPONSE[] = "DataInOut";

const char MOSAIC_CMD_NMEA_STREAM10[] = "sno,Stream10,COM4,GGA,sec1\n\r"; // NMEA GGA every second
const char MOSAIC_CMD_NMEA_STREAM10_RESPONSE[] = "NMEAOutput";
const char MOSAIC_CMD_SBF_STREAM10[] = "sso,Stream10,COM4,IPStatus,OnChange\n\r"; // SBF IPStatus (4058) on change
const char MOSAIC_CMD_SBF_STREAM10_RESPONSE[] = "SBFOutput";

const char MOSAIC_CMD_ETHERNET_OFF[] = "seth,off\n\r";
const char MOSAIC_CMD_ETHERNET_OFF_RESPONSE[] = "EthernetMode";
const char MOSAIC_CMD_IP_DHCP[] = "sips,DHCP,,,,,,,1500\n\r";
const char MOSAIC_CMD_IP_DHCP_RESPONSE[] = "IPSettings";
const char MOSAIC_CMD_ETHERNET_ON[] = "seth,on\n\r";
const char MOSAIC_CMD_ETHERNET_ON_RESPONSE[] = "EthernetMode";

const char MOSAIC_CMD_EXE_IPSTATUS_ONCE[] = "esoc,COM4,IPStatus\n\r"; // Execute SBF IPStatus once

const char MOSAIC_CMD_SOFT_RESET[] = "erst,Soft,none\n\r"; // Execute soft reset
const char MOSAIC_CMD_SOFT_RESET_RESPONSE[] = "ResetReceiver";

/* I2C OLED */
#define I2C_HOST  0
#define RTK_X5_LCD_PIXEL_CLOCK_HZ    (400 * 1000)
#define RTK_X5_PIN_NUM_SDA           15
#define RTK_X5_PIN_NUM_SCL           14
#define RTK_X5_PIN_NUM_RST           -1
#define RTK_X5_OLED_HW_ADDR          0x3D

void print_text(char *txt); // Header
static ssd1306_handle_t disp;

const uint8_t oled_x_chars = 25; // 128 / 5
const uint8_t oled_y_chars = 8;  // 64 / 8
static char oled_text[25][8];
static bool oled_ready = false;
void x5_not_ready(void); // Header
void clear_oled_text(void); // Header
void print_oled(char *txt); // Header
void set_oled(char *txt); // Header
void update_oled(void); // Header
void display_IP(void); // Header
bool send_command_check_response(const char *command, const char *response, int64_t timeoutMillis, int waitMillis, int tries); // Header

/* Extra SSD1306 commands - if needed */
#define RTK_SSD1306_CMD_SET_MEMORY_ADDR_MODE  0x20
#define RTK_SSD1306_CMD_SET_COLUMN_RANGE      0x21
#define RTK_SSD1306_CMD_SET_PAGE_RANGE        0x22
#define RTK_SSD1306_CMD_SET_START_LINE        0x40
#define RTK_SSD1306_CMD_SET_CONTRAST_BANK0    0x81
#define RTK_SSD1306_CMD_SET_CHARGE_PUMP       0x8D
#define RTK_SSD1306_CMD_MIRROR_X_OFF          0xA0
#define RTK_SSD1306_CMD_MIRROR_X_ON           0xA1
#define RTK_SSD1306_CMD_DISPLAY_ALL_ON_RESUME 0xA4
#define RTK_SSD1306_CMD_INVERT_OFF            0xA6
#define RTK_SSD1306_CMD_INVERT_ON             0xA7
#define RTK_SSD1306_CMD_MULTIPLEX_RATIO       0xA8
#define RTK_SSD1306_CMD_DISP_OFF              0xAE
#define RTK_SSD1306_CMD_DISP_ON               0xAF
#define RTK_SSD1306_CMD_MIRROR_Y_OFF          0xC0
#define RTK_SSD1306_CMD_MIRROR_Y_ON           0xC8
#define RTK_SSD1306_CMD_DISPLAY_OFFSET        0xD3
#define RTK_SSD1306_CMD_CLOCK_DIVIDER         0xD5
#define RTK_SSD1306_CMD_PRE_CHARGE            0xD9
#define RTK_SSD1306_CMD_COM_PINS              0xDA
#define RTK_SSD1306_CMD_SET_VCOMH_DESELECT    0xDB

/* Console history - in NVS */
#define MOUNT_PATH "/data"
#define HISTORY_PATH MOUNT_PATH "/history.txt"

//
//    SBF Message
//
//    |<-- Preamble --->|
//    |                 |
//    +--------+--------+---------+---------+---------+---------+
//    |  SYNC  |  SYNC  |   CRC   |   ID    | Length  | Payload |
//    | 8 bits | 8 bits | 16 bits | 2 bytes | 2 bytes | n bytes |
//    |  0x24  |  0x40  |         |         |         |         |
//    +--------+--------+---------+---------+---------+---------+
//                                |                             |
//                                |<-------- Checksum --------->|
//
//  The generator polynomial for the CRC is the so-called CRC-CCITT
//  polynomial: x16 +x12 +x5 +x0. The CRC is computed in the forward
//  direction using a seed of 0, no reverse and no final XOR.

static const uint16_t ccitt_crc_table[256] = {
    0x0000, 0x1021, 0x2042, 0x3063, 0x4084, 0x50a5, 0x60c6, 0x70e7,
    0x8108, 0x9129, 0xa14a, 0xb16b, 0xc18c, 0xd1ad, 0xe1ce, 0xf1ef,
    0x1231, 0x0210, 0x3273, 0x2252, 0x52b5, 0x4294, 0x72f7, 0x62d6,
    0x9339, 0x8318, 0xb37b, 0xa35a, 0xd3bd, 0xc39c, 0xf3ff, 0xe3de,
    0x2462, 0x3443, 0x0420, 0x1401, 0x64e6, 0x74c7, 0x44a4, 0x5485,
    0xa56a, 0xb54b, 0x8528, 0x9509, 0xe5ee, 0xf5cf, 0xc5ac, 0xd58d,
    0x3653, 0x2672, 0x1611, 0x0630, 0x76d7, 0x66f6, 0x5695, 0x46b4,
    0xb75b, 0xa77a, 0x9719, 0x8738, 0xf7df, 0xe7fe, 0xd79d, 0xc7bc,
    0x48c4, 0x58e5, 0x6886, 0x78a7, 0x0840, 0x1861, 0x2802, 0x3823,
    0xc9cc, 0xd9ed, 0xe98e, 0xf9af, 0x8948, 0x9969, 0xa90a, 0xb92b,
    0x5af5, 0x4ad4, 0x7ab7, 0x6a96, 0x1a71, 0x0a50, 0x3a33, 0x2a12,
    0xdbfd, 0xcbdc, 0xfbbf, 0xeb9e, 0x9b79, 0x8b58, 0xbb3b, 0xab1a,
    0x6ca6, 0x7c87, 0x4ce4, 0x5cc5, 0x2c22, 0x3c03, 0x0c60, 0x1c41,
    0xedae, 0xfd8f, 0xcdec, 0xddcd, 0xad2a, 0xbd0b, 0x8d68, 0x9d49,
    0x7e97, 0x6eb6, 0x5ed5, 0x4ef4, 0x3e13, 0x2e32, 0x1e51, 0x0e70,
    0xff9f, 0xefbe, 0xdfdd, 0xcffc, 0xbf1b, 0xaf3a, 0x9f59, 0x8f78,
    0x9188, 0x81a9, 0xb1ca, 0xa1eb, 0xd10c, 0xc12d, 0xf14e, 0xe16f,
    0x1080, 0x00a1, 0x30c2, 0x20e3, 0x5004, 0x4025, 0x7046, 0x6067,
    0x83b9, 0x9398, 0xa3fb, 0xb3da, 0xc33d, 0xd31c, 0xe37f, 0xf35e,
    0x02b1, 0x1290, 0x22f3, 0x32d2, 0x4235, 0x5214, 0x6277, 0x7256,
    0xb5ea, 0xa5cb, 0x95a8, 0x8589, 0xf56e, 0xe54f, 0xd52c, 0xc50d,
    0x34e2, 0x24c3, 0x14a0, 0x0481, 0x7466, 0x6447, 0x5424, 0x4405,
    0xa7db, 0xb7fa, 0x8799, 0x97b8, 0xe75f, 0xf77e, 0xc71d, 0xd73c,
    0x26d3, 0x36f2, 0x0691, 0x16b0, 0x6657, 0x7676, 0x4615, 0x5634,
    0xd94c, 0xc96d, 0xf90e, 0xe92f, 0x99c8, 0x89e9, 0xb98a, 0xa9ab,
    0x5844, 0x4865, 0x7806, 0x6827, 0x18c0, 0x08e1, 0x3882, 0x28a3,
    0xcb7d, 0xdb5c, 0xeb3f, 0xfb1e, 0x8bf9, 0x9bd8, 0xabbb, 0xbb9a,
    0x4a75, 0x5a54, 0x6a37, 0x7a16, 0x0af1, 0x1ad0, 0x2ab3, 0x3a92,
    0xfd2e, 0xed0f, 0xdd6c, 0xcd4d, 0xbdaa, 0xad8b, 0x9de8, 0x8dc9,
    0x7c26, 0x6c07, 0x5c64, 0x4c45, 0x3ca2, 0x2c83, 0x1ce0, 0x0cc1,
    0xef1f, 0xff3e, 0xcf5d, 0xdf7c, 0xaf9b, 0xbfba, 0x8fd9, 0x9ff8,
    0x6e17, 0x7e36, 0x4e55, 0x5e74, 0x2e93, 0x3eb2, 0x0ed1, 0x1ef0
};

uint16_t ccitt_crc_update(uint16_t crc, const uint8_t data)
{
    uint8_t tbl_idx = ((crc >> 8) ^ data) & 0xff;
    
    crc = (ccitt_crc_table[tbl_idx]) ^ (crc << 8);

    return crc;
}

#define tokenValid ((*token != ',') && (*token != '*') && (*token != 0))
#define remainderValid ((*remainder != ',') && (*remainder != '*') && (*remainder != 0))

/* PACKETS / DATA FORWARDING */

// Forward packets from Wi-Fi to Ethernet
static esp_err_t pkt_wifi2eth(void *buffer, uint16_t len, void *eb)
{
    if (esp_eth_transmit(s_eth_handle, buffer, len) != ESP_OK) {
        ESP_LOGE(TAG, "Ethernet send packet failed");
    }
#if CONFIG_RTK_X5_VERBOSE_LOG
    else {
        uint8_t *ptr = (uint8_t *)buffer;
        ESP_LOGI(TAG, "Sent Ethernet packet L:%d D:%02X:%02X:%02X:%02X:%02X:%02X S:%02X:%02X:%02X:%02X:%02X:%02X IPS:%d.%d.%d.%d IPD:%d.%d.%d.%d",
            len, ptr[0], ptr[1], ptr[2], ptr[3], ptr[4], ptr[5], ptr[6], ptr[7], ptr[8], ptr[9], ptr[10], ptr[11],
            ptr[26], ptr[27], ptr[28], ptr[29], ptr[30], ptr[31], ptr[32], ptr[33]);
    }
#endif

    esp_wifi_internal_free_rx_buffer(eb);
    return ESP_OK;
}
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
void app_main(void)
{
    // Initialize NVS partition and file system
    initialize_nvs();
    initialize_filesystem();

    // Initialize auxiliary peripherals
    initialize_leds();
    initialize_uart();
    initialize_i2c();
    initialize_oled();

    // Initialize event loop
    ESP_ERROR_CHECK(esp_event_loop_create_default());

    /* Default settings */
    get_config_param_int("mode", &mode);
    if (mode == NULL) {
        // Default to Ethernet - leave X5 Ethernet configuration unchanged
        param_set_value_int(&mode, 1);
    }
    get_config_param_str("ssid", &ssid);
    if (ssid == NULL) {
        param_set_value_str(&ssid, "sparkfun-guest"); // Default SSID
    }
    get_config_param_str("password", &password);
    if (password == NULL) {
        param_set_value_str(&password, ""); // Default password
    }
    get_config_param_str("x5_user", &x5_user);
    if (x5_user == NULL) {
        param_set_value_str(&x5_user, ""); // Default X5 username
    }
    get_config_param_str("x5_pass", &x5_pass);
    if (x5_pass == NULL) {
        param_set_value_str(&x5_pass, ""); // Default X5 password
    }
    get_config_param_str("log_level", &esp_log_level);
    if (esp_log_level == NULL) {
        param_set_value_str(&esp_log_level, "warn");
    }
    set_log_level_by_str((const char *)esp_log_level);


    // Initialize console
    initialize_console();

    /* Register commands */
    esp_console_register_help_command();
    //register_nvs(); // We need nvs but don't need to register it. It just clutters up the help
    register_rtk();

    // Start the console
    start_console();

    // SparkFun production test for the unused TX/RX/RTS/CTS pins
    production_test();

    // Check the X5 is communicating and that the port is configured correctly
    initialize_X5();

    // Execute SBF IPStatus once - to force update of ipAddress
    // The reply will be handled by the x5_uart_task
    uart_write_bytes(CONFIG_RTK_X5_MOSAIC_UART_PORT_NUM, MOSAIC_CMD_EXE_IPSTATUS_ONCE, strlen(MOSAIC_CMD_EXE_IPSTATUS_ONCE));

    x5_uart_task_running = true; // Ensure the uart task is unpaused

    initialize_x5_uart_task(); // Start the uart task - parse incoming GPGGA and IPStatus messages

    // Check the mode
    if (*mode == 1) {
        ESP_LOGI(TAG, "Firmware is in mode 1: Ethernet");
        print_oled("Mode 1: Ethernet");
    }
    else
    {
        ESP_LOGI(TAG, "Firmware is in mode 2: WiFi");
        print_oled("Mode 2: WiFi");

        // Wait for up to 3 seconds for the IPStatus to be received
        int64_t timeMicros = esp_timer_get_time();
        while ((!eth_mac_is_set) && (esp_timer_get_time() < (timeMicros + (3000 * 1000))))
        {
            vTaskDelay(10);
        }

        if (!eth_mac_is_set)
        {
            ESP_LOGI(TAG, "IPStatus not received or MACAddress was all zeros");
            ESP_LOGI(TAG, "MAC address will be extracted from an Ethernet packet");
        }

        x5_uart_task_running = false; // Pause the uart task so send_command_check_response can receive the response

        // Initialize flow control and main peripherals
        ESP_ERROR_CHECK(initialize_flow_control());
        initialize_ethernet();
        initialize_wifi();

        x5_uart_task_running = true; // Unpause the uart task
    }

    print_oled("Waiting for signal");
}

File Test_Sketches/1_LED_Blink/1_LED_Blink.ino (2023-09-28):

/*
  SparkFun RTK mosaic-X5 Test Sketch

  License: MIT. Please see LICENSE.md for more details

  ESP32-WROVER-IE Pin Allocations:
  D0  : Boot + Boot Button + Ethernet REFCLK
  D1  : Serial TX (CH340 RX)
  D2  : Serial TX (mosaic-X5 COM4 RX)
  D3  : Serial RX (CH340 TX)
  D4  : Serial RX (mosaic-X5 COM4 TX)
  D5  : Ethernet ERST
  D12 : LED WiFi
  D13 : LED BT
  D14 : I2C SCL
  D15 : I2C SDA
  D16 : N/C
  D17 : N/C
  D18 : Ethernet MDIO
  D19 : Ethernet TXD0
  D21 : Ethernet TXEN
  D22 : Ethernet TXD1
  D23 : Ethernet MDC
  D25 : Ethernet RXD0
  D26 : Ethernet RXD1
  D27 : Ethernet CRSDV
  D32 : Serial TX (IO header)
  D33 : Serial RTS (IO header)
  A34 : Serial RX (IO header)
  A35 : Serial CTS (IO header)
  A36 : N/C
  A39 : N/C
*/

const int LED_WIFI = 12;
const int LED_BT = 13;
const int SCL_2 = 14;
const int SDA_2 = 15;

void setup()
{
  pinMode(LED_WIFI, OUTPUT);
  pinMode(LED_BT, OUTPUT);
}

void loop()
{
  digitalWrite(LED_WIFI, HIGH);
  digitalWrite(LED_BT, LOW);
  delay(500); // At 1Hz
  digitalWrite(LED_WIFI, LOW);
  digitalWrite(LED_BT, HIGH);
  delay(500); // At 1Hz
}

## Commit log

2023-07-18 Ready for airwire review
    [RTK_Mosaic_X5.brd, RTK_Mosaic_X5.sch]
2023-07-19 Silk added. Layer 15 polygon is now GND.
    [RTK_Mosaic_X5.brd, RTK_Mosaic_X5.sch]
2023-07-20 Tweaked and panelized
    [RTK_mosaic-X5-Panel.GBL, RTK_mosaic-X5-Panel.GBO, RTK_mosaic-X5-Panel.GBP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]
2023-07-20 Add panels
    [RTK_mosaic-X5_Front_Panel.brd, RTK_mosaic-X5_Front_Panel.sch, RTK_mosaic-X5_Rear_Panel.brd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]
2023-07-20 Correct Ethernet PHY pad numbering. Needs re-panelizing
    [RTK_mosaic-X5.brd, RTK_mosaic-X5.sch]
2023-07-21 Add second antenna connector for future mosaic-H product
    [RTK_mosaic-X5.brd, RTK_mosaic-X5.sch]
2023-07-21 Adding u.FL connector for mosaic-H - with standoff holes for a u.FL-SMA daughter board
    [RTK_mosaic-X5-Panel.GBL, RTK_mosaic-X5-Panel.GBO, RTK_mosaic-X5-Panel.GBS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]
2023-07-24 Add Phy PROD_ID. Ready for manufacture
    [RTK_mosaic-X5-Panel.brd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]
2023-08-31 V10 PCB - routed
    [RTK_mosaic-X5-Panel.GBL, RTK_mosaic-X5-Panel.GBO, RTK_mosaic-X5-Panel.GBP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]
2023-09-01 v10 - ready for manufacture
    [RTK_mosaic-X5-Panel.GBL, RTK_mosaic-X5-Panel.GBO, RTK_mosaic-X5-Panel.GBP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]
2023-09-05 Update front panel with new 1.3" OLED
    [RTK_mosaic-X5_Front_Panel.brd, RTK_mosaic-X5_Front_Panel.sch]
2023-09-14 Add STN BT Provisioning example - OLED QR Code display is WIP
    [partitions.csv]
2023-09-19 Add RTK_mosaic-X5_Firmware
    [partitions.csv]
2023-09-20 X5 COM4 UART GGA working
2023-09-21 KISS - two modes: WiFi Bridge and UART GGA
2023-09-28 Swap mode 1 and 2. Rename. Display GGA in both modes
    [RTK_mosaic-X5_Firmware.c]
2023-10-05 Initial docs commit. Still WIP
    [RTK_mosaic-X5-Panel.GBL, RTK_mosaic-X5-Panel.GBO, RTK_mosaic-X5-Panel.GBP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]
2023-10-09 Add stickers v1
    [RTK_mosaic-X5_Front_Sticker.dxf, RTK_mosaic-X5_Rear_Sticker.dxf]
2023-10-12 Add firmware production test - exercise unused 'UART' pins
2023-10-13 Move BT Prov example
    [partitions.csv]
2023-11-13 Fix Admonition
    Removes extra indent on the CH340 Driver section
2023-11-21 Update hardware_overview.md
    Re arrange power sections
2024-01-03 Add drawings for enclosure and antenna dimensions
2024-01-27 Add dimensions for enclosure
2024-01-27 Add assembly pictures
2024-01-27 Add images of enclosure panels
2024-01-27 Accent content tabs
    Accents added to fix white-on-white and dark-on-dark appearance as mentioned in this discussion: https://github.com/squidfunk/mkdocs-material/discussions/6699
2024-01-28 Update print_view.md
    Add missing sections
2024-02-01 v1.0.1 - increase flow control memory
2024-02-01 Limit speed to 10M for ESP32 PHY (WiFi mode)
2024-02-01 Update LICENSE.md
    Remove carriage returns
2024-02-01 v1.0.3 - improved UART retries and timeouts
2024-02-02 Updates for v1.1 PCB
    [RTK_mosaic-X5-Panel.brd, RTK_mosaic-X5.brd, RTK_mosaic-X5.sch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]
2024-02-12 Update extra.css
    Fix content tab aesthetic for titles including:
    - code blocks
    - keyboard buttons
2024-03-06 Update introduction.md
    Add GPS basics and Qwiic OLED tutorials
    Remove soldering tutorial (not required)
    Add RTK positioning blog post
    Add product comparison table
2024-10-18 Update Instructions
    Update the information for the L5 band:
    - Adds instructions for outputting RTCM messages for GPSL5 corrections
    Update note in NTRIP Server instructions
    - Adds admonition for click OK button
2024-10-18 Update print_view.md
    Add Onocoy mining section to print out
2025-06-26 Add soft reset. Better use of uart_read_bytes. Pin uart task to core 1. Fewer static methods.
    [RTK_mosaic-X5_Firmware.c]
2026-04-23 Add yields to help avoid watchdog resets. Only wait for MAC address in WiFi mode
    [RTK_mosaic-X5_Firmware.c]
2026-04-23 Correct docker lower case
2026-06-10 Add case and panel drawings and step files
2026-09-05 Prevent the original ESP32 MAC address from being copied into eth_mac
    [RTK_mosaic-X5_Firmware.c]
2026-09-08 Add missing netif init and event group create. OLED working
    [RTK_mosaic-X5_Firmware.c]
2026-09-09 Rework using sta2eth example
    [RTK_mosaic-X5_Firmware.c]
2026-09-11 Fix WiFi LED

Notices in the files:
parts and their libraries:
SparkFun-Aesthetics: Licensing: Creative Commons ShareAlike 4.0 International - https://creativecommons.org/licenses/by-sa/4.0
